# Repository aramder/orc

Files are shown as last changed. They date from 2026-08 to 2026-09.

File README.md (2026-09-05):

<div align="center">

<picture>
  <source media="(prefers-color-scheme: dark)" srcset="docs/media/banner-dark.svg">
  <source media="(prefers-color-scheme: light)" srcset="docs/media/banner-light.svg">
  ORC — Open Relay Controller
</picture>






**A replacement controller board for surplus Motorola PMUN1046A relay boxes — same relays and enclosure; open CAN control over plain terminal blocks instead of the proprietary wired link to the radio.**

Independent open-source project. Not affiliated with, endorsed by, or connected to Motorola Solutions, Inc. — see [TRADEMARKS.md](TRADEMARKS.md).

[**Project writeup and photos →**](https://aramd.net/PMUN1046A-Relay-Controller/)

**Safety:** this switches high-current DC in a vehicle. It is not safety qualified and must not be used for safety-critical functions. Read [DISCLAIMER.md](DISCLAIMER.md) before building anything.

</div>

---

## Why

The PMUN1046A **Universal Relay Controller (URC)** is a sealed 12 V automotive relay box — ten relay outputs at 15 A each, per-channel fusing, and a busbar power input rated for up to two cables at 60 A each (Motorola's install manual), in a trunnion-mounted weatherproof chassis. Power goes straight to the busbar through cable glands — no special harness needed on the input side. Surplus units are common and cheap. Everything about it is desirable *except* that it only takes commands from a Motorola APX radio over a proprietary GCAI/USB link.

ORC replaces the controller board outright and makes the box a general-purpose, openly-controlled ten-channel power distribution module. **ORC** stands for Open Relay Controller.

ORC does not implement, emulate, or interoperate with the GCAI link. The controller board is an independent design that replaces the donor unit's controller board entirely; control is plain CAN or USB.

<details>
<summary><b>About the donor unit</b> (PMUN1046A Universal Relay Controller)</summary>
<br>

Motorola's URC ships as part of the APX mobile radio ecosystem — a sealed relay box meant to switch scene lighting, sirens, and other accessory loads from the radio head. The relay board and chassis are generic 12 V automotive gear; only the controller board and its proprietary GCAI/USB command link to the radio are Motorola-specific. The relay board is entirely passive (relays, fuses, terminal blocks, busbar — no drivers or regulator of its own); a small internal harness carries switched 9 V coil drive between it and the controller board. Power input has no special harness at all — it lands straight on the busbar through the enclosure's cable glands. ORC keeps the relay board and chassis, and replaces the controller board and its proprietary radio link with plain CAN over terminal blocks — no proprietary connector anywhere in this design.

</details>

## What it is

<table>
<tr>
<td width="50%" valign="top">

**Inherited from the donor unit**
- Ten switched channels, 15 A each
- Per-channel fusing + busbar
- Board-to-board coil-drive harness (P/N `0975931M01`) — the internal cable between the relay board and the controller board, carrying switched 9 V coil drive; *not* a power-input harness
- Sealed, trunnion-mounted chassis

</td>
<td width="50%" valign="top">

**Rebuilt on the new controller board**
- ESP32-C3 controller (native USB for programming only; CAN-exclusive control, no wireless)
- 9 V relay coil supply
- Ten relay driver stages
- CAN terminal blocks (no proprietary connector)

</td>
</tr>
</table>

Category-wise this is a **PDM** (power distribution module) — the sPOD / Switch-Pros class of device — with an open CAN control interface instead of a proprietary wired link to the radio.

## The board

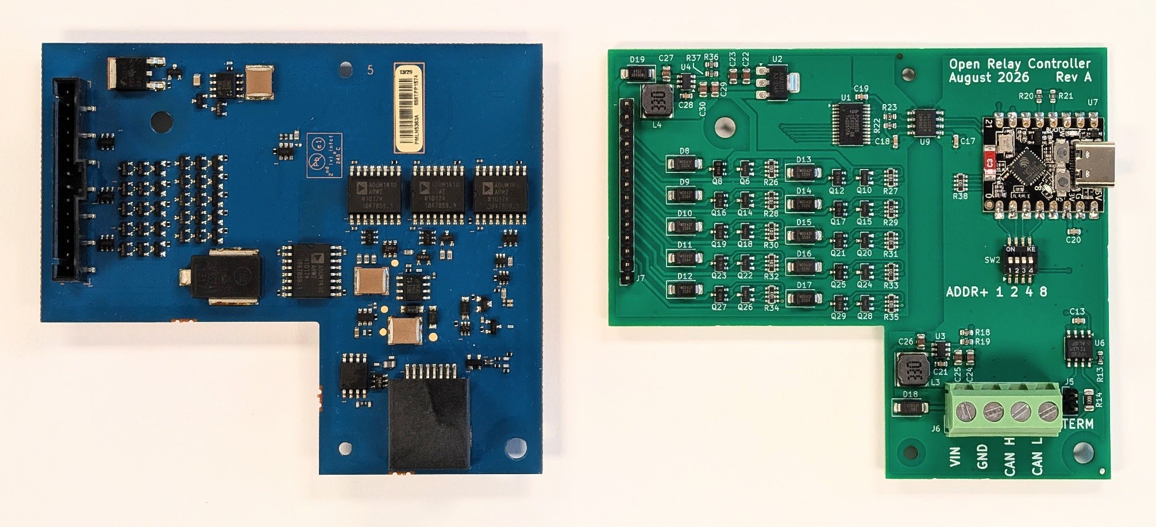
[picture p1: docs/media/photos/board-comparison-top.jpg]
ORC Rev A (green, right) next to the OEM PMUN1046A control PCB (blue, left), top-down


<em>ORC Rev A (green, right) and the OEM control PCB it replaces (blue, left).</em>

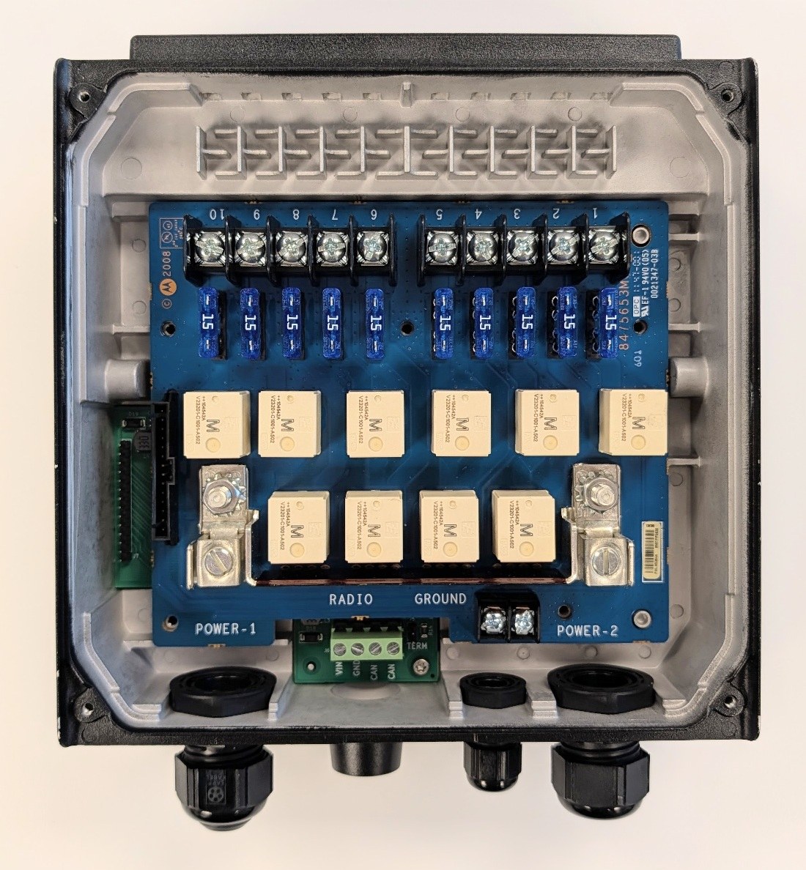
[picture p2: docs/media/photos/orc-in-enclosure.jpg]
ORC Rev A installed in the PMUN1046A enclosure alongside the OEM relay board


<em>ORC Rev A installed in the donor enclosure, alongside the OEM relay board that stays.</em>

**Full writeup, build story, and more photos:** [Open Relay Controller for the Motorola PMUN1046A](https://aramd.net/PMUN1046A-Relay-Controller/).

## Repo structure

One repo for design inputs, hardware, and firmware — no split-repo overhead for a project this size:

| Path | Contents | Status |
|---|---|---|
| `docs/` | Design inputs, specs, architecture decisions | Active |
| `hardware/` | KiCad project — schematic, PCB, BOM | Schematic captured, boards fabricated, populated, and bring-up verified on real hardware |
| `firmware/` | PlatformIO / Arduino firmware | `canopen_app` is real application firmware (CAN + USB relay control), verified on real hardware |
| `tools/` | Host-side CAN/USB bench test scripts | Used against real hardware |

## License

Different parts of the repo carry different licenses. Full texts are in [LICENSES/](LICENSES/); each directory also carries its own `LICENSE` file.

| Path | License |
|---|---|
| `hardware/` | [CERN-OHL-W-2.0](LICENSES/CERN-OHL-W-2.0.txt) |
| `firmware/`, `tools/` | [Apache-2.0](LICENSES/Apache-2.0.txt) |
| `docs/` | [CC-BY-4.0](LICENSES/CC-BY-4.0.txt) |

Hardware and software are licensed separately because they are separate works: under CERN-OHL's own definitions the ESP32-C3 is an Available Component, so a hardware license on the board does not reach the code running on it. See [NOTICE](NOTICE) for the summary and [TRADEMARKS.md](TRADEMARKS.md) for trademark and affiliation.

## Status

**Real-hardware bring-up complete.** Boards were sent to fab 2026-08-02, came back populated, and have been bench-tested since 2026-08-10: the PCA9555/I2C-isolator chain, the full 10-channel relay-driver mapping, and the CAN (RPDO1/TPDO1/TPDO2/Heartbeat) and USB control paths have all been exercised on real hardware. Five real firmware bugs were found and fixed along the way — BUG-001 through BUG-005, see [docs/features/LOG.md](docs/features/LOG.md) for the full history — the last of which (a liveness stall under an absent/unpowered PCA9555) was verified on real hardware 2026-09-04. One real mechanical fault (a harness connector shorting against the enclosure chassis) was also found and fixed on the bench — see [docs/circuit-draft.md](docs/circuit-draft.md) for the follow-up enclosure-clearance item.

No further active development is planned barring a new bug. A couple of feature requests (FR-003, FR-005) remain open in the backlog but aren't being actively pursued right now.

Working conventions for part selection, asset verification, and check gates: [docs/hardware-workflow.md](docs/hardware-workflow.md). Bench test tooling for talking to a real board over CAN/USB from a PC: [tools/](tools/).

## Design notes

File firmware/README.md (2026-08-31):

# ORC firmware

**Two kinds of content live here — don't conflate them.** The four `*_bringup`/`can_address_bringup` sketches exist to answer one narrow question — does the MCU pinout the hardware side has settled on actually work at the IO level? — before real application logic got written; see [`.claude/firmware-io-verification-prompt.md`](../.claude/firmware-io-verification-prompt.md) for that task. **`canopen_app` is different: it IS ORC's real application firmware** — actual relay control, driven from **either CAN or USB** against the same PCA9555 state, per [`docs/can-protocol-research.md`](../docs/can-protocol-research.md), [`docs/usb-bench-interface-spec.md`](../docs/usb-bench-interface-spec.md), and [`docs/features/FR-004.md`](../docs/features/FR-004.md). See its own section below.

**FR-004 (2026-08-10): USB control consolidated into `canopen_app`, the standalone `usb_bench` sketch retired.** Real bench testing the same day found `canopen_app`-only (CAN-only) and `usb_bench`-only (USB-only) too limiting for one board under active test with both interfaces in play — user's explicit ask: "I want to be able to drive from either CAN or USB interfaces." `usb_bench`'s protocol, findings, and fixes live on in `docs/features/FR-001.md` (marked superseded, not deleted) and in `canopen_app`'s own git history; there is no `[env:usb_bench]` anymore.

**Real ORC PCBs arrived and real-hardware testing started 2026-08-10.** Boards came back from fab, populated, and are being bench-tested for the first time. First real result, `i2c_scanner` on a powered, fully-wired ORC PCB: idle bus reads HIGH/HIGH (clean pull-ups, no strapping fault), CAN address bank correctly reads `0` with all four DIP switches open, and **the PCA9555 ACKs at 0x20** — the first-ever confirmation the ADuM1250 I2C isolator + PCA9555 chain works as designed on real fabricated hardware, not just static analysis. This also empirically confirms the GPIO2 boot-strap safety analysis (see "Configurable CAN node address, as-fabbed" below) for the DIP-switches-open position; the closed/HIGH position on GPIO2 hasn't been walked yet. SN65HVD230/real-CAN-bus testing hasn't happened yet as of this pass. **Still true for now**: don't read "runs on a generic ESP32-C3 dev kit" (below) as equivalent to "verified on the real ORC board" — but as of today, real-board testing is actively underway, replacing that caveat's earlier "no board in hand at all" state. Update this section as each sketch gets its first real-PCB run, don't leave it reading like nothing has changed once it has.

**History, for context**: the board was sent to fab 2026-08-02 and came back some time before this pass. All five firmware environments (`i2c_scanner`, `pca9555_bringup`, `uart_can_bringup`, `can_address_bringup`, `canopen_app`) build successfully against the `esp32-c3-devkitm-1` stand-in board. Two of them (`i2c_scanner`, `uart_can_bringup`) also ran live on a bare, generic ESP32-C3 dev kit before any ORC PCB existed — see "Real-hardware run, 2026-08-01" below for exactly what that did and didn't confirm (nothing PCA9555/SN65HVD230-related). `canopen_app` (as `usb_bench` too, before it was retired into `canopen_app` by FR-004) found and fixed a real bug (halting `setup()` before relay-agnostic functionality ACKed, taking bus-agnostic functionality down with it — BUG-001) on a bare devkit before any ORC PCB was available. **Firmware's pin assignment was corrected once, same day it was sent to fab** — see "CAN node address, as-fabbed" below; the schematic is the source of truth firmware must match, not the other way around.

## Board stand-in

`platformio.ini` targets PlatformIO's `esp32-c3-devkitm-1` board definition. This is a **stand-in**, not the final hardware — the actual target is a generic, widely-cloned "ESP32-C3 Super Mini"-class board (bare ESP32-C3FN4 die, 4MB flash, no PSRAM, USB-C, 2×7-pin THT headers) with no single confirmed SKU yet. `esp32-c3-devkitm-1` is electrically close enough (same chip class) to compile and flash against for IO-level bring-up; swap it for a real board definition once a specific listing is bought and its exact silkscreen/pin breakout is confirmed.

## Pin assignment under test

Per `hardware/mcu.kicad_sch` (U7, as-fabbed) and `docs/subcircuit-capture-guide.md`'s MCU section — full 13-GPIO "Super Mini" header pinout (GPIO0-10, GPIO20, GPIO21):

| Function | Pins |
|---|---|
| I2C (SDA/SCL) | GPIO8 / GPIO9 |
| UART (TX/RX, to SN65HVD230) | GPIO21 / GPIO20 |
| CAN node address (NODE_ID0-3) | GPIO0 / GPIO1 / GPIO2 / GPIO3 |
| Spare (unused) | GPIO4-7 (JTAG-default), GPIO10 |

## Configurable CAN node address, as-fabbed

4-bit node address (0-15), read directly by the ESP32-C3 — deliberately **not** through the PCA9555, since address-select logic belongs on the MCU's own non-isolated Domain A side, not across the ADuM1250 isolation barrier onto Domain B where the PCA9555 lives. Shared logic lives in `lib/orc_can_addr/` and is linked into every sketch below, each printing the current reading at startup.

**Wiring**: external 10kΩ pulldown to GND per bit, switch/jumper to 3V3 per bit — open=0 (LOW), closed=1 (HIGH). Plain `INPUT` mode in firmware (no internal pull requested); the external 10k dominates the ESP32-C3's own internal weak pull resistors (~45kΩ typ either direction per the datasheet) regardless of their state, so there's nothing to fight.

**Pins actually built: GPIO0, GPIO1, GPIO2, GPIO3 — corrected after the fact, not the original plan.** The initial pick (documented 2026-08-02, before the board went to fab) was GPIO0/1/3/10, specifically chosen to avoid GPIO2 since it's one of the ESP32-C3's three strapping pins. **That was never what got built.** The as-fabbed schematic (`hardware/mcu.kicad_sch`, U7) wires `NODE_ID0`..`NODE_ID3` to a contiguous `IO0`..`IO3` block — which includes GPIO2 and doesn't use GPIO10 at all. This firmware has been corrected to match the real board; the schematic is the source of truth here, not the firmware plan.

**GPIO2 strapping safety — re-verified with real rigor since it's now load-bearing on a board that's already at fab, not just a design preference to weigh.** The ESP32-C3's full strapping-pin set is exactly {GPIO2, GPIO8, GPIO9} (Espressif *ESP32-C3 Series Datasheet* v2.4, Table 3-1/3-2/3-3). Table 3-3 "Chip Boot Mode Control" has exactly two rows:

| Boot Mode | GPIO2 | GPIO8 | GPIO9 |
|---|---|---|---|
| SPI Boot (normal) | Any value | Any value | 1 |
| Joint Download Boot | 1 | 1 | 0 |

— with the table's own footnote stating plainly: *"GPIO2 actually does not determine SPI Boot and Joint Download Boot mode, but it is recommended to pull this pin up due to glitches."* This board's I2C pull-up (R21, `SCL_A`, 10kΩ — see `docs/subcircuit-capture-guide.md`'s I2C Isolator section) holds **GPIO9 = 1 at every reset**, which is the sole determinant of the SPI-Boot row. Both address-switch positions on GPIO2 (LOW via the external 10k pulldown when open, HIGH when closed) land in that same SPI-Boot row regardless — GPIO2's column is "Any value" whenever GPIO9=1, and GPIO9=1 is guaranteed here. No published ESP32-C3 errata mention GPIO2 (checked directly against Espressif's chip errata index, not assumed absent by analogy to GPIO8/9). **Verdict: safe as fabbed, no rework needed.** Espressif's own generic recommendation to add a pull-up on GPIO2 (to guard against glitches on a *floating* GPIO2 in designs where GPIO9 isn't independently pinned) doesn't apply here in the same way, since this design's own pull-down plus GPIO9's independent pull-up together determine the outcome regardless of GPIO2's transient state.

GPIO0/1/3 are also ADC1_CH0/CH1/CH3 — irrelevant here since they're used purely as digital inputs, not sampled by the ADC. GPIO10, spare in this design, was the original plan's bit3 pin but isn't actually wired to anything address-related on the real board.

## The GPIO9 strapping question — resolved

GPIO9 is the ESP32-C3's BOOT strapping pin (default weak pull-up = normal SPI-flash boot) and is also assigned as I2C SCL. **Datasheet analysis verdict: safe, no conflict.** Full reasoning and citations now live in `docs/subcircuit-capture-guide.md`'s MCU section; summary:

- The boot-strap read is a one-shot latch completing within a fixed **t_H ≥ 3 ms** window anchored to `CHIP_EN` release (Espressif *ESP32-C3 Series Datasheet* v2.4, §3, Table 3-2, Figure 3-1) — before firmware runs and before the IO MUX/GPIO Matrix has routed the I2C peripheral onto GPIO8/9 at all (same datasheet, §4.1.3.1; Table 2-1 shows GPIO9's at-reset/after-reset state as plain `IE, WPU`, not an I2C pin).
- An idle-high I2C bus **reinforces** GPIO9's documented default pulled-up strap value (Table 3-1: GPIO9 default = weak pull-up, bit=1=SPI boot); external pull-ups are the datasheet's own documented mechanism for setting strap state and are not flagged as a hazard when they match the default direction.
- The only way to disturb the strap read is to actively drive GPIO9 **low** during the ~3 ms window — ordinary I2C only pulls SCL low during active clock pulses initiated by firmware, which cannot run before the strap read has already completed and been latched.
- No published ESP32-C3 errata mentions GPIO8/GPIO9/strapping/I2C (checked against Espressif's official chip errata index).
- GPIO8 (SDA) is also a strapping pin (chip-boot-mode + UART-print-control), defaults to **floating** (not pulled), and is safe by the same timing argument. One real caveat carried into the docs: GPIO8's floating default means if some other I2C slave on the bus holds SDA low during its own power-on reset at the same instant as the ESP32-C3's `CHIP_EN` release, that could unintentionally affect the GPIO8 strap read (Table 3-3: only matters if GPIO9 also reads 0 at that instant) — a general I2C power-sequencing caution, not specific to this design, and not a reason to reassign pins.

No pin reassignment was made. If a strapping-pin-free I2C pair is ever wanted for unrelated reasons, GPIO4/5 or GPIO6/7 avoid the {GPIO2, GPIO8, GPIO9} strap set but carry JTAG (MTMS/MTDI/MTCK/MTDO) as their IO-MUX default association — a different caution category, and not verified against this design's specific "Super Mini" header breakout.

## SN65HVD230 UART baud rate

The SN65HVD230 CAN transceiver has **no UART framing requirement of its own** — it's a transparent ISO 11898-2 physical-layer line driver, not a UART part (TI *SN65HVD230/1/2* datasheet, SLOS346O, rev. April 2018: §7 Pin Functions, §10.1 Overview). Its datasheet gives a "designed for data rates up to 1 Mbps" target (Features, p.1) and hard propagation-delay/rise-time limits in high-speed mode (§8.7–8.9, tens-to-~135 ns depending on the parameter) — not a baud spec. `uart_can_bringup` picks 500 kbps as a conventional round number comfortably under that ceiling; it is a firmware-side choice, not a transceiver requirement. **Caveat**: those propagation-delay numbers assume RS (slope-control) tied to ground for high-speed mode — if ORC's board leaves RS in slope-control mode via a resistor instead, propagation delay balloons (up to ~1200 ns typ at 100 kΩ RS per the datasheet's switching-characteristics table) and would cap the practical rate well below 1 Mbps. Confirm ORC's actual RS pin configuration before assuming the 1 Mbps ceiling applies.

## Real-hardware run, 2026-08-01

A bare, generic ESP32-C3 dev kit (chip ID reported by `esptool`: **ESP32-C3 QFN32, silicon revision v0.4**, 4MB embedded flash, native USB-Serial/JTAG, MAC `3c:84:27:af:48:fc`) was connected to the machine this session ran on, with **nothing else wired to it** — no PCA9555, no SN65HVD230, no I2C pull-ups beyond whatever the bare board itself has. This is not ORC's board and does not exercise the PCA9555 or CAN-transceiver bring-up logic; it confirms the ESP32-C3 IO-level pieces (I2C peripheral init, UART peripheral init, USB console) actually run on real silicon of the correct chip family.

**Bug found and fixed by this test, not cosmetic**: the stock `esp32-c3-devkitm-1` board definition does not enable USB-CDC-on-boot, so Arduino's default `Serial` console silently bound to UART0 on **GPIO21(TX)/GPIO20(RX) — the exact pins this design assigns to the CAN-transceiver UART** — instead of the native USB-Serial/JTAG port. First flash produced zero console output for this reason. Fixed in `platformio.ini` with `-D ARDUINO_USB_MODE=1 -D ARDUINO_USB_CDC_ON_BOOT=1`, which routes `Serial` onto native USB and frees GPIO21/20 exclusively for the CAN UART (`Serial1`) as intended. Worth carrying into whatever final board definition replaces the `esp32-c3-devkitm-1` stand-in — the same collision would otherwise resurface silently on real ORC hardware.

- **`i2c_scanner`**: flashed and ran live. Correctly reported no ACKs on the bus (expected — nothing is wired to GPIO8/9 on this bare dev kit) and printed the idle-bus-level check without error. Confirms the I2C peripheral initializes and runs on real hardware; does not confirm anything about the PCA9555 (not attached).
- **`uart_can_bringup`**: flashed and ran live. Baseline (nothing jumpered) correctly showed "RX: nothing received" every cycle. With GPIO21 (TX) physically shorted to GPIO20 (RX) by a jumper wire, **loopback verified end-to-end**: every `ORC-BRINGUP-<counter>` pattern sent came back byte-for-byte (22 bytes including `\r\n`), one-to-one, no drops or corruption, at 500 kbps. Confirms UART1 on these exact pins transmits and receives correctly on real silicon; does not confirm anything about the SN65HVD230 or a real CAN bus (neither present).
- **`pca9555_bringup`**: not run this session — no PCA9555 is attached to this dev kit. By design it halts cleanly at the "PCA9555 did not ACK" check rather than doing anything unsafe without the part present; still only build-verified, not run.

## Real-hardware run, 2026-08-10 — first test against an actual ORC PCB

Real, populated, powered ORC PCBs are in hand as of this pass — the first real-hardware test against the design this whole directory has been targeting, not a bare devkit stand-in. First board wired up and tested via `i2c_scanner`, flashed to a bare ESP32-C3 module wired to the board (COM7, `esptool`-reported chip ID: ESP32-C3 QFN32 silicon revision v0.4, MAC `AC:27:6E:45:90:98` — a different unit than the 2026-08-01 run's `3c:84:27:af:48:fc`).

Live boot output:

```
=== ORC bring-up: I2C bus scanner ===
SDA=GPIO8  SCL=GPIO9  expected PCA9555 addr=0x20
CAN node address: 0 (bits 3210 = 0000, pins GPIO3/2/1/0)
Idle bus levels before Wire.begin(): SDA(GPIO8)=HIGH  SCL(GPIO9)=HIGH
Both lines read HIGH at idle -- normal.

Scanning I2C bus (addresses 0x03-0x77)...
  ACK at 0x20  <-- expected PCA9555 address
1 device(s) found.
```

**Confirms, for the first time on real fabricated hardware, not static analysis or a bare-devkit substitute**:
- **PCA9555 ACKs at 0x20.** The ADuM1250 I2C isolator + PCA9555 chain works as designed, crossing the Domain A/B isolation barrier for real.
- **GPIO2 boot-strap safety, empirically confirmed for the DIP-switches-open position**: bus idles HIGH/HIGH, board boots and runs normally with GPIO2 (a strapping pin) held at its address-bank LOW/open state. This is the predicted-safe outcome from the Table 3-3 datasheet analysis (see "Configurable CAN node address, as-fabbed" below), now observed on real silicon instead of just argued from the datasheet. **Not yet walked**: the CLOSED/HIGH position on GPIO2 specifically — the analysis says it lands in the same safe boot-mode row, but that position hasn't been physically tested yet.
- **CAN node address bank reads correctly**: `0` with all four DIP switches open, matching the external-pulldown design (open = LOW = 0).

**`pca9555_bringup` confirmed shortly after, same session**: flashed to the same board, ran its full 10-channel walking pattern, user cross-checked every channel with a DMM in continuity mode on the coil harness pins — all 10 correct, no swaps, no misses. First end-to-end confirmation of the routing-driven channel-mapping table (schematic → `orc_relay_map.h` → real silicon → real coil driver → real relay) on actual hardware, not just internal firmware/schematic consistency. Full writeup: `pca9555_bringup`'s own section below.

**Real hardware fault found and fixed, same session — mechanical, not electrical design.** A second board (or second connection session) showed relays only weakly actuating (faint click, not enough force to close contacts) and I2C throwing driver-level errors partway through the run. Chased through several hypotheses (PCA9555 brownout-reset from coil inrush, then a wedged I2C bus) before the user found the real cause by physical inspection: **the harness connector's unshrouded THT pins were shorting against the metal enclosure chassis.** One electrical fault, two symptoms — the short sagged shared supply rail(s) under coil-switching current, starving coil drive and glitching the PCA9555's own logic supply at the same time. Not a coil-supply sizing problem, not a firmware bug. Full writeup and the follow-up mechanical-clearance item: `docs/circuit-draft.md`'s "Harness connector — measured pinout" section. `pca9555_bringup`'s own periodic-PCA9555-reconfigure defensive hardening (added while chasing this) stayed in as cheap insurance; an I2C bus-recovery attempt added at the same time was tested live, found not to actually work on this Arduino-ESP32 core's I2C driver, and removed rather than left in as broken code claiming success — see the sketch's own comments for the full chase.

**FR-004, same session, later**: user asked for USB control to be built into `canopen_app` itself rather than living only in the separate `usb_bench` sketch, so relays could be driven from either interface against the same board. `usb_bench` retired; its protocol/fixes consolidated into `canopen_app` — see that section below and `docs/features/FR-004.md`. `canopen_app` (with USB now built in) then drove all 10 channels ON over USB directly on this real board: real coil current confirmed (0.47A at 12V input, matching the ~0.45A design target almost exactly), all 10 relays audibly/visibly actuated. One test-tooling false alarm along the way, not a firmware bug: a Python test script's `pyserial.Serial.close()` call toggled the native-USB-CDC auto-reset lines (the same RTS mechanism `esptool` uses for flashing) and rebooted the chip, which looked like "the relays turned off after ~1 second" but was actually a full reset wiping all state back to boot defaults — confirmed by re-running the same test with the port kept open for 15+ seconds: heartbeat counted up smoothly the whole time, zero reboots, all 10 channels held.

**`canopen_app` CAN side, tested and a real bug found and fixed, 2026-08-10.** Bench-tested end-to-end against real hardware (real ORC board, Jhoinrch RH-02 USB-CAN adapter, `tools/relay_toggle_test.py`'s 1-10 sweep + all-on): the RPDO1 command path worked correctly from the first run (relays physically confirmed clicking through in sequence), but TPDO1 confirmation was unreliable in a specific pattern — roughly every other TPDO1 missing, survivors reporting the previous step's mask. Root cause, found by reading the Arduino-ESP32 native-USB-CDC (`HWCDC`) driver source directly, not assumed: `handleRpdo1()` logs the incoming RPDO1 via `Serial.printf()` *before* `applyRelayCommand()` sends TPDO1, and a blocking native-USB write can stall up to ~2000ms (20 retries × 100ms default `tx_timeout_ms`) if the physical USB link is up but nothing drains the ring buffer — longer than the test's 2s confirm window, and nothing to do with CAN bus health (a bus-health theory was tested first and directly refuted: TEC held at 0 for 10+ seconds through a full sweep, termination confirmed correctly populated, symptom unchanged). Fix: `setup()` now calls `Serial.setTxTimeoutMs(20)`, bounding any blocking `Serial` write to ~200ms. Re-verified against the reflashed board: 12/12 sweep steps confirmed. Full investigation trail: `.claude/tpdo1-lag-investigation-prompt.md` (gitignored, local only).

`uart_can_bringup` itself has not been separately re-run against this same setup — `canopen_app` (the real application firmware) has now been validated on both CAN and USB against real hardware, `uart_can_bringup` (an earlier bring-up-only sketch) is superseded for that purpose.

## Sketches

Each sketch is its own PlatformIO environment (separate, individually-flashable — not one monolithic test). Build/flash one at a time:

```
pio run -e i2c_scanner -t upload -t monitor
pio run -e pca9555_bringup -t upload -t monitor
pio run -e uart_can_bringup -t upload -t monitor
pio run -e can_address_bringup -t upload -t monitor
pio run -e canopen_app -t upload -t monitor
```

(Run from this `firmware/` directory. `-t monitor` opens the serial console at 115200 baud after flashing; omit it to just build+flash.)

### `i2c_scanner` ([src/i2c_scanner/main.cpp](src/i2c_scanner/main.cpp))

Scans the I2C bus (addresses 0x03–0x77), reports any device that ACKs — specifically flags 0x20, the PCA9555's address (A0–A2 strapped low). Before starting the I2C peripheral, reads SDA/SCL as plain GPIO to report whether the bus idles HIGH (normal) or LOW (a real fault — stuck bus, missing pull-up, or a device holding the line; the classic symptom anyone chasing a strapping-conflict theory would look for, though per the analysis above it isn't expected to be one here).

### `pca9555_bringup` ([src/pca9555_bringup/main.cpp](src/pca9555_bringup/main.cpp))

Configures the PCA9555 as 10 outputs and walks a single HIGH bit across channels 1–10 in sequence, 500 ms per step, using the **real, schematic-confirmed channel-to-register mapping** in `lib/orc_relay_map/`. Intended for a scope probe or a per-channel LED jig to visually confirm addressing and pin mapping once hardware exists. **Corrected 2026-08-05**: an earlier version of this sketch assumed channels 1-8 were sequential on Port0 (whole byte) with channels 9-10 on Port1's low 2 bits — that assumption was wrong. `docs/subcircuit-capture-guide.md`'s "Channel mapping" table (read directly off `hardware/i2c_expander.kicad_sch`) shows the real mapping is routing-driven and non-sequential, spanning both ports (e.g. channel 1 = Port1 bit0, channel 2 = Port0 bit7, channel 10 = Port0 bit3). "Channel 3" in this sketch's output now means the schematic's actual channel 3.

**Real-hardware confirmed, 2026-08-10**: flashed to a real, powered ORC PCB and run through its full walking pattern. User followed along with a DMM in continuity mode on the coil harness pins and confirmed all 10 channels click in the correct physical position, matching the printed `Channel N HIGH` output exactly — no swaps, no misses. This is the strongest verification the channel-mapping table has had: schematic → `orc_relay_map.h` → real silicon → real coil driver stage → real relay, checked end to end. Full writeup: `docs/subcircuit-capture-guide.md`'s "Channel mapping" section.

### `uart_can_bringup` ([src/uart_can_bringup/main.cpp](src/uart_can_bringup/main.cpp))

Configures UART1 at 500 kbps on GPIO21(TX)/GPIO20(RX) — the pins wired to the SN65HVD230 — sends a counted test pattern (`ORC-BRINGUP-<counter>`) once per second, and reports whatever arrives on RX within a 500 ms window. Useful for a bench loopback test (jumper TX to RX, or through the transceiver with CAN_H/CAN_L looped/terminated) before a real bus exists, and for testing against a second node once one does. This is raw UART bytes through the transceiver, not CAN-protocol-framed traffic.

### `can_address_bringup` ([src/can_address_bringup/main.cpp](src/can_address_bringup/main.cpp))

Reads the 4-bit CAN-address bank (GPIO0/1/2/3, see "Configurable CAN node address, as-fabbed" above) and prints the resulting 0-15 value once per second, along with each individual bit. Intended for a bench check: walk all 16 switch combinations and confirm each one reads back correctly before trusting the scheme in the field. The other bring-up sketches also call the same `orcPrintCanAddress()` helper (from `lib/orc_can_addr/`) once at startup, so whichever one is running, the console banner always states which node address the board is currently set to — useful as soon as more than one ORC unit might be on a bench or bus at once.

## `canopen_app` — application firmware: relay control from CAN or USB

**This is real relay-control firmware, not a bring-up test.** Implements the full CAN protocol specified in `docs/can-protocol-research.md`: real CAN (TWAI, not the `uart_can_bringup` UART scheme), 125 kbit/s, node-ID-based addressing (reuses `lib/orc_can_addr` unchanged), and four messages — RPDO1 (relay command), TPDO1 (relay status), TPDO2 (bus health/uptime), Heartbeat — plus one minimal SDO object for TPDO2's configurable send interval. **FR-004 (2026-08-10) added a second, equally real control path**: the same plain-ASCII USB protocol `docs/usb-bench-interface-spec.md` defines, previously its own separate `usb_bench` sketch (now retired) — `PING`/`VERSION`/`SET`/`GET`/`STATUS` plus unsolicited `HB`/`STATE` lines, driving the *same* PCA9555 state as CAN does. Real ORC boards are in hand and under active bench test as of 2026-08-10 (see the top status note above) — this firmware found and fixed a real-hardware bug (BUG-001, same halt-on-missing-PCA9555 class `usb_bench`'s FR-001 also hit) on a bare devkit before an ORC PCB was available, and has since driven all 10 real relays over USB on the real board (0.47A real coil current, matching the ~0.45A design target).

```
pio run -e canopen_app -t upload -t monitor
```

**Transport**: ESP-IDF/Arduino-ESP32's native TWAI driver (`driver/twai.h`), `tx_io=GPIO21`, `rx_io=GPIO20` — the same physical pins `uart_can_bringup` uses, but a genuinely different on-chip peripheral (TWAI vs UART1), per `can-protocol-research.md`'s UART-vs-TWAI resolution: TWAI has no dedicated IO_MUX pin on the ESP32-C3, it's GPIO-Matrix-routable to any pin, so this is a firmware-only change with zero schematic impact. Given separate `ORC_TWAI_TX_PIN`/`ORC_TWAI_RX_PIN` build flags (same values as `ORC_UART_TX_PIN`/`RX_PIN`) rather than reusing the UART-named constants, since reusing them here would misleadingly suggest this sketch is still UART-based. **Bitrate: 125 kbit/s, locked** (`TWAI_TIMING_CONFIG_125KBITS()`) — per `can-protocol-research.md`'s "Bus bitrate" section; don't change this without updating that doc and coordinating with `rigos-core`'s FR-059, which is being built against this exact value from the host side.

**Node ID**: read via `lib/orc_can_addr` at startup, unchanged from the bring-up sketches. **If the address reads 0** (all 4 DIP-switch positions open — not a valid CANopen node ID, CiA 301 requires 1-127), CAN is disabled for that session (no heartbeat, TPDO1/TPDO2, RPDO1, or SDO) rather than silently joining the bus non-conformantly — **but the sketch keeps running and USB control still works normally**, per FR-004's proactive fix (see below): a missing node ID used to halt the *entire* sketch before this pass, which would have taken USB down with it too, defeating the whole point of having two independent interfaces.

**Messages implemented** (COB-ID = base + NodeID, see `can-protocol-research.md` for the full spec):

| Message | COB-ID | Direction | What it does |
|---|---|---|---|
| RPDO1 | `0x200+NodeID` | host → ORC | 2-byte relay command (byte0=channels 1-8, byte1 bits0-1=channels 9-10) — this is the **wire protocol's** channel numbering, translated to real PCA9555 register bits via `lib/orc_relay_map/`'s schematic-confirmed, routing-driven mapping (channels are NOT sequential Port0-then-Port1 bits — see `pca9555_bringup`'s section above for the same correction). `orc_canopen.h` only handles the 2-byte-payload ↔ 10-bit-channel-mask conversion; `orc_relay_map.h` handles channel-mask ↔ PCA9555-register-value, kept as two separate, composable translation steps. |
| TPDO1 | `0x180+NodeID` | ORC → host | 2-byte applied relay status, sent after **any** real applied-state change — not only ones RPDO1 itself caused (FR-004: a USB `SET` command now also triggers a TPDO1 broadcast, so a CAN listener's view of applied state stays truthful regardless of which interface changed it). Read back from the PCA9555's Input Port registers (which reflect actual driven pin level even for output-configured pins) rather than just echoing the command — real command-vs-applied confirmation, even without current sensing. |
| TPDO2 | `0x280+NodeID` | ORC → host, periodic (default 1000ms, SDO-configurable) | 8-byte bus health/uptime: byte0 CAN-controller-health enum, bytes1-2 TWAI TX/RX error counters, bytes3-6 uptime-seconds (`uint32` little-endian), **byte7 relay-hardware fault bitmask (FR-002, 2026-08-31 — bit0 = PCA9555 absent/unpowered, mirrors `g_pca9555Present`; was reserved/always-0 before this)**. Byte-0 enum and error-counter width were both flagged in `can-protocol-research.md` as unverified design sketches — **both confirmed this pass against ESP-IDF's actual `driver/twai.h`** (see that doc's TPDO2 section for the citation), implemented in `lib/orc_canopen/orc_canopen.h`. **Uptime bug found and fixed in 2026-08-05 review**: the field was originally computed from `millis()`, which wraps at ~49.7 days and would have silently reset the reported uptime on any continuously-powered unit — now uses `esp_timer_get_time()` (64-bit microseconds-since-boot), which doesn't have that problem. |
| Heartbeat | `0x700+NodeID` | ORC → host, periodic, fixed 1000ms | 1-byte NMT state. Sends Boot-up (0) once at the end of `setup()`, then Operational (5) on every subsequent periodic send — a fixed "Boot-up once, then always Operational" NMT posture, no Stopped/Pre-operational transitions implemented, stated explicitly rather than silently skipped. |
| SDO (minimal) | rx `0x600+NodeID`, tx `0x580+NodeID` | host ↔ ORC | Recognizes exactly one (index, sub-index) pair — `1801h`/`5`, TPDO2's event timer in milliseconds — and aborts (standard CiA 301 abort codes) anything else. Not a general SDO server, per the task's explicit scope. A successful write applies the new interval immediately and persists it to the ESP32-C3's NVS (`Preferences`, namespace `orc_cfg`, key `tpdo2_ms`) so it survives a power cycle; default 1000ms if nothing's been persisted yet. |

**Control-activity fail-safe, now unified across both interfaces (FR-004)**: if neither CAN (RPDO1) nor USB (any command) produces real activity within a threshold, all channels are de-energized rather than holding last state — per `can-protocol-research.md`'s explicit safety recommendation, now extended to cover USB too. **Two thresholds, not one, and picked by which interface was most recently active, not a single shared clock**: 5000ms after CAN activity (the original RPDO1-timeout value — not a cited spec value, picked as 5x the TPDO2/Heartbeat default period), 30000ms after USB activity (ported from `usb_bench`/FR-001's own reasoning — a human typing pauses far longer than a machine's command cadence). A naive single shared last-activity timestamp checked against both thresholds does NOT correctly implement "either interface's activity postpones both" — since 5000 < 30000, the shorter threshold always fires first on a shared clock, making the 30s USB grace period unreachable dead code. Tracking *which* interface supplied the most recent activity and selecting the threshold from that avoids this: a pure-CAN session keeps the strict 5s fail-safe, a pure-USB session gets the full 30s grace, and either interface's activity postpones the other's countdown. See `docs/features/FR-004.md` for the full reasoning.

**TWAI bus-off recovery**: added in the 2026-08-05 review pass — was missing entirely from the original implementation. ESP-IDF's TWAI driver does not recover from bus-off on its own: `twai_initiate_recovery()` must be called explicitly, and even after recovery completes the driver lands in `STOPPED`, not `RUNNING` — `twai_start()` must be called again to actually resume. Without this, a bus fault would be correctly *reported* via TPDO2's health byte (`BUS_OFF`/`RECOVERING`) but never actually recovered from, needing a physical power-cycle. `checkTwaiRecovery()` runs on a fixed 1-second cadence (independent of TPDO2's own SDO-configurable interval, deliberately) and handles both the `twai_initiate_recovery()` call and the follow-up `twai_start()`.

**Not implemented, by explicit scope choice, not oversight**: EMCY (`0x080+NodeID`) — flagged in the spec as a stretch goal, skipped this pass. Full `1010h`/`1011h` CANopen store/restore objects — the NVS auto-persist-on-write above satisfies "survives a power cycle" without them; a reasonable later addition if ORC ever needs to interoperate with a generic CANopen config tool expecting the standard mechanism specifically. No general-purpose CANopen stack or object dictionary — the message set is small and fully specified, hand-rolled directly on the TWAI driver per the task's explicit instruction not to pull in a library (e.g. CANopenNode) for this.

**Shared libraries**: `lib/orc_canopen/orc_canopen.h` — pure wire-protocol encode/decode helpers (COB-ID arithmetic, RPDO1/TPDO1 2-byte-payload ↔ 10-bit-channel-mask, TPDO2 payload packing, the one-object SDO wire format). `lib/orc_relay_map/orc_relay_map.h` — the real, schematic-confirmed channel-mask ↔ PCA9555-register-value mapping, shared with `pca9555_bringup` (see its section above). Splitting these two translation steps (protocol bytes ↔ channel mask, channel mask ↔ PCA9555 registers) into separate libs is deliberate — it's what let the routing-driven mapping bug get caught and fixed in one place without touching the wire-protocol format at all. Neither lib makes TWAI/I2C/NVS calls of its own; `canopen_app/main.cpp` owns the actual peripherals and runtime loop. Both header-only, no `.cpp` — everything's a small `inline` function.

### USB control (FR-004, formerly the standalone `usb_bench` sketch)

Same physical native USB-C port already wired for flashing, same plain-ASCII protocol `docs/usb-bench-interface-spec.md` defines — **now built into `canopen_app` directly**, driving the same PCA9555 state CAN does, not a separate binary. ORC's resolved control-path decision (`docs/design-inputs.md`) — CAN, exclusively, in the field — is unchanged; USB remains explicitly a bench/dev interface, just one that now lives in the real firmware instead of a throwaway sketch.

**Transport/framing**: native USB CDC-ACM (`Serial`), same `ARDUINO_USB_MODE`/`ARDUINO_USB_CDC_ON_BOOT` build flags every sketch here sets. Plain ASCII, one command/response per line, `\n`-terminated (`\r` tolerated/stripped), 128-byte max line length (`ERR LINE_TOO_LONG` past that), case-insensitive commands. Point-to-point by construction — no NodeID concept on the USB side, unlike CAN.

**Commands** (exactly per the spec):

| Command | Response | Notes |
|---|---|---|
| `PING` | `PONG <fw_version>` | Liveness + identify. Works even with CAN unjoined or no PCA9555 present. |
| `VERSION` | `VERSION <fw_version> <build_date>` | Fuller build info. |
| `SET <ch> ON\|OFF` | `OK SET <ch> ON\|OFF` or `ERR <code>` | `<ch>` is 1-10. Goes through the same `applyRelayCommand()` RPDO1 uses — a CAN listener sees a TPDO1 for this too. |
| `GET <ch>` | `STATE <ch> ON\|OFF` or `ERR <code>` | Applied state, PCA9555 Input Port read-back, not an echo of the last command. |
| `STATUS` | `STATUS <10-char 0/1 string>` | Channel 1 first, e.g. `STATUS 0010000000` = channel 3 on. |

**Unsolicited lines**: `HB <uptime_ms>` every 1000ms (always, regardless of whether CAN is joined); `STATE <ch> ON\|OFF` on every real applied-state change from *either* interface (CAN RPDO1, USB SET, or the fail-safe) — one shared read-back feeds both this and CAN's TPDO1 broadcast, so neither interface's view of reality can silently drift from the other's.

`SET`/`GET`/`STATUS` attempt a lazy on-demand PCA9555 re-probe if hardware wasn't previously known-present (ported from `usb_bench`/FR-001), returning `ERR NO_RELAY_HARDWARE` only if that also fails — same treatment `handleRpdo1()` now gets too, which it didn't have before this consolidation (BUG-001 only stopped it from halting the whole sketch, it never re-probed after boot).

**Known limitation, documented not silently accepted (FR-004)**: this file's Serial output was always a human debug log (RPDO1 dumps, TWAI errors, SDO writes, etc.), not the strictly line-clean protocol `usb_bench` alone was. That debug prose is now interleaved with the real protocol lines on the same port — a host-side parser MUST tolerate/ignore unrecognized lines, extending the spec's existing "check first token" robustness requirement to cover diagnostic prose too, not only other protocol lines.

**Real-hardware gotcha, not an ORC feature**: closing a serial connection (e.g. `pyserial`'s `Serial.close()`) can toggle the DTR/RTS lines the native-USB-CDC auto-reset mechanism watches — the same one `esptool` uses to flash without a physical BOOT button — and trigger a full chip reboot, wiping all state including energized relays. Confirmed live 2026-08-10: a test script's port-close looked exactly like "relays turned off after ~1 second," but a 15-second open-port re-test with the same commands showed zero reboots and all channels holding the whole time. Any host-side driver against this interface should keep the port open for its session, not open/close per command.

**Retired, not deleted**: the standalone `usb_bench` sketch/environment. Its full history — the FR-001 reopen, the PCA9555-gate bug, the fix, the real-hardware re-verification — lives in `docs/features/FR-001.md` (marked superseded) and this repo's git history, not silently erased.

## What this is not

- **The four bring-up sketches** (`i2c_scanner`, `pca9555_bringup`, `uart_can_bringup`, `can_address_bringup`) are not application firmware — no relay control logic, no real CAN message parsing/handling, no product behavior. `canopen_app` is different — see its section above — but that's not a claim of hardware verification (next point).
- **Updated 2026-08-10 — real ORC boards exist now, status per sketch**: `i2c_scanner` and `pca9555_bringup` have both run live on a real, powered, fully-wired ORC PCB. `i2c_scanner`: PCA9555 ACKed at 0x20, idle bus HIGH/HIGH, CAN address bank read correctly. `pca9555_bringup`: full 10-channel walking pattern run, user-verified with a DMM in continuity mode against the coil harness — all 10 channels correct, no swaps, no misses. `canopen_app` (USB side): drove all 10 real relays ON, 0.47A real coil current confirmed, matching the ~0.45A design target. `canopen_app` (CAN side) and `uart_can_bringup` have not yet been re-run against the real board/real SN65HVD230/a real CAN bus (a transceiver is being wired up as of this pass) — only the earlier bare-devkit/build-verified history below. Earlier history for context: `i2c_scanner` and `uart_can_bringup` first ran live on a generic ESP32-C3 dev kit before any ORC PCB existed (see "Real-hardware run, 2026-08-01" below) — that confirmed MCU-side IO logic on real silicon of the right chip family, nothing PCA9555/SN65HVD230-related.
- Not a final board declaration — `esp32-c3-devkitm-1` in `platformio.ini` is an explicit stand-in; see above.
- USB is still not the production control path — CAN stays the one real transport in the field, even now that USB control is built into `canopen_app` itself rather than a separate sketch. See `docs/usb-bench-interface-spec.md`'s Scope section for the full "why this doesn't contradict the CAN-exclusive decision" reasoning.

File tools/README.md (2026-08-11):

# ORC host-side CAN test tools

Bench test scripts for talking to a real ORC board (running `firmware/src/canopen_app`) over a real USB-CAN adapter, from a PC. These are **not** part of `rigos-core`'s eventual integration (see that sibling repo's FR-059) — they're small, dependency-light scripts anyone can run on a bench to sanity-check a board without standing up the full rigOS stack.

**Setup assumed**: an ESP32-C3 running `canopen_app`, connected to your PC over USB (for power + serial monitor), with its TWAI pins wired through the SN65HVD230 transceiver to CAN_H/CAN_L, which is in turn wired to a **separate USB-CAN adapter** also connected to your PC (e.g. the Jhoinrch RH-02 / CANable-clone noted in `rigos-core`'s FR-059). Two USB connections to the same PC, two different jobs — the ESP32's own USB is just power/serial, not the CAN link; the adapter is the actual CAN link these scripts use.

## Install

```
pip install -r requirements.txt
```

Just `python-can` — see [`requirements.txt`](requirements.txt).

## Which `--interface`/`--channel` to use

**This depends on which firmware your specific adapter shipped with — check before assuming.** CANable-clone boards (like the Jhoinrch RH-02) commonly ship with one of two firmwares, and `rigos-core`'s FR-059 flagged this as genuinely unconfirmed for that specific board:

- **candleLight (`gs_usb`)** — the adapter enumerates as a native USB-CAN device. On Windows this needs the `gs_usb`-compatible WinUSB driver bound via [Zadig](https://zadig.akeo.ie/) before python-can can see it (a one-time setup step, not something these scripts do for you). Once set up:
  ```
  python can_monitor.py --interface gs_usb --channel 0
  ```
  (`0` = first `gs_usb` device found; python-can enumerates by index.)

- **slcan** — the adapter enumerates as a plain serial port (a COM port on Windows, `/dev/ttyACM*` on Linux). No special driver needed beyond the OS's own USB-serial driver. Check Device Manager for the COM port number, then:
  ```
  python can_monitor.py --interface slcan --channel COM5
  ```

If you don't know which firmware your board has: try `slcan` first (needs a COM port to show up in Device Manager, easy to check, no driver install) and fall back to `gs_usb` if the port never enumerates as serial.

**Bitrate**: ORC's bus is locked at 125 kbit/s (`docs/can-protocol-research.md`). Both scripts default `--bitrate` to that — don't override it unless every node on your bench bus (including the adapter itself) is deliberately set to something else.

### `gs_usb` on Windows — two extra install steps beyond Zadig

Confirmed against a real Jhoinrch RH-02 (`canable gs_usb`, VID_1D50:PID_606F) on Windows, 2026-08. Binding the WinUSB driver via Zadig (as the section above describes) is necessary but **not sufficient** — `pyusb` (which `gs_usb` depends on) also needs the actual `libusb-1.0.dll` *runtime library*, which Windows doesn't ship and Zadig doesn't install:

```
pip install gs_usb libusb
```

`pip install libusb` bundles a working `libusb-1.0.dll`, but `pyusb`'s default search won't find it automatically — put its directory on `PATH` before running either script:

```
set PATH=%USERPROFILE%\AppData\Local\Programs\Python\Python313\Lib\site-packages\libusb\_platform\windows\x86_64;%PATH%
```

(Adjust the Python version/path to match your own install — find it with `python -c "import libusb, os; print(os.path.dirname(libusb.__file__))"` and append `\_platform\windows\x86_64`.) Symptom without this: `python -c "import usb.core; print(len(list(usb.core.find(find_all=True))))"` reports `0` devices even though Windows Device Manager shows the adapter present and its driver bound correctly.

## The two tests

### 1. `can_monitor.py` — passive listener, run this first

Listens for Heartbeat/TPDO1/TPDO2 traffic and decodes it, without sending anything. Auto-discovers node IDs from whatever it actually sees on the bus — you don't need to already know the board's DIP-switch setting to run this one. Good first check that the adapter is wired correctly and the board is alive and running `canopen_app` (as opposed to one of the IO-level bring-up sketches, which don't speak CANopen at all — see `firmware/README.md`).

```
python can_monitor.py --interface slcan --channel COM5
```

Ctrl+C to stop, or pass `--timeout <seconds>` to auto-stop after a quiet period.

### 2. `relay_toggle_test.py` — sweep + all-on demo/test

Runs a fixed sequence over CAN, confirming every step via TPDO1 readback: sweeps channels 1 through 10 one at a time (1s each, exclusive — only that channel is on at each step), pauses with everything off, turns all 10 channels on at once, pauses again, then cleans up (all off) on exit. This is the real end-to-end path (host → RPDO1 → ORC → PCA9555 → TPDO1 readback → host), and it exercises both a single-channel command and an all-channels-at-once command — a real distinction on this hardware, since RPDO1 always sends the whole 10-bit state, not a per-bit toggle.

Needs the board's **node ID** (read directly off its DIP switch, weight-labeled `1 2 4 8` — see `docs/circuit-draft.md`'s "Node-ID address input" section).

```
python relay_toggle_test.py --interface slcan --channel COM5 --node-id 1
```

Tune the timing with `--sweep-seconds` (default 1.0s per channel) and `--pause-seconds` (default 2.0s, used both for the all-off pause before the all-on step and as the all-on hold duration):

```
python relay_toggle_test.py --interface slcan --channel COM5 --node-id 1 --sweep-seconds 0.5 --pause-seconds 3
```

Exit code is 0 if every step's TPDO1 confirmation matched what was commanded, 1 otherwise — usable in a simple pass/fail bench check, not just interactively. Ctrl+C at any point still runs the all-off cleanup before exiting.

## `orc_canopen.py`

Shared wire-protocol constants/encode-decode helpers, imported by both scripts above — the Python-side counterpart to `firmware/lib/orc_canopen/orc_canopen.h`. **The two are hand-maintained in parallel, not generated from one source** — if ORC's protocol ever changes (a new message, a COB-ID change, a payload layout change), both need updating together, along with `docs/can-protocol-research.md` (the actual source of truth) and `rigos-core`'s `orc_can.py` (the sibling repo's own independent implementation of this same protocol).

Also holds `drain_stale_frames()` (the one function here that does touch a bus — see its own docstring) and the SDO read/response codec used for the startup status poll below.

## Startup status poll — why both scripts send one

Real-hardware finding, 2026-08: a board addressed at node ID 0 (all four DIP-switch positions open) was observed staying completely silent on the bus — no Heartbeat, nothing — until the *first* time something was actually sent to it. Both scripts now send one SDO read (of ORC's TPDO2 event-timer object, `1801h`/`5`) at startup specifically to provoke that first response, in addition to it being a genuine, harmless read (doesn't touch relay state). Not fatal if it times out — its job is putting a frame on the wire, not necessarily getting an answer. Skip it with `--no-poll` if you don't want it.

Related: both scripts also drain any stale buffered frames immediately after opening the bus (`drain_stale_frames()`) — real hardware showed that a fresh session opened against an adapter that had a prior session killed uncleanly (e.g. by a hard timeout instead of `bus.shutdown()`) can inherit a backlog that makes a 2-second wait loop take much longer than 2 seconds to actually reach its deadline, since it burns through old buffered frames first.

## Known open item: TPDO1 confirmation can lag or drop under real bus conditions

Real-hardware finding, 2026-08, **not yet root-caused**: a full 1-10 channel sweep against real hardware showed roughly every other TPDO1 missing entirely, and the ones that did arrive consistently reported the *previous* step's commanded mask (a one-cycle lag) — while the relays themselves were independently confirmed, by directly watching/listening to the board, to click through correctly and in real time. So the RPDO1 command path works; TPDO1's confirmation channel is what's unreliable, at least under the bus conditions observed.

**Ruled out**: a stale frame sitting in the host's own receive queue from the previous step. `relay_toggle_test.py` already drains immediately before every send (see `command_and_confirm()`), and it made no difference — same lag, same drop pattern.

**Update, code-review pass against `canopen_app` (post-FR-004), 2026-08-10 — not `canopen_app`'s fault, points at bus health.** Full writeup in `.claude/tpdo1-lag-investigation-prompt.md`'s "Findings" section (gitignored, local-only); summary: `handleRpdo1()` → `applyRelayCommand()` → `twaiSend()` is synchronous, straight-line code with nothing that could delay a send by anywhere near 1s — rules out a firmware-logic cause. But `twai_transmit()` returning `ESP_OK` only means *queued*, not *transmitted-and-ACKed*: the ESP-IDF TWAI controller retries an unACKed frame in hardware, invisibly, for as long as it takes, and `canopen_app`'s `twaiSend()` never retries a failed enqueue itself (`tx_queue_len = 5`, one attempt, log-and-drop on failure). On a bus with real ACK trouble, that alone reproduces both symptoms: a TPDO1 that's stuck retrying can physically leave the transceiver a cycle late (the "previous step's mask" pattern), and once the 5-deep queue backs up, a subsequent send is dropped outright (the "no TPDO1 at all" pattern). The session's own measured TX error counter (127, right at the error-passive boundary, recovering over ~10s) is independent evidence the bus *did* have real ACK problems at the time — consistent with, and sufficient to cause, this mechanism.

**Root-caused and fixed at 1s/2s cadence, 2026-08-10.** The bus-settling and termination theories were tested directly and both came back negative (TEC held at 0 for 10+ seconds through a full sweep, termination confirmed populated correctly both ends, and the sweep still went 0/12 with the identical lag/loss shape) — ruling out bus health entirely at this cadence. That reopened the investigation on the firmware side, which found the real cause: `handleRpdo1()` calls `Serial.printf()` to log the incoming RPDO1 *before* `applyRelayCommand()` sends TPDO1, and native USB-CDC (`HWCDC`) writes have a documented worst-case block of up to 2000ms (20 retries x 100ms default `tx_timeout_ms`) when the physical USB link is up but nothing is draining the ring buffer — comfortably longer than this script's 2s confirm window. Fix applied and flashed: `setup()` now calls `Serial.setTxTimeoutMs(20)`. Re-ran the identical sweep against the reflashed board: **12/12 steps confirmed** at the standard 1s/2s cadence.

**Sub-second cadence (BUG-003, same day, follow-up) — do not use below ~1s.** Randomized-mask stress testing at 0.5s/0.3s cadence found a second, distinct problem: TPDO1 lag/loss and total Heartbeat/TPDO2 silence, worse than the 1s-cadence symptom above. Chased two real contributing mechanisms: (1) a TWAI TX-queue backlog letting stale status frames block fresh ones (fixed, `twai_clear_transmit_queue()`); (2) the `setTxTimeoutMs(20)` fix above was itself under-specified — `HWCDC.cpp`'s retry *count* (20) is a hardcoded constant the timeout call doesn't adjust, so the real worst case is `20 x 20ms = 400ms` per blocking write, not "~200ms," and `canopen_app` issues several such calls per RPDO1 that compound. Fixed with `printBestEffort()` (skips a diagnostic print entirely rather than blocking if the console isn't being drained) — confirmed via a same-session A/B real-hardware test: identical firmware, identical 0.5s cadence, 1/15 confirmed with nothing reading the USB console vs. **15/15** with a reader attached. Real, substantial improvement (1/15 → 6/15 in the harder no-reader case) but **not a full fix**: watching the bus directly during a fresh run found real `CAN_ERR_CRTL` (RX+TX error-warning) CAN error frames recurring every ~2-2.4s, unaffected by the Serial fix, and Heartbeat/TPDO2 still fully silent over a full 20s run — evidence of a genuine bus/controller-level condition under fast bidirectional traffic, not further-fixable firmware logic. **Recommendation, and the actual resolution**: keep RPDO1 commanding at ~1s or slower — real hosts have no reason to approach sub-second relay-command cadence. Full investigation trail: `docs/features/BUG-003.md`.

See `.claude/tpdo1-lag-investigation-prompt.md` (gitignored, local) for the full blow-by-blow investigation trail if picking any of this up again.

## What these are not

- Not a replacement for `rigos-core`'s eventual `orc_can.py` integration (FR-059) — that's the production daemon-integrated backend; these are standalone bench scripts.
- **Hardware-verified as of 2026-08**: both scripts have been run against a real ORC board (Jhoinrch RH-02 adapter, real `canopen_app` firmware) — the startup poll, bus liveness, and the RPDO1 relay-command path (physically confirmed) all work. TPDO1 confirmation reliability is the one open item, documented above, not swept under the rug.

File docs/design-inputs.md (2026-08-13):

# ORC design inputs

What carries forward from the PMUN1046A teardown, what has to be built from scratch, and what still needs measuring before layout.

Source of truth for the teardown itself is a private working record, not published. Facts are cited back to it rather than duplicated here; where a figure is **unverified**, it says so.

## Provenance of the donor unit

The donor unit was purchased outright on the surplus market. No non-disclosure agreement, accessory-program enrollment, license agreement, or terms-of-service click-through was entered into to obtain or inspect it, and no lock, encryption, or authentication measure was defeated to examine it — the unit was opened with hand tools and characterized by measurement.

Everything recorded here is either a fact measured from that unit or a fact cited by section to Motorola's published service and installation documentation. No Motorola firmware, source code, drawing, photograph, or manual text is reproduced in this repository. ORC does not implement or interoperate with the donor unit's proprietary GCAI link; it replaces the controller board entirely. See [TRADEMARKS.md](../TRADEMARKS.md).

## Inherited from the donor unit

All of this is genuinely useful and is why the donor unit is worth building around.

| Item | Part | Notes |
|---|---|---|
| Relay board | PMLN5639_ | **Entirely passive.** Ten Tyco relays, ten 15 A fuses, terminal blocks, power lugs, busbar. No active parts, no drivers, no regulator. |
| Wire harness | 0975931M01 | Being reused as-is. Connects the controller board to the relay board — carries switched 9 V coil drive only, not power and not logic-level commands. Power input has its own separate path straight to the busbar via cable glands, no harness involved. |
| Chassis | — | Sealed, metal, trunnion-mounted. Cable glands with per-wire radial gaskets. |
| Channel rating | — | 15 A per output, matching the fuse and relay rating. |
| Input feed | — | Busbar, one or two cables, **60 A maximum per cable** — the capability of the busbar, lugs, and glands. |

### On the 60 A / 16 A / 15 A figures

These describe three different things and are often conflated. They are all correct:

| Figure | What it is |
|---|---|
| **60 A per cable, ×2** | Capability of the input path — busbar, lugs, glands |
| **16 A** | Motorola's *specified* installation breaker, part 40012006001 |
| **15 A per output** | Per-channel fuse on the relay board |

**The circuit breaker is external, vehicle-side hardware** — installed inline between the URC's power lug and the battery ("AUX" end to the URC, "BAT" end to the supply). There is no breaker inside the enclosure, and ORC does not need to provide one. Input protection remains an installation choice, sized to the actual load and cable, and is not an ORC board-level concern.

### ORC's board does not carry the high-current path

Worth stating plainly, because it substantially simplifies the design: the load current never touches the controller PCB. It runs **busbar → relay contact → fuse → output terminal**, entirely on the passive relay board.

ORC's board only needs a **low-current A+ tap** for the 9 V coil supply and its own logic. The current there is bounded by ten relay coils plus the ESP32 — not by the 60 A input capability or the 150 A theoretical contact total. The "automotive input transient protection" line below refers to that low-current control tap.

### Inherited per-channel capability, and what limits it

Bench inspection 2026-07-31. **Inspection findings and estimates, not instrumented measurements.**

| Element | Finding | Confidence |
|---|---|---|
| Tyco relays | **40 A rated parts** — far above the 15 A system rating | Observed (part rating) |
| A+ busbar | Good for roughly **150 A total in short bursts**, both cables fed | Estimate, not measured |
| PCB traces, fuse positions, terminal blocks | **The actual limiting factor**, not the contacts | Observed |
| Relays **9 and 10** | Only two channels with convenient room for heavier copper, by layout accident | Observed |

Uprating a channel is disproportionately expensive: IPC-2221's external relation (`I = 0.048 × ΔT^0.44 × A^0.725`) inverts to **area ∝ I^1.379**, so 15 A → 25 A needs **2.02×** the copper and 15 A → 40 A needs **3.87×**.

<!-- 3.87x corrected from 3.7x, 2026-08-06: (40/15)^(1/0.725) = 2.6667^1.37931 = 3.868. The 25 A figure (2.02x) was already correct. Ratio is independent of ΔT, so no assumption about temperature rise is involved. -->

In absolute terms, at ΔT = 20 °C rise (`A = (I / (0.048 × ΔT^0.44))^1.379`, A in mils²):

| Target | Required copper | Width at 2 oz (2.8 mil) | Deficit vs. the 15 A trace |
|---|---|---|---|
| 15 A (stock) | 449 mils² | ~160 mil (4.1 mm) | — |
| 25 A | 908 mils² | ~324 mil | 459 mils² ≈ 21 AWG |
| 40 A | 1,735 mils² | ~620 mil | 1,286 mils² ≈ **18 AWG** |

So the copper *deficit* for a full 15 A → 40 A uprate is only about **18 AWG** worth of bonded wire — 12 AWG (5,130 mils²) overshoots it ~4×. That is a smaller conductor than the "12 AWG is ~14× a trace" comparison below might suggest reaching for; the 14× figure describes how much a 12 AWG bond *adds*, not how much is *needed*. Note also that ΔT = 20 °C is an open-bench assumption and does not hold in this sealed enclosure — see the thermal-soak caveat below.

If a channel ever needs uprating, note that **solder lumping is weak and bonded wire is strong** — solder runs ~8× copper's resistivity (SAC305 ~13 µΩ·cm, Sn63Pb37 ~15, Cu 1.72), so a generous fillet buys only ~1.25× conductance, while 12 AWG (3.31 mm², ~5130 mils²) is ~14× a 2 oz/128 mil trace. Best is a conductor from busbar straight to the relay terminal, bypassing the trace.

Two caveats that make trace work pointless on its own:

- **The fuse clip and terminal block don't improve with copper.** The chain is busbar → trace → contact → trace → fuse clip → fuse → trace → terminal block → output. Verify those two are rated for the target before reinforcing anything upstream.
- **The enclosure is sealed**, so heat only leaves through the chassis. Validate any uprating with a **thermal soak, lid on** — not an open-bench measurement.

## Requirements this places on ORC

**Channel mapping must be configurable, not hardcoded.** The ten channels are *not* electrically identical — 9 and 10 have headroom the rest don't. Function-to-channel assignment therefore belongs in configuration, so a high-draw load can be placed on a capable channel without rewiring.

rigOS already has hooks for relay number assignment, so the platform side of this is solved; ORC's firmware needs to expose channel identity and accept the mapping rather than assuming a fixed layout.

Open, not yet a requirement: **per-channel current sensing.** If channels differ in capability, knowing actual draw would let firmware enforce limits rather than trusting configuration. Costs board area and BOM — worth deciding deliberately rather than defaulting either way.

## To be rebuilt

Everything below lived on Motorola's controller board and is lost when we replace it. This is a real power design, not a microcontroller swap.

- **9 V coil regulator**, sized for all ten coils energized simultaneously. Motorola ran coils at 9 V rather than 12 V specifically to cut coil heat dissipation (service manual 3.7.4) — worth preserving that choice.
- **Ten relay drivers**, plus flyback if the relay board does not already carry it.
- **Automotive input transient protection** on the 12 V feed. Load dump is not optional in a vehicle.
- **Isolation barrier, if retained** — see the open decision below.

## Open architecture decisions

### Isolation

Motorola isolated MCU logic from coil drive with ADuM1410 digital isolators. The reason is sound: coil-drive ground referenced the relay board and vehicle chassis, while MCU ground arrived from the radio over USB — two references that can differ meaningfully during high-current switching.

If ORC's controller and the relay board share a supply and a solid star ground, the case for isolation is weaker. This is a deliberate decision to make, **not one to skip by default**. Isolation also costs channel count, board area, and an isolated supply for the coil-side logic.

### Primary control path — resolved 2026-08-01

**CAN, exclusively. No wireless (WiFi/BLE) at all** — reversed from the original assumption that "WiFi is essentially free." Two things forced this, not one: a mechanical finding (only ~8.5mm clearance between two stacked PCBs, not enough room for both a USB-C connector and the required DC+CAN screw terminal) plus a scope decision (the board's actual job is CAN in, drive the I2C GPIO expander out — light duty, doesn't need a WiFi/BLE stack or the dual-core Xtensa S3 originally assumed). MCU is moving from a bare ESP32-S3-WROOM-1U to a pre-made **ESP32-C3** module (see subcircuit-capture-guide.md's MCU section for the specific board once sourcing lands) — single-core RISC-V, confirmed adequate for this workload.

### Antenna — moot, superseded by the above

The external-antenna requirement below is **obsolete**, kept for record only. With wireless descoped entirely, radio is never enabled in firmware, so a sealed metal enclosure blocking a PCB-trace antenna is no longer a real constraint — this also reopens cheap PCB-antenna-only modules that were previously disqualified.

~~The chassis is metal and sealed, so an on-module PCB antenna will not radiate out. Routine to solve: use an external-antenna module (**ESP32-S3-WROOM-1U** or equivalent, U.FL/IPEX) with a pigtail to an **O-ring-sealed bulkhead SMA** at one of the existing gland positions.~~

~~Pick the module variant and bulkhead part before layout — U.FL placement constrains the board outline.~~

## Outstanding measurements

Nothing below is assumed. These gate the schematic.

### Harness header — the critical interface

**Resolved: plain 0.1" (2.54mm) pitch, unshrouded, vertical male header** — not the shrouded 3.96/4.20/5.08mm part guessed from the initial by-eye inspection. The candidate-family table below is now superseded; kept for record.

Superseded candidate table (initial by-eye guess, before the actual 0.1" header was confirmed):

| Pitch | Family | Notes |
|---|---|---|
| 3.96 mm (0.156") | Molex KK 396 / 5273 | Common at automotive coil-level currents |
| 4.20 mm | Molex Mini-Fit Jr | Higher current capability |
| 5.08 mm (0.2") | Various | Less likely at this pin count |

- [x] **Pitch.** **0.1" (2.54mm), unshrouded, vertical, THT male header.** LCSC **C2977586** (ZHOURI 2.54-1×40, breakable strip, snap to 14 positions), Extended, 2.5A rated, -40 to +105°C — clears automotive temp range with margin. See circuit-draft.md BOM #7.
- [x] **Pin count and pinout mapping.** **14 positions, confirmed by count**, not the guessed 12–13:

  | Pin | Function |
  |---|---|
  | 1 | Coil common return ("coil −", shared across all 10 channels) |
  | 2 | A+ |
  | 3–12 | Coil 1+ … Coil 10+ (one per channel) |
  | 13, 14 | Chassis (relay-board side) |

- [x] **High-side vs low-side switching.** **Confirmed high-side** — individual "Coil N+" per channel with one shared common return, matching the positive-switched decision already locked in circuit-draft.md independently of this measurement.
- [ ] **Flyback diode presence on the relay board.** Still open — the pinout doesn't resolve this; still needs bench inspection or continuity/diode check across a coil's harness pins.
- [x] **Does the harness carry A+ up to the controller board, or is A+ tapped separately from the busbar?** **Confirmed: pin 2 is A+, carried by the harness.** ORC's board connector needs to carry the A+ feed directly — no separate lug/tap required.

### Ground topology — dismissed, not a concern

Pin 1 (coil common) and pins 13/14 (chassis) are three separate wires on the connector, not one labeled net. Flagged earlier as a possible star-grounding question given the isolation architecture — **user call: not important, tie them together as one common ground.** No special handling needed on Domain B's ground plane.

### Coil and thermal

- [x] **Coil current — measured: 45mA per coil at 9V, room temperature, reliable across all 10 channels** (user-measured). Implies coil resistance ≈ 200Ω (not independently verified via direct DMM reading, backed out from V/I). Total current with all ten energized: 0.45A at 9V (~4.05W) — sizes the 9V switcher, see circuit-draft.md. Coil resistance rises with temperature, so this room-temp figure is likely near the higher end of the real operating current range, not a worst-case-low estimate.
- [ ] **Total coil current checked against harness and ground-path ratings** — the 0.45A figure above is well within any plausible harness rating, but hasn't been explicitly cross-checked against the harness pin gauge/rating.
- [ ] **Tyco relay part number**, and whether all ten are identical single-pole parts.

### Mechanical

- [ ] **Board outline, mounting hole positions, Z-height clearance.** The stock controller board is retained by two T10 Torx screws; ORC has to match that footprint and clear the chassis and thermal pads.
- [ ] Gland positions and which one can host the antenna bulkhead.

## Consumables

Single-use parts — order spares per unit opened:

- **Light Bar Gasket** 3278310A01 (×2 per unit)
- **Thermal pad** 75012026001 (×2 per unit)

Reassembly torques and the full disassembly sequence are in the private teardown record. The main O-ring must not be pinched or the enclosure loses its seal.

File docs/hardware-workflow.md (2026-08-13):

# Hardware workflow — gates, not automation

Practical subset of [PCB-Agent-Teams](https://github.com/Zane456/PCB-Agent-Teams)'s discipline, adapted for this repo: manual KiCad on Windows, US sourcing, no Claude Code skills. The value there isn't the automation — it's the checkpoints that stop a board from shipping on an invented part number or an unverified footprint. Apply these by hand.

## Why not the framework itself

- **Windows has no `pcbnew` Python interpreter path.** `draw-pcb`'s scripted board generation has nothing to call here. `kicad-cli`'s `sch erc` / `pcb drc` subcommands are plain CLI, not scripted-`pcbnew`, and do work cross-platform — that part is worth keeping (see Gate 3).
- **Part-selection locales are Japan and China-mainland only.** No US variant. Digi-Key/Mouser US sourcing stays manual.
- Schematic/PCB capture itself stays in the KiCad GUI, not source-generated from Python.

## Gate 1 — part selection: nothing from memory

Every part number in [circuit-draft.md](circuit-draft.md)'s BOM table already gets this treatment; keep doing it:

- Pull from a live Digi-Key / Mouser / LCSC catalog page, not recollection. Cite the distributor part number (LCSC `C######`, Digi-Key/Mouser SKU).
- Record Basic/Extended (or equivalent turnkey-cost) status, and flag it **unconfirmed** if the live page wasn't actually checked this pass.
- Tag every line with a confidence level (High / Medium / Low, or "not yet verified on live catalog") — don't let a guess read the same as a checked fact.
- **Don't lock the BOM** while any line carries an open verification item. Keep those in the "Open items before schematic capture" checklist until closed.

## Gate 1 in practice — the sourcing-pass pattern

Worked out over the LM2596 passives / diode / PTC sourcing rounds in circuit-draft.md. Keep using this shape:

- **Dispatch one focused sourcing task per part or tightly-related group**, not one giant "find everything" pass — narrow asks come back with real LCSC C-numbers and live stock counts; broad ones come back vague. Ask explicitly for: part number, manufacturer/MPN, exact spec match, package, Basic/Extended tier, live stock count.
- **LCSC's search is JS-rendered and doesn't scrape reliably.** When a sourcing pass comes back "not found" for an obviously-common part (a standard E96 resistor, a common ceramic cap value), retry once with a different search term or a nearby standard value — that resolved real gaps twice this session (1.69kΩ/6.34kΩ → 1.2kΩ/2.0kΩ/7.5kΩ; 1500pF → 1000pF). If a second attempt still comes up empty, **stop and flag it for a direct manual LCSC.com check** rather than burning further automated passes against the same wall — three failed attempts at the exact same value is a tooling limit, not a part that doesn't exist.
- **If working inside Claude Code with the `kicad-mcp-pro` MCP server connected, try `lib_get_component_details(lcsc_code_or_mpn)` first, before any web fetch.** It hits jlcsearch's live API directly and returns a structured `Basic: yes/no, Preferred: yes/no` field — a real answer, not a scraped badge or a circumstantial inference. Confirmed working 2026-08-01 (resistor array C29718: "Basic: yes, Preferred: no", plus a live stock figure) after every page-scrape and CSV-based method that session had given inconsistent results. Only fall back to the methods below when this tool isn't available.
- **Basic/Extended tier badges specifically don't render to automated fetch, even when the rest of the page does.** Hit on 4 out of 4 parts in one sourcing round (2026-08-01: inductor, NPN transistor, both P-FETs, I2C expander) — stock count, spec, and part identity all came back clean, but the Basic/Extended badge itself was consistently missing from the fetched text on both LCSC's and JLCPCB's part-detail pages. Treat this as a standing tooling limit, not a one-off: **tier claims from an automated sourcing pass are circumstantial (inferred from price/stock patterns or third-party Basic-parts-list mirrors) until a human does one direct visual check on the actual page.** Don't let a circumstantial tier read as a confirmed one in the BOM.
- **A maintained JLCPCB Basic-parts CSV (e.g. `rljacobson/JLCPCBBasicLibrary` on GitHub) can give a real, non-circumstantial confirmation the page badge can't** — worked cleanly once (2026-08-01, a resistor array) with a direct "Very popular"/no-Extended-tag listing. **It is not a universal fix**: the same method on four different diode candidates that same day came back inconsistent, contradictory (a part assumed "obviously safe generic" was explicitly tagged Extended in one such list), or truncated mid-fetch before reaching the part in question. Treat a CSV hit as real evidence, a CSV miss as inconclusive (not proof of Extended), and don't expect this method to resolve every tier question just because it resolved one.
- **When a tier-unconfirmed swap is being weighed against an already-committed part, the reel-loading fee ($3/order, per distinct Extended part) is asymmetric, not a flat cost to compare part-for-part.** Reusing a part already in the BOM for another role carries *zero incremental* fee risk regardless of its own tier, since that decision is already made and paid for. Introducing *any* new, tier-unconfirmed part number carries a *fresh* risk. This decided two calls on 2026-08-01: rejected a pre-biased-transistor swap (would have added a new unconfirmed part to save resistor count) in favor of a Basic-confirmed resistor array, then reused an already-in-BOM diode (SS34/C8678) over three different tier-unconfirmed alternatives for the same reason — a smaller footprint or lower part count doesn't pay for itself if the honest cost is a real fee against an uncertain benefit.
- **"Not found" is a reportable outcome, not a failure to hide.** Every sourcing summary in this doc distinguishes confirmed-live parts from parts that are real (confirmed via manufacturer datasheet or third-party distributor) but not yet pinned to a live LCSC listing. Never let an unconfirmed C-number read the same as a checked one.
- **Re-verify against the primary datasheet directly when a figure is load-bearing**, not a mirror or an agent's paraphrase. The LM2596 inductor/cap selection guidance was first sourced from a third-party mirror with the right shape but unconfirmed figure numbers; downloading and reading TI's actual SNVS124G PDF directly caught the difference (adjustable-version nomograph is E·T-based, not raw-Vin-based) before it became a wrong component pick.
- **Don't copy a reference design's values past the range they were derived for.** TI's Figure 9-13 generic circuit is a legitimate starting point, but its 470µF input cap was sized for a 3A example load — copying it verbatim for a ~0.2–0.5A design would have forced an unsourceable 470µF/63V polymer part into existence. Re-deriving from TI's own sizing rule (RMS ripple current ≈ 50–75% of DC load) for the *actual* load gave a right-sized, easily-sourced value instead. When a generic circuit's component value was clearly picked for a specific operating point, check whether this design's operating point actually matches before reusing the value.
- **When a design decision earlier in the session leaves a BOM line stale, say so and fix it — don't leave it silently orphaned.** The load-dump TVS BOM line was written against a single-power-entry architecture; when the design later split into two separately-isolated power entries, nobody had gone back to re-specify which node the TVS protected. Caught it, flagged it explicitly as a gap (not just an omission), and it ended up removed by user decision rather than carried forward unresolved.

## Gate 1 — BOM line-count discipline

This project's scale (small-batch turnkey, not a cost-optimized high-volume design) makes fewer distinct part numbers worth real trade-offs elsewhere. Applied twice this session:

- **Consolidate when the reused part clears the new role's requirement with real margin to spare.** SS56 (60V/5A Schottky, already qualified as the buck catch diode) was reused for the coil flyback-diode role instead of sourcing a new part — a flyback diode across a 9V/45mA coil needs a fraction of SS56's rating, so reuse costs only some board area (SMA/DO-214AC is bigger than a minimal SOD-123 would need), not function.
- **Don't consolidate when the parts' selection criteria diverge enough to defeat the part's purpose.** Evaluated reusing one PTC resettable fuse across two DC input nodes with different steady-state currents (~0.2A and ~0.45A) — the lower-hold-current candidate (0.5A) was too tight against the higher-current node to avoid nuisance trips, so the shared part had to be picked to satisfy the *more demanding* requirement (0.75A hold), accepting looser fault-current precision on the lighter-loaded node as the explicit trade. Still one BOM line, but the choice of *which* part to standardize on was driven by the harder constraint, not convenience.
- When genuinely unsure which way a consolidation cuts, surface the trade-off (AskUserQuestion or a flagged note) rather than picking silently — the PTC case above was a real judgment call, not an obvious answer.

## Gate 1 — a rated spec at 25°C isn't the spec that matters in a sealed enclosure

This board lives in a sealed automotive enclosure (heat only leaves through the chassis, 65–85°C ambient expected — see design-inputs.md). Any component whose datasheet headline number is a 25°C (or 20°C) rating needs its actual temperature-derating curve checked before that number gets treated as real margin. This bit twice in one pass: the PTC resettable fuse initially selected (Littelfuse 2920L075/60MR, 0.75A hold at 20°C, 1.67× nominal margin over the 0.45A load) actually derates to **0.34A at 85°C — below the load it was supposed to protect**, per Littelfuse's own temperature-rerating table. The 25°C number alone would have shipped a part that nuisance-trips or fails to protect at the enclosure's actual worst-case operating temperature.

- **For any thermally-sensitive part** (PTCs, anything with a current or power rating that's fundamentally a self-heating limit — regulators, fuses, connectors with contact-resistance heating) **pull the manufacturer's actual temperature-derating table before treating a 25°C-rated margin as real.** Don't extrapolate a percentage — read the actual printed row for the actual part number; derating curves are not linear or consistent across a manufacturer's own family (confirmed directly this session: Littelfuse's 2920L075/60 and 2920L110/60 don't derate by the same fraction).
- **Voltage and current ratings trade off within a family, and relaxing one to fix the other is itself a decision to record, not a free upgrade.** Moving from a 60V-rated PTC to a 33V-rated sibling in the same series fixed the thermal-current margin (0.34A → 0.74A @85°C) but dropped the voltage margin over this design's 28.8V ceiling from 108% to ~15% — both numbers belong in the BOM note, not just the one that got fixed.
- This generalizes past PTCs: any time a spec-sheet number is a room-temperature figure and the part lives in this enclosure, ask "what does this number actually do at 85°C" before locking it.

## Gate 2 — nothing drawn until the asset is on disk

Before a part goes into schematic capture:

- Datasheet fetched and the number actually cited against it (not "seems about right").
- Footprint/symbol confirmed to exist and match the part's real package — THT vs. SMD, actual pin count vs. datasheet pinout, no generic-symbol-standing-in-for-a-real-part.
- Part number and package written into the BOM table before it's placed on the schematic, not entered from memory while drawing.

This is already how `design-inputs.md` §"Harness header" and `circuit-draft.md` §"MCU bring-up facts" operate — datasheet-cited, checkbox-gated. Extend that same treatment to every BOM line before schematic capture starts, not just the ones that already got scrutiny.

## Gate 2 — kicad-mcp-pro tooling notes (learned 2026-08-02, editing `.kicad_sch` directly)

Lessons from fixing L3/L4's buck-inductor value/footprint/LCSC/MPN — a plain property edit that hit three separate tooling gotchas in one pass. Keep these in mind whenever a schematic edit is happening through the MCP server rather than the KiCad GUI:

- **`kicad_set_project`'s `sch_file` argument silently mis-resolves a bare filename.** Passing `sch_file: "power_side_a.kicad_sch"` alongside `project_dir` resolved to `C:\...\orc\power_side_a.kicad_sch` (missing the `hardware\` folder), not the real path — and every subsequent read/write tool then failed with `NOT_FOUND` against a file that does exist, just not where the tool looked. Fix: always pass `sch_file` as a **full absolute path**, not a bare filename, even though `project_dir` is already set.
- **`sch_update_properties` / `sch_modify_property` have a write-guard that can false-positive on files with pre-existing collinear wire T-junctions.** Both tools refused *every* write to `power_side_a.kicad_sch` — including a no-op-adjacent Value-only change — with `"the schematic mutation dropped structure (wire 12->10)"`. Root cause, confirmed via `sch_get_wires`: the sheet had two places where three collinear wire segments meet at a T-junction (a through-wire plus a stub); the tool's own serializer merges each collinear pair on round-trip write, then its own safety check aborts on seeing that merge, mistaking it for accidental data loss. This is a property of the *file*, not the edit being attempted — reproduced by trying the smallest possible change. **Workaround: edit the `.kicad_sch` text directly with Read/Edit**, matching KiCad's native s-expression property-block format exactly (four fields per part typically: `Value`, `Footprint`, `LCSC`, `Manufacturer Part Number`), then confirm with `git diff` that only the intended lines changed and nothing wiring-related moved. If this recurs on another sheet, check `sch_get_wires` for collinear T-junctions before assuming the requested edit is the problem — it very likely isn't.
- **A file open in someone else's live KiCad GUI session can silently overwrite an edit you just made.** Mid-task, both `power_side_a.kicad_sch` and `power_side_b.kicad_sch` got externally re-saved (visible as `generator "eeschema"` with a bumped version, ref renumbering like `R24`→`R19`, and `#PWR0xx` shifts consistent with a GUI re-annotate) — and that resave silently reverted the just-applied L3/L4 fix back to the stale placeholder. This happened **twice** in the same session. **Never trust a successful Edit call alone on a file that might be open elsewhere — re-grep or re-read immediately after to confirm the change survived**, and expect to reapply if someone else's GUI session saves over it. Asking the user to close the file in KiCad before editing (or editing only when they've confirmed it's closed) is the real fix, not a tooling workaround.

## Gate 3 — checked twice, two different ways

Once `hardware/` exists and schematic/PCB capture starts:

**Schematic stage**
- ERC clean via `kicad-cli sch erc` (CLI-only, no `pcbnew` needed — works on Windows).
- SPICE sanity check via ngspice where a subcircuit's behavior matters (e.g. the buck regulator's feedback divider, the coil-drive gate stage) — not just connectivity.
- Manual datasheet pin-cross-check: every net that touches a part's pin gets checked against that part's actual pinout table, not assumed from the symbol.

**PCB stage**
- DRC clean via `kicad-cli pcb drc` (same CLI-only path, Windows-safe).
- Manual schematic↔PCB cross-check before release: walk the netlist and confirm nothing shorted or dropped in layout. `draw-pcb`'s automated version needs `pcbnew`; the manual version is slower but does the same job.
- Thermal/EMC stays a design-inputs-style written analysis (see design-inputs.md §"Inherited per-channel capability") rather than the framework's automated 44-rule pass — no tooling for that exists here yet.

**Any gate failure rolls back.** Don't route around a failed ERC/DRC run or an unverified part by shipping anyway — fix it or explicitly re-open the item in the checklist.

## BOM split (for later — release stage)

Keep procurement and production BOM as separate artifacts once `hardware/` work starts generating them:

- **Procurement BOM** — what you actually order, from the sourcing pass above.
- **Production BOM / CPL** — what goes to a fab/assembly house, generated from the final layout, not hand-copied from the procurement list.

Not relevant yet at the pre-schematic stage this repo is in, but worth keeping separate from day one rather than untangling later.

## Doc structure already in use here

This repo already runs something close to PCB-Agent-Teams' three-layer split, just without the name:

| This repo | Framework equivalent | Role |
|---|---|---|
| [design-inputs.md](design-inputs.md) | `Projects/<name>/CLAUDE.md` | Static compass — what's inherited, what's measured, what's still open |
| [circuit-draft.md](circuit-draft.md) | working schematic-stage notes | Live decisions log + BOM, updated per session |
| README.md status line | `STATUS.md` | One-line current phase |

No new file needed for this — keep using design-inputs.md for settled facts and circuit-draft.md for in-progress decisions, the way both already do.

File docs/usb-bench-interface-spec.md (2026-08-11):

# USB bench/debug interface — spec for firmware implementation

Status: **implemented, real-hardware confirmed, and consolidated into
`canopen_app`** (2026-08-10, FR-004 — see
[`docs/features/FR-004.md`](features/FR-004.md)). This protocol originally
shipped as its own standalone `usb_bench` sketch/environment
([`docs/features/FR-001.md`](features/FR-001.md), now superseded); it now
lives in [`firmware/src/canopen_app/main.cpp`](../firmware/src/canopen_app/main.cpp)
alongside the CAN protocol, driving the same PCA9555 state, per the user's
explicit ask to be able to drive relays from either CAN or USB. This
document remains the wire-protocol/rationale source of truth — the
implementation tracks it, doesn't fork it. Real-hardware confirmed
2026-08-10: all 10 relays driven ON over this protocol on a real, powered
ORC PCB, 0.47A real coil current observed (matches the ~0.45A design
target).

## Scope — read this before anything else

**This is a bench/development interface, not a production control path.**
`docs/design-inputs.md`'s "Primary control path" section resolved
2026-08-01: *"CAN, exclusively. No wireless (WiFi/BLE) at all."* That
resolution is about the ESP32-C3 module's **radio** losing to CAN for
application control — it says nothing about the module's native USB-C,
which survives on the board regardless, wired only for
programming/flashing. This spec proposes using that same, already-present
USB-C port for a serial *bench* interface — no new connector, no BOM
change, no board respin, and no contradiction of the resolved CAN-exclusive
decision. In the field, on a vehicle, ORC is still commanded over CAN only.
This interface exists for firmware bring-up and bench diagnostics before
CAN hardware is soldered/wired, and as an optional bench tool afterward.

**Do not treat this as a reason to relax the CAN-exclusive decision.** If
that ever needs revisiting, it's its own decision with its own tradeoffs
(mechanical clearance, connector count) — this document takes it as given.

## Why rigOS wants this

rigOS's `io_relay` daemon (in the sibling `rigos-core` repo, FR-059) already
treats the relay bus as a pluggable transport — I2C expanders and, as of
FR-059, ORC over CAN (`services/io_relay/orc_can.py`). That CAN backend is
validated end-to-end against real electrical hardware (two USB-CAN
adapters, real bus, 0 errors), but bringing up ORC's *own* firmware still
needs CAN transceiver hardware wired correctly before anything on the ORC
side can be exercised at all. A USB-serial bench interface lets rigOS (or
a human at a terminal) drive and observe ORC's relay-channel logic directly
over the same cable used to flash it — no transceiver, no second CAN
adapter, no bus wiring — while that firmware is still being written and
debugged. It's the direct firmware-side analog of what
`tests/test_orc_can_bench_hardware.py` already proved works on the
rigos-core side once real CAN hardware exists.

It is *not* meant to become a second thing rigOS has to support in
production — CAN stays the one real transport there. A future rigos-core
bus backend for this (e.g. `orc_usb.py`, `transport: usb`) would be
explicitly scoped as **bench-only**, mirroring how `orc_can.py` is already
the real thing. That rigos-core-side backend is not part of this spec and
is not needed for this spec to be useful on its own (a human can talk to
this protocol directly with a serial terminal).

## Transport

ESP32-C3 native USB, CDC-ACM class (`TinyUSB`/Arduino-ESP32's built-in USB
CDC, or ESP-IDF's `tinyusb_cdcacm` component — implementation's choice).
Appears as `/dev/ttyACM0`-class device host-side; no baud rate actually
applies (USB CDC ignores it, but most serial libraries — including
`pyserial` — still require a value be passed; document that in the
firmware's own README so nobody chases a phantom baud-rate mismatch).

Point-to-point by construction (one USB cable = one ORC unit) — unlike the
CAN protocol, this interface has **no NodeID concept**. Channel numbering
(1-10) is identical to the CAN protocol's for consistency, but there's
nothing analogous to CAN's multi-unit fleet addressing to design here.

## Framing

Plain ASCII, one command or response per line, `\n`-terminated (`\r\n` from
a host should be tolerated — strip trailing `\r`). Deliberately not binary:
this needs to be usable by typing into a plain serial terminal
(`screen`/`minicom`/PlatformIO's own `-t monitor`, already used at
115200 baud per `firmware/README.md` for the UART bring-up sketches) during
firmware bring-up, not just by a script.

- Max line length: 128 bytes. Anything longer: respond `ERR LINE_TOO_LONG`
  and discard until the next `\n`.
- Case-insensitive commands recommended (easier to type by hand); firmware
  implementer's call.
- Every command produces exactly one response line (never zero, never
  multi-line) — keeps host-side parsing trivial, one `readline()` per
  request.

## Commands (host -> ORC)

| Command | Response | Notes |
|---|---|---|
| `PING` | `PONG <fw_version>` | Liveness + identify. `<fw_version>` is a short build identifier (git short-SHA or a firmware-defined version string), not a fixed format this spec dictates. |
| `VERSION` | `VERSION <fw_version> <build_date>` | Fuller build info than `PING`'s inline version, for diagnosing which build is flashed. |
| `SET <ch> <ON\|OFF>` | `OK SET <ch> <ON\|OFF>` or `ERR <code>` | `<ch>` is 1-10. Applies the channel state — same "energize/de-energize" semantics as CAN's RPDO1, just one channel per command instead of a bitmask (USB has no framing pressure forcing a coalesced format the way a single CAN frame's 8-byte payload does). |
| `GET <ch>` | `STATE <ch> <ON\|OFF>` or `ERR <code>` | Single-channel read of *applied* state (not requested-but-not-yet-applied — mirrors CAN's TPDO1 being the real read-back, not an optimistic echo). |
| `STATUS` | `STATUS <10-char 0/1 string>` | All 10 channels at once, channel 1 first, e.g. `STATUS 0010000000` means channel 3 on, everything else off. Fixed-width and trivially parseable. |

## Unsolicited lines (ORC -> host, no command needed)

This is the one place this spec deliberately does **more** than the CAN
protocol, based on a real gap FR-059 found and documented on the
rigos-core side: CAN's TPDO1 is event-driven only (sent once, on RPDO1
receipt), never periodic — so a host process that starts *after* the last
change has no way to learn current state short of re-commanding it. CAN
has real reasons to stay minimal (bus bandwidth, arbitration cost of
frequent frames); USB over a dedicated point-to-point link doesn't share
those constraints, so there's no reason to repeat that gap here:

- **`HB <uptime_ms>`** — sent every 1000 ms (tunable), unconditionally,
  whether or not anything changed. Lets a listener confirm liveness without
  polling, same role as CAN's heartbeat.
- **`STATE <ch> <ON\|OFF>`** — sent once, immediately, whenever a channel's
  *applied* state actually changes, regardless of whether the change came
  from a `SET` command or (if the firmware ever drives a channel from
  local logic, e.g. a fault condition) some other cause. This is the line
  that closes the "fresh listener can't learn current state" gap: a host
  that opens the port and waits briefly will see either a `STATE` line
  (something changed recently) or can just send `STATUS` itself for an
  immediate full snapshot — either path works, unlike CAN's.

Because unsolicited lines can interleave with command responses, host-side
parsers must treat every line independently (check its first token) rather
than assuming "the next line is always my command's response."

## Errors

`ERR <code>` on any malformed/out-of-range/failed command. Suggested codes
(firmware implementer may extend, but keep the shape `ERR <UPPER_SNAKE>`,
no spaces in the code itself, so it stays one grep-able token):

- `ERR BAD_CHANNEL` — channel outside 1-10.
- `ERR BAD_ARGS` — wrong number of arguments / unparseable state token.
- `ERR UNKNOWN_CMD` — unrecognized command word.
- `ERR LINE_TOO_LONG` — see Framing.

## Fail-safe behavior — decided during implementation, 2026-08-05

`can-protocol-research.md`'s own heartbeat section recommends CAN command
loss (RPDO1 timeout) de-energize all channels rather than hold last state.
Whether the *same* watchdog should apply to this USB interface was left
open here on purpose. **Decided in `docs/features/FR-001.md`**: yes, for
philosophical consistency with the CAN path — a bench tool that behaves
differently from the real control path on "commander went away" was judged
the wrong default. Implemented as a 30000ms idle-activity timeout (any
received line, valid or malformed, resets it) — 6x longer than CAN's
5000ms RPDO1 timeout, since this is an interactive human-typed interface
where a person pausing to read output shouldn't trip the same threshold a
genuinely vanished CAN host should. Full rationale and the code:
`firmware/src/usb_bench/main.cpp` and `firmware/README.md`'s `usb_bench`
section.

## Explicitly out of scope for this spec

- A rigos-core-side bus backend (`orc_usb.py`) consuming this protocol —
  natural follow-up once this firmware exists, not needed for this spec to
  be useful (a human with a serial terminal is a complete consumer on its
  own).
- Multi-unit addressing — point-to-point only, see Transport.
- Binary/compact framing — deliberately ASCII, see Framing's rationale.
- Any change to the CAN protocol or the resolved CAN-exclusive production
  control path.

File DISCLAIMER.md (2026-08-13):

# Safety and liability disclaimer

Read this before building or installing anything in this repository.

This project publishes design information only. It is an unfinished, unvalidated engineering project shared for reference and education. Nothing here is a product, and nothing here is offered for sale.

**No warranty.** These design files, firmware, tools, and documents are provided "AS IS", without warranty of any kind, express or implied, including but not limited to warranties of merchantability, fitness for a particular purpose, non-infringement, and satisfactory quality. The entire risk as to the quality, performance, and safety of anything you build from this repository is yours.

**Not safety qualified.** This design has not been evaluated, tested, or certified by any safety, automotive, EMC, or regulatory body. It is not qualified to ISO 26262, SAE, FMVSS, UL, or any other standard. It has not been tested for electromagnetic compatibility or for automotive environmental, vibration, or thermal requirements.

**Do not use for safety-critical functions.** Do not use this design to control braking, steering, airbags, fuel systems, emergency warning equipment, medical equipment, or any other function where failure could cause injury, death, or property damage.

**High current and fire risk.** This design switches high-current DC loads from a vehicle battery. Incorrect wiring, undersized conductors, missing or wrong overcurrent protection, or a firmware fault can cause fire, burns, battery damage, vehicle damage, or injury. Overcurrent protection is an installation responsibility and is not provided by this board.

**Your responsibility.** Anyone who builds, modifies, installs, or operates hardware based on this repository is solely responsible for verifying its suitability, for all applicable safety and regulatory compliance, for correct installation, and for all consequences of its use. Modifying a vehicle's electrical system may void warranties, may violate vehicle regulations in your jurisdiction, and may affect insurance coverage.

**No liability.** To the maximum extent permitted by applicable law, the authors and contributors shall not be liable for any direct, indirect, special, incidental, consequential, exemplary, or punitive damages of any kind, however caused and on any theory of liability, whether in contract, warranty, tort (including negligence), product liability, or otherwise, arising in any way from this repository or from anything made or done using it.

If you are not competent to evaluate automotive DC power distribution and its failure modes yourself, do not build this.

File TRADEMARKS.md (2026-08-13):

# Trademarks and affiliation

ORC is an independent open-source project. It is not affiliated with, endorsed by, sponsored by, approved by, or connected to Motorola Solutions, Inc. or any of its subsidiaries or affiliates.

MOTOROLA, MOTOROLA SOLUTIONS, APX, and the Stylized M logo are trademarks or registered trademarks of Motorola Trademark Holdings, LLC or Motorola Solutions, Inc. All other trademarks are the property of their respective owners.

References in this repository to "Motorola", "PMUN1046A", or "APX" are nominative references, used solely to identify the donor hardware this project is built around and to describe compatibility accurately. No claim of ownership in those marks is made, and no sponsorship or endorsement is implied.

The name "ORC" stands for Open Relay Controller.

## Scope of the design

ORC does not implement, emulate, document, or interoperate with any Motorola proprietary protocol or interface, including the GCAI link used by the donor unit. The ORC controller board is an independent design that replaces the donor unit's controller board entirely. Control is plain CAN over standard terminal blocks.

No Motorola firmware, source code, schematic, drawing, photograph, or manual text is reproduced or redistributed in this repository. Where a fact about the donor unit is drawn from Motorola's published service or installation documentation, it is cited by section rather than reproduced.

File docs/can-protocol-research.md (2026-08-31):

# CAN protocol research — transport architecture and application-layer format

Research pass, 2026-08-01. Answers two questions gating ORC's CAN work: (1) is the
current GPIO21/GPIO20 UART-through-SN65HVD230 bring-up path actually capable of
real CAN, and (2) what should ride on top of it once it is. **No firmware or
schematic changes were made by this pass** — see `firmware/README.md` and
`docs/subcircuit-capture-guide.md`'s Communications/MCU sections for the current
state this builds on, and `docs/design-inputs.md`'s "Primary control path" entry
(resolved 2026-08-01: CAN, exclusively) for why this matters at all.

## 1. UART-vs-TWAI: the transport question, resolved

### Can the ESP32-C3's native TWAI controller reach GPIO21/GPIO20?

**Yes, and it isn't even a routing compromise — it's the more natural fit.** The
ESP32-C3's TWAI (Espressif's name for their CAN 2.0B-compatible protocol
controller) has **no dedicated IO_MUX pin at all**. Per the *ESP32-C3 Series
Datasheet* (v2.4) Table 3-2 and the *ESP32-C3 Technical Reference Manual*'s "IO MUX
and GPIO Matrix" chapter (Peripheral Signal List), TWAI TX/RX are GPIO-Matrix-only
signals — every GPIO-capable pin is an equally valid TWAI pin, selected purely in
firmware (`twai_general_config_t.tx_io` / `.rx_io` in ESP-IDF, or the Arduino-ESP32
`TWAIBus`/`twai.h` wrapper). GPIO21/GPIO20 are ordinary GPIOs with no competing
IO_MUX peripheral assignment that would block this. **This is a firmware
peripheral-configuration change, not a hardware redesign.** The SN65HVD230's
TXD/RXD pins are electrically identical 3.3 V logic inputs/outputs regardless of
which on-chip peripheral drives them — UART1 or TWAI — so no schematic or pinout
change follows from this finding. Confidence: high, primary source (Espressif
datasheet + TRM, both cited above).
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

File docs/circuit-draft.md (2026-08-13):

# ORC circuit draft — parts and topology

Working document for parts selection and topology, ahead of schematic capture in `hardware/`. Carries forward from [design-inputs.md](design-inputs.md); does not repeat facts already established there.

**Status: draft, not locked.** Several items below are flagged *unresolved* — do not order parts against those without a follow-up pass.

**For manual schematic capture, parts, and LCSC numbers**, see [subcircuit-capture-guide.md](subcircuit-capture-guide.md) — the decisions below organized by KiCad sheet with real net-level wiring, pulled from the live schematic's connectivity graph rather than this document's chronological decision log. (`hardware/BOM.md` was retired 2026-08-01 — redundant with that doc once it existed.)
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

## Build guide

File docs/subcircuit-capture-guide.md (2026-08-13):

# ORC subcircuit capture guide

Single source of truth for parts, LCSC numbers, and wiring — organized by the **actual KiCad sheet hierarchy** in `hardware/*.kicad_sch`. `hardware/BOM.md` was retired 2026-08-01 (redundant, drifted out of sync with the new sheets' ref numbering) — everything from it that was still current lives here now.

Five sheets exist today: Power Side A, Power Side B, MCU, Communications, I2C Isolator. Same one-sheet-per-function pattern continues for whatever gets captured next. **Root `orc.kicad_sch` is legacy** — its content is being superseded sheet-by-sheet, not maintained in parallel. Where a sheet below is missing parts a legacy-root block already had, that's flagged explicitly as **not yet migrated**, not a design change, unless stated otherwise.

**Ref designators were reassigned during the hierarchical split** — don't cross-reference old block-numbered refs (U1–U8, Q1–Q5, R1–R18 from the pre-split BOM) against these; use the ref shown in each sheet's table, which matches what's actually in the file today.

**Status legend** (carried from the old BOM.md): ✅ LCSC confirmed live · ⚠️ real part/value decided, tier or wiring detail still open · ❌ real unresolved gap · 🔧 KiCad-side symbol/footprint work needed, not a sourcing gap.

## OPEN ARCHITECTURE DECISION — MCU module, exact board TBD, don't source against U7/J4/U5/R11/R12 yet

**Mechanical finding, 2026-08-01**: only ~8.5mm clearance between the two stacked PCBs in the enclosure — not enough room for both a USB-C connector and the required DC+CAN screw terminal on a single-sided board.

**Resolved 2026-08-01 — chip family and wireless, both decided**: rather than solve the connector-placement problem, replace the bare ESP32-S3-WROOM-1U + custom USB-C/ESD/CC-pulldown circuit (U7, J4, U5, R11, R12 below) with a **complete pre-made ESP32-C3 module** ("ESP32-C3 Super Mini" class, USB-C already built in, ~$2-3/ea in bulk). Two decisions landed together:
- **Wireless (WiFi/BLE) dropped entirely** — CAN is now the sole control path, no config/monitoring path over WiFi. This retires design-inputs.md's external-antenna requirement outright: radio is never enabled in firmware, so a sealed metal enclosure blocking a PCB-trace antenna is no longer a real constraint. The plain (non-"Plus") C3 Super Mini's PCB-only antenna is fine now.
- **Chip family: ESP32-C3, not S3** — single-core RISC-V confirmed adequate. This board's whole job is CAN in (via the already-sourced SN65HVD230 transceiver, UART-framed) and driving the PCA9555 I2C GPIO expander out (through the ADuM1250 isolator) — light duty, doesn't need dual-core Xtensa or PSRAM.

**Board specifics, 2026-08-01** — sourcing pass complete, not yet applied to the schematic:

- **Chip**: bare **ESP32-C3FN4** die (RISC-V, 160MHz, 4MB flash, 400KB SRAM), not Espressif's official castellated ESP32-C3-MINI-1 module — a generic/widely-cloned board from many uncredited sellers, no single manufacturer. **QC flag**: some clone batches reportedly carry chips marked only "ESP32-C3" with no flash-size suffix that don't match the board's layout — worth a visual chip-marking check on receipt.
- **Pricing**: single-unit ~$3.68–3.82 (AliExpress), eBay 3-pack ~$2.33/unit. The "$2-3/ea bulk" figure is plausible and directionally consistent but **not confirmed at a specific quantity** — AliExpress blocks automated price-tier scraping (same JS-rendering limit as LCSC). Needs a manual browser check before locking into a BOM quantity/price.
- **Not on LCSC/JLCPCB** — confirmed this stays a separate hand-assembly sourcing line, not foldable into the main PCBA order. (LCSC does carry Espressif's *official* bare ESP32-C3-MINI-1-N4 module, C2838502, ~$2.12-2.47 — but that's a different part: no USB, no regulator, no buttons, meant for SMT reflow into a custom design, not a substitute for the dev-board module here.)
- **Form factor**: 22.5×18mm, 2×7-pin 0.1"/2.54mm through-hole headers (16 pins, 13 usable GPIO) — not castellated, needs pin headers/sockets or hand soldering, not reflow.
- **Buttons**: RST and BOOT both confirmed present onboard. **SW1/SW2 are now redundant** — don't build them into the schematic; just make sure the module's mounted so both buttons stay physically reachable.
- **Pinout**: I2C on GPIO8(SDA)/GPIO9(SCL), UART on GPIO21(TX)/GPIO20(RX), all broken to headers and otherwise unused. **GPIO9-as-BOOT-strap question — resolved 2026-08-01, safe, datasheet-cited, static analysis only (no hardware to confirm on yet)**: an idle-high I2C bus on GPIO9 does not conflict with the ROM boot-mode strap read. Per Espressif's *ESP32-C3 Series Datasheet* v2.4 §3 (Table 3-1/3-2/3-3, Figure 3-1), the strap read is a one-shot latch completing within a fixed **t_H ≥ 3 ms** window anchored to `CHIP_EN` release — before firmware runs and before the IO MUX/GPIO Matrix has routed the I2C peripheral onto GPIO8/9 at all (Table 2-1: GPIO9's at-reset/after-reset state is plain `IE, WPU`, not an I2C pin, until application code configures it, §4.1.3.1). GPIO9's documented default is a weak pull-up (bit=1=SPI boot, Table 3-1); an external I2C pull-up reinforces that same direction rather than fighting it — the only way to disturb the strap is to actively drive GPIO9 **low** during the ~3 ms window, which ordinary I2C (SCL pulled low only during firmware-initiated clock pulses, well after the strap read completes) cannot do. No published ESP32-C3 errata mention GPIO8/GPIO9/strapping/I2C. GPIO8 (SDA) is also a strapping pin (chip-boot-mode + UART-print-control) and is safe by the same timing argument, but defaults to **floating**, not pulled — the one real caveat carried forward: if some other I2C slave on this bus holds SDA low during its own power-on reset at the same instant as the ESP32-C3's `CHIP_EN` release, that could affect the GPIO8 strap read (only matters if GPIO9 also reads 0 at that instant, Table 3-3) — a general I2C power-sequencing hygiene point, not a reason to reassign pins. Full analysis and citations: `firmware/README.md`. Empirical confirmation on real hardware (via `firmware/src/i2c_scanner`) is still the right final check once a board exists — this closes the "needs confirming" static-analysis gap, not the "needs confirming on real hardware" one.
- GPIO8 driving the onboard LED on some clones (noted below) is a separate, cosmetic concern (an LED toggling as a side effect of I2C traffic) — not a strapping conflict, and doesn't block using GPIO8 as SDA.
- **USB**: USB-C confirmed. Native USB-Serial-JTAG (no CH340/manual BOOT-sequence needed) is likely but **one source claimed CH340** instead — varies by seller/revision, treat as unconfirmed until a specific listing's schematic is checked.

**Still open before this is schematic-ready**: pick and buy a specific listing (confirming real bulk pricing and the flash-marking QC risk directly), empirically confirm GPIO8/9 I2C-vs-strapping behavior on real hardware once it arrives (static/datasheet analysis is now done and says safe — see above; this remaining item is the bench-verification step, not an open question about the design), confirm native-USB vs. CH340 for that specific listing. **Don't source or lock U7/J4/U5/R11/R12 further, and don't remove SW1/SW2 from the schematic, until a specific listing is actually bought and confirmed** — this research covers the "Super Mini" class generically, not one verified purchasable SKU.

**GPIO reservation for node-ID DIP switch — superseded, see the "CAN node address" entry further down this section** (corrected 2026-08-04, to as-fabbed pins GPIO0–3, not the GPIO0/1/3/10 originally planned when this note was first written 2026-08-02, before the board was sent to fab). Kept here only as a pointer so this paragraph doesn't contradict the later, accurate one.

<details><summary>Superseded S3-module candidate research (2026-08-01, before the wireless/chip-family decision) — kept for record, not actionable</summary>

| Candidate | Antenna | USB | Flash/PSRAM | Size/mount | Buttons | Confidence |
|---|---|---|---|---|---|---|
| Unexpected Maker TinyS3 | ✅ Confirmed — u.FL on product page | USB-C, native | 8MB / 8MB PSRAM | 35×17.8mm, 4.3mm max thickness, pin-header pads | RESET + BOOT confirmed | High — cleared every requirement under the old (S3, external-antenna) constraints |
| Olimex ESP32-S3-DevKit-Lipo-EA | ✅ Confirmed on manufacturer page | USB-C ×2 | 8MB / 8MB | 27.94×55.88mm | RESET + BOOT/USER | Medium-High |
| Adafruit ESP32-S3 Feather 8MB w/ w.FL Antenna | ⚠️ w.FL/MHF3, not u.FL — pigtail mismatch | USB-C, native | 8MB / no PSRAM | Feather ~51×23mm | RESET + BOOT | Out of stock at Adafruit |
| Espressif ESP32-S3-DevKitC-1U-N8R8 | ✅ Best-documented | ❌ Micro-USB, disqualifying | 8MB / 8MB | 70×28mm THT header | RESET + BOOT | Disqualified on USB connector |

Superseded because the S3-and-external-antenna requirements that drove this table no longer apply.
</details>

**Side effect, unchanged from before**: dropping the custom USB-C ingress removes the VBUS-vs-DC-terminal source-select stage (Q1/Q3/Q4/Q5, still legacy-root-only) entirely — including Q4/Q5's gate-drive chain, which has been an unresolved electrical gap since early in the project. Domain A power ingress simplifies to just the DC terminal path, same shape as Domain B. SW1/SW2 (EN/BOOT buttons) likely become redundant too — C3 Super Mini boards typically have their own onboard RST/BOOT buttons, pending confirmation from the in-progress sourcing pass.

## Housekeeping — found in the 2026-08-01 documentation audit, not yet resolved

- **Catch diode value — resolved 2026-08-01: SS34 (C8678) is correct.** Root schematic's D2/D3 still show "SS56" (stale, predates the correction) — harmless since root is legacy and not sourced from, but don't let it confuse a future read of root.
- **D1 (SMBJ26CA, load-dump TVS) is still placed in root** even though the design decision to drop it was made and documented — the symbol was never deleted. Low priority since root is legacy, but noted so it isn't mistaken for a live requirement if root gets referenced.
- **Root's `J2` symbol carries "(C2827883)" embedded in its description field.** As of the latest Gate 1 pass this number is confirmed correct: DORABO DB128L-5.08-4P-GN-S, 5.08mm 4-pos screw terminal, C2827883 (Extended, 16A/300V, 28.9k stock). It's now carried in J6's LCSC column in Block 4.
- **Root has a stray `R4 22kΩ`** with no documented function anywhere in current or historical BOM content. Possibly a leftover from the dropped TVS/load-dump analysis network. Needs a function check before it's either sourced or written off as dead.
- **PCB is significantly out of sync with the current schematic** (checked 2026-08-01): the entire Power Side B subcircuit (U10/R26/L4/R27/D6) is placed in the schematic but absent from the PCB; U7 (ESP32) and U9 (ADuM1250) are also missing from the PCB despite their support passives being placed. What *is* on the PCB uses stale ref numbers from before the last schematic re-annotation (`U3`→`U8`, `R18`/`R19`→`R24`/`R25` are the same physical parts). Needs a `pcb_sync_from_schematic` pass once the schematic itself is further along — resyncing now would just need to happen again.
- **Still unresolved from the prior pass**: J5 (Communications, 2-pin header — unclear role), R13 (Communications, 10kΩ 0.1% — unclear role), and a bare `GND` power symbol on the MCU sheet where everywhere else uses `GND_A` specifically. (SW1's function is resolved — see MCU sheet — and it's the same part as the still-to-be-placed SW2/BOOT button.)
- **kicad-mcp-pro `sch_update_properties`/`sch_modify_property` write-guard false positive, found 2026-08-02**: on `power_side_a.kicad_sch`, both tools refused *every* write attempt (even a plain Value-only change) with "the schematic mutation dropped structure (wire 12→10)". Root cause: the sheet has two places where three collinear wire segments meet at a T-junction (a pass-through point plus a stub) — the tool's own serializer merges each collinear pair into one wire on round-trip (12→10, exactly two merges), then its own safety check flags that merge as data loss and aborts the write. Not caused by the edit being attempted; happens on any write to this specific file via these two tools. Worked around by editing the `.kicad_sch` text directly (Read/Edit) instead of the MCP property tools — confirmed safe via `git diff` (only the intended property lines changed) and `sch_get_symbols` (values read back correctly). If this recurs on another sheet, check `sch_get_wires` for collinear T-junctions before assuming the requested edit is the problem.

---

## Power Side A — `power_side_a.kicad_sch`

**Purpose**: Domain A buck regulator, VIN → 3V3_A.

**IC: LMR50410XDBVR, SOT-23-6, LCSC C2841056** — confirmed live via `lib_get_component_details`: Extended tier, 4,643 in stock, $0.43/unit. Synchronous (integrated low-side FET, no external catch diode), fixed 700kHz switching, PFM light-load mode. Picked over the FPWM variant (LMR50410XFDBVR, C5219371) — its stock was checked and found too low for this build. Full sourcing history and the board-space rationale for moving off the original LM2596S-ADJ/TO-263 design: circuit-draft.md, "Buck IC switched to LMR50410."

**KiCad sheet not yet redrawn against this decision** — U8/L3/D5/R24/R25 as currently placed are the retired LM2596S-ADJ design and need replacing with the parts below.

**Parts to place**:

| Ref | Value / part | Function | LCSC | Status |
|---|---|---|---|---|
| U8 | LMR50410XDBVR | Buck regulator | C2841056 | ✅ SOT-23-6, 4–36V, 1A, synchronous, confirmed live (Extended, 4,643 stock, $0.43) |
| L3 | **33µH, Chilisin LVS606045-330M-N** | Buck inductor | C285825 | ✅ confirmed live: SMD 6×6mm, 1.4A rated / 2.3A saturation, 165mΩ DCR, Extended, 1,052 stock, $0.069. **Same part reused for L4** (Power Side B) — user's explicit call for BOM line count. Sized against the coil rail's revised 0.7A max expected load (see L4's note); comfortably oversized for this 3.3V rail's own ~0.2-0.5A load. Stepped up from an earlier 4×4mm/840mA-rated pick (SNR4030-330MT, C5127398) once the coil-rail load estimate was revised — that part's margin got too thin at the new number, see L4's note and circuit-draft.md. |
| D5 | — | Catch diode | — | **Removed** — LMR50410 is fully synchronous, no external catch diode needed |
| R24 | 2.7kΩ ±1% 0603, UNI-ROYAL 0603WAF2701T5E | FB divider, bottom (RFBB) | C13167 | ✅ confirmed live: **Basic tier**, 1,404,867 stock, $0.0010. Re-sourced 2026-08-02 (was 43.2kΩ/C23053, Extended) to close every FB resistor at Basic tier — different RFBT/RFBB pair than the original computation, same ~3.3V target. |
| R25 | 6.2kΩ ±1% 0603, UNI-ROYAL 0603WAF6201T5E | FB divider, top (RFBT) | C4260 | ✅ confirmed live: **Basic tier**, 352,385 stock, $0.0010. Re-sourced 2026-08-02 (was 100kΩ/C22936) — no longer shared with R26, each instance now has its own RFBT/RFBB pair chosen from the Basic-tier value set. Vout = 1.00×(1+6.2k/2.7k) = **3.30V** (−0.11%). |
| — | 2.2µF X7R ceramic, ≥50V | CIN bulk | *not yet sourced* | ⚠️ open — value/type from LMR50410 datasheet (§9.2, direct PDF read) |
| — | 0.1µF X7R ceramic | CIN high-freq bypass | *not yet sourced* | ⚠️ open |
| — | Small tantalum or polymer, value TBD | CIN damping cap | *not yet sourced* | ⚠️ open — datasheet flags a long-input-lead resonance risk; this board's automotive harness feed is exactly that case, so a small damping cap stays even though CIN is otherwise all-ceramic. Sized for damping, not bulk storage — far smaller than the electrolytic can this design used to carry. |
| — | 22µF X7R ceramic | COUT | *not yet sourced* | ⚠️ open — single cap per datasheet Table 9-1, no bulk cap needed |
| — | 0.1µF X7R ceramic, ≥16V | CBOOT | *not yet sourced* | ⚠️ open |

**Wiring**: `VIN_BUCK_A` → U8 Vin; CIN (2.2µF + 0.1µF ceramic + damping cap) across Vin↔GND_A at the IC pins; switch node `SW_A` → L3 → `3V3_A` output; COUT (22µF ceramic) across `3V3_A`↔GND_A; CBOOT between U8's BOOT pin and `SW_A`; FB divider `3V3_A` → R25 (6.2kΩ) → `FB_A` → U8 FB, R24 (2.7kΩ) → `GND_A`. Vout = 1.00×(1+6.2k/2.7k) = **3.30V**.

---

## Power Side B — `power_side_b.kicad_sch`

**Purpose**: Domain B (coil-drive) buck regulator, V_COIL_IN → COIL_9V.

**Same IC as Power Side A**: LMR50410XDBVR, C2841056. Same sourcing/rationale — see Power Side A above and circuit-draft.md's "Buck IC switched to LMR50410."

**KiCad sheet not yet redrawn against this decision** — U10/L4/D6/R26/R27 as currently placed are the retired LM2596S-ADJ design and need replacing with the parts below.

**Parts to place**:

| Ref | Value / part | Function | LCSC | Status |
|---|---|---|---|---|
| U10 | LMR50410XDBVR | Buck regulator | C2841056 | ✅ same part as U8 |
| L4 | **33µH, Chilisin LVS606045-330M-N** | Buck inductor | C285825 | ✅ same part as L3 — consolidated 2026-08-02 for BOM line count, **re-sourced same day after the coil-rail max expected load was revised from 0.45A to 0.7A**. At 28.8V/9V/700kHz, 33µH gives ripple current ΔIL≈268mA (unchanged by the load revision — ΔIL depends on Vin/Vout/fsw/L, not Iout), KIND≈0.383 at the new 0.7A load (was 0.595 at 0.45A — actually more comfortable now, well inside the 0.2-0.6 range). The load revision instead changed the *current-rating* margin: the original 4×4mm pick (SNR4030-330MT, 840mA rated/1.1A sat, C5127398) only cleared 0.7A by ~1.2× rated/~1.3× saturation — too thin for a sealed 65-85°C enclosure per this project's own PTC-derating lesson. New part clears with real margin: 1.4A rated / 0.7A = **2.0× rated-current margin**; 2.3A saturation / 0.834A peak (0.7A + ΔIL/2) = **~2.76× saturation margin**. See circuit-draft.md for the full math. |
| D6 | — | Catch diode | — | **Removed** — same reasoning as D5. Note: D6 was also the flyback-diode candidate for the relay board itself — that's a separate, still-open question (bench inspection needed), unaffected by this IC's own catch-diode removal |
| R26 | 24kΩ ±1% 0603, UNI-ROYAL 0603WAF2402T5E | FB divider, top (RFBT) | C23352 | ✅ confirmed live: **Basic tier**, 450,302 stock, $0.00099. Re-sourced 2026-08-02 (was 100kΩ/C22936, shared with R25) — LMR50410's recommended RFBT range is 10-100kΩ, 24kΩ is inside it. |
| R27 | 3kΩ ±1% 0603, UNI-ROYAL 0603WAF3001T5E | FB divider, bottom (RFBB) | C4211 | ✅ confirmed live: **Basic tier**, 3,745,756 stock, $0.00099. Re-sourced 2026-08-02 (was 12.4kΩ/C22865, Extended). Vout = 1.00×(1+24k/3k) = **9.00V exact**. |
| — | 2.2µF X7R ceramic, ≥50V | CIN bulk | *not yet sourced* | ⚠️ open, same as Power Side A |
| — | 0.1µF X7R ceramic | CIN high-freq bypass | *not yet sourced* | ⚠️ open |
| — | Small tantalum or polymer, value TBD | CIN damping cap | *not yet sourced* | ⚠️ open, same long-input-lead reasoning as Power Side A |
| — | 22µF X7R ceramic | COUT | *not yet sourced* | ⚠️ open |
| — | 0.1µF X7R ceramic, ≥16V | CBOOT | *not yet sourced* | ⚠️ open |

**No feedforward cap** — unlike the old LM2596 design (which needed one on this 9V rail per TI's Table 9-6), LMR50410's datasheet doesn't mention Cff anywhere; internal compensation handles it unconditionally regardless of RFBT or Vout.

**Wiring**: `V_COIL_IN` → U10 Vin; CIN network as above; switch node `SW_B` → L4 → `COIL_9V`; COUT (22µF ceramic) across `COIL_9V`↔GND_B; CBOOT between U10's BOOT pin and `SW_B`; FB divider `COIL_9V` → R26 (24kΩ) → `FB_B` → U10 FB, R27 (3kΩ) → `GND_B`. Vout = 1.00×(1+24k/3k) = **9.00V**.

**Wiring (stale — LM2596-era)**: `V_COIL_IN` → U10 Vin, switch node `SW_B` → L4 → `COIL_9V`; D6 on `SW_B`↔`GND_B`; FB divider `COIL_9V` → R26 → `FB_B` → U10 FB, R27 → `GND_B`. Vout = 1.23×(1+7500/1200) = **8.92V** (LM2596-era math).

---

## MCU — `mcu.kicad_sch`

**Purpose**: ESP32-C3 "Super Mini" class module, plus its entrance decoupling. **Fully rebuilt 2026-08-02** to implement the 2026-08-01 architecture pivot (see OPEN ARCHITECTURE DECISION above) — the bare ESP32-S3-WROOM-1 + custom USB-C/ESD/CC-pulldown circuit (old U7, R15–R17, SW1/SW2, C15) is gone from this sheet entirely, replaced by a single pre-made module symbol. **Symbol widened and pin table corrected again later the same day** once real reference data arrived — see the two dated passes below.

**⚠️ Everything on this sheet is a placeholder pending a bought listing.** No specific "ESP32-C3 Super Mini" SKU has been purchased yet (see OPEN ARCHITECTURE DECISION's "Still open" line). The symbol and footprint are now built from real reference data (a pinout guide + a dimensioned product photo, both user-supplied), which is considerably better than yesterday's from-doc-prose reconstruction, but neither is tied to one specific bought listing — treat every number here as "real but generic," not "confirmed for this exact SKU," until one is bought and checked.

**Parts placed today**:

| Ref | Value / part | Function | LCSC | Status |
|---|---|---|---|---|
| U7 | **ESP32-C3-SuperMini** (custom symbol/footprint, `AramLib:ESP32-C3-SuperMini`) | MCU module | — (not on LCSC, see OPEN ARCHITECTURE DECISION — AliExpress/eBay hand-assembly line) | 🔧 placeholder part — see caveats below |
| C14 | 10µF/25V, Samsung | 3V3_A bulk decoupling, module entrance | C96446 | ✅ same part reused from the old S3 circuit — repurposed, not resourced |
| C16 | 0.1µF/50V, Samsung | 3V3_A local bypass, module entrance | C14663 | ✅ same part reused from the old S3 circuit — repurposed, not resourced |

**Removed from this sheet** (all obsolete under the new architecture, per OPEN ARCHITECTURE DECISION's explicit call): C15 (was an EN-RC cap / entrance-dup, ambiguous even before the pivot — dropped, not carried forward), R15/R16/R17 (bare-chip strap/EN pull-ups — the module handles its own strapping internally), SW1/SW2 (EN/BOOT buttons — module has onboard RST/BOOT buttons per the sourcing pass), and the bare ESP32-S3-WROOM-1 symbol/footprint/USB-C-adjacent nets. The USB_N/USB_P global labels are also gone — the module's USB-C connects to its own onboard chip's native USB internally, never reaching this board's headers. **No separate EN pin is exposed either** (see below) — the RST button ties EN to GND onboard, so a header-level EN connection was never actually needed.

**Symbol/footprint — built from scratch, no stock KiCad asset exists for this class of board.** Checked `RF_Module:ESP32-C3-DevKitM-1`, `RF_Module:ESP32-C3-WROOM-02(U)`, and `RF_Module:WEMOS_C3_mini` — the last is the closest real candidate but is a **different, larger, differently-labeled board** (official Wemos/LOLIN product, ~34×25mm, 2×8 pins with Arduino-style `D0`–`D10` aliases) — using it would have silently drawn the wrong physical footprint, defeating the whole point of this pivot (the 8.5mm clearance finding). Built a custom part instead, in two passes:

**Pass 1 (morning, 2026-08-02)** — from-doc-prose reconstruction: 16 pins, 4 left (5V/3V3/GND/EN) + 12 right (IO0–7 + 4 named), lopsided and cramped. Footprint used estimated 22.5×18mm body / 20.32mm row pitch (both guesses, and width/height were effectively transposed).

**Pass 2 (afternoon, 2026-08-02)** — corrected against real references the user supplied:
- [lastminuteengineers.com's ESP32-C3 Super Mini pinout reference](https://lastminuteengineers.com/esp32-c3-super-mini-pinout-reference/) confirmed: 2 rows of 8 pins (16 total) at 2.54mm pitch; the real GPIO set is **GPIO0–10 + GPIO20 + GPIO21 = 13 GPIO** (not the 12 Pass 1 had — Pass 1 dropped GPIO10 to force-fit a 3V3 pin into budget); **3V3 is genuinely bidirectional** ("if you have a highly stable 3.3V external battery or power supply, you can use the 3V3 pin as an input") — directly validates this sheet's `+3V3_A`-backfeeds-the-module wiring, upgrading it from an assumption to a documented board feature; and a **third strapping pin, GPIO2**, not previously analyzed (`firmware/README.md` only covered GPIO8/9) — GPIO2 is currently unused/spare in this design, flag for later if it's ever pressed into service.
- A real **dimensioned product photo** (18.00mm wide × 22.52mm tall, 15.24mm header row pitch) corrected the footprint's actual geometry — Pass 1's estimate had width/height essentially swapped and the pitch wrong by ~5mm. This was the single highest-priority number to get right, since the whole pivot exists because of an 8.5mm clearance problem.
- **Reconciled the pin budget cleanly this time, no invented tradeoffs**: 13 GPIO + 5V + 3V3 + GND = 16 exactly, **with no separate EN pin** — the module's onboard RST button already ties EN to GND, so EN doesn't need its own header connection at all. (Pass 1 had invented dropping a GPIO to make room for both 3V3 *and* EN; dropping the unnecessary EN pin instead means all 13 real GPIO fit with zero compromises.)
- **Symbol widened and rebalanced** per explicit request: body half-width doubled (5.08mm→10.16mm), pin length doubled (2.54mm→5.08mm), and the lopsided 4-left/12-right split rebalanced to a clean 8-left/8-right (matching the real board's own 2×8 physical count, though — important — **this schematic-diagram left/right split is a readability choice only and does not claim to reproduce the real board's physical silkscreen layout**; only the footprint's pad *positions* carry physical-accuracy weight, and that's a separate, still-open item below).
- **Footprint pad numbering reworked to match the symbol 1:1** (pad N = symbol pin N = the same net, guaranteed by construction) — pads 1–8 left column top-to-bottom, 9–16 right column top-to-bottom, at the confirmed real 18.00×22.52mm body / 15.24mm row pitch / 2.54mm pin pitch.
- **Still explicitly open**: the footprint's pad *arrangement* (which physical corner has which real pin) is not confirmed against the actual board. The photo shows `5V`/`G`/`3.3` at the top of the board's **right** column with `GPIO21`/`GPIO0` at the bottom-left/bottom-right corners — this footprint's pad 1 (`5V`) currently sits on the **left**, a real unresolved mismatch. Several pins (especially the left column's upper half) aren't legible in the one photo available. **Deliberately not guessed at further** — user has taken the mechanical/physical side of this work; what's fixed today is internal consistency and real dimensions, not real-silkscreen fidelity.
- **New library infrastructure** (unchanged from Pass 1, still in place): `hardware/fp-lib-table` (→ `hardware/AramLib.pretty/`) and `hardware/sym-lib-table` (→ `hardware/AramLib.kicad_sym`) — both resolvable, `lib_search_symbols`/`lib_search_footprints` find `AramLib:ESP32-C3-SuperMini` correctly. Pre-existing `AramLib:SS14`/`AramLib:TS-1187A-B-A-B` footprints still not backfilled into these tables — out of scope, infrastructure exists for later if wanted.

**Wiring**: `+3V3_A` → module 3V3 pin (bypasses the module's own onboard 5V→3.3V regulator entirely — **module 5V pin left unconnected**, since Power Side A's buck (U8) already regulates 3V3_A independently; **now a documented board feature per the pinout reference, not just an assumption**). `GND_A` → module GND pin. Both power taps and the C14/C16 decoupling pair each get their **own separate power-symbol instances** directly at their own pins (not chained through a shared rail) — avoids a wire-merge/junction pitfall hit twice already today (see logbook). `SDA_A`/`SCL_A`/`UART_RX_A`/`UART_TX_A` global labels → module `IO8_SDA`/`IO9_SCL`/`IO20_RX`/`IO21_TX` pins respectively (same net names as before, so I2C Isolator and Communications sheets need no changes). Module `IO0`–`IO7` and `IO10` (9 spare GPIO) left unconnected with explicit no-connect flags — genuinely spare, no function assigned yet.

**Nets present**: `+3V3_A`, `GND_A`, `SCL_A`, `SDA_A`, `UART_RX_A`, `UART_TX_A`.

**ERC status, 2026-08-02 (Pass 2)**: clean except for the same expected single-sheet-isolation artifacts as Pass 1 (`GND_A`/`IO20_RX` "not driven," 4 global labels "connected to only one pin," 2 cosmetic `AramLib`-library warnings from `kicad-cli` not yet picking up the lib tables). No real connectivity errors this pass — Pass 1 briefly hit a "pin not connected" false-negative from two collinear wires merging around a mid-path power symbol (fixed then with an explicit junction); Pass 2 avoided the whole class of bug by giving every power tap its own dedicated symbol instance instead of chaining wires.

**Open items**:
- Pick and buy a specific "ESP32-C3 Super Mini" listing, then reconcile the footprint's pad *arrangement* (not its dimensions, already real) against the real silkscreen — this is now the single biggest remaining gap on this sheet.
- Confirm native-USB vs. CH340 for whatever specific listing gets bought.
- `firmware/`'s pin assignment (GPIO8/9 I2C, GPIO20/21 UART) is unaffected by any of today's sheet rebuilds — those GPIO numbers are unchanged, just now expressed through the new module symbol's pins. GPIO2's newly-flagged strapping caution should get the same class of check GPIO8/9 already got, whenever GPIO2 is first used for something.
- **CAN node address — assigned 2026-08-02 (board sent to fab that day), corrected 2026-08-04 to match what was actually built.** A 4-bit configurable CAN node address (0-15) is wired directly to the MCU's own Domain A GPIOs rather than through the PCA9555 (which lives on the galvanically-isolated Domain B side — address-select logic belongs with the MCU that actually forms CAN arbitration IDs, not across the isolation barrier). **As-fabbed pins: `NODE_ID0`-`NODE_ID3` → `IO0`-`IO3`** (a contiguous block — confirmed against `hardware/mcu.kicad_sch`'s U7 pins 9-12), each with an external 10kΩ pulldown to `GND_A` and a switch/jumper to `+3V3_A` (open=0, closed=1), read as plain digital inputs by firmware. **This is not the pin set originally planned on 2026-08-02** (GPIO0/1/3/10, chosen specifically to avoid GPIO2 as a strapping pin) — the board went to fab with `IO0`-`IO3` instead, which includes GPIO2. `firmware/lib/orc_can_addr/orc_can_addr.h` and `firmware/README.md` have both been corrected to match the real board. **GPIO2 strapping safety re-verified given it's now load-bearing on a fabbed board, not a design choice**: Espressif's *ESP32-C3 Series Datasheet* v2.4 Table 3-3 ("Chip Boot Mode Control") shows GPIO2 = "Any value" (don't-care) whenever GPIO9 = 1, and this board's own I2C pull-up (R21, `SCL_A`) holds GPIO9 = 1 at every reset — so neither address-switch position on GPIO2 can affect boot mode. Table 3-3's own footnote states directly: "GPIO2 actually does not determine SPI Boot and Joint Download Boot mode." No published ESP32-C3 errata mention GPIO2. **Verdict: safe as fabbed, no rework needed.** `IO4`-`IO7` and `IO10` remain genuinely spare (5 GPIO left after this assignment) — `IO10` in particular was the original plan's bit3 pin but isn't wired to anything address-related on the real board.

---

## Communications — `communications.kicad_sch`

**Purpose**: USB-C connector, CAN transceiver, CAN termination, and USB ESD protection — combines the old ingress and CAN/ESD blocks into one sheet.

**Parts placed today**:

| Ref | Value / part | Function | LCSC | Status |
|---|---|---|---|---|
| J4 | USB-C receptacle, Hroparts TYPE-C-31-M-12 | USB-C VBUS/data ingress | C165948 | ⚠️ Basic/Extended tier not confirmed live |
| R11 | 5.1kΩ ±0.1%, 0402, YAGEO RT0402BRD075K1L | **USB-C CC1 Rd pull-down — closes a previously-flagged open item** (USB-C spec requires this for the port to be recognized by a host at all) | C852856 | ✅ Extended, ±25ppm/℃ thin film, 72k stock |
| R12 | 5.1kΩ ±0.1%, 0402, YAGEO RT0402BRD075K1L | USB-C CC2 Rd pull-down (pair with R11) | C852856 | ✅ same part as R11 |
| J5 | 01x02 header | Unclear function — doesn't match any legacy-root part at this position | — | ❌ needs a label/purpose check before sourcing |
| J6 | 5.08mm screw terminal, 4-pos, DORABO DB128L-5.08-4P-GN-S | DC + CAN field terminal | C2827883 | ✅ Extended, 16A/300V, 12-22 AWG, 28.9k stock. The root's "C2827883" number is confirmed correct after a Gate 1 pass |
| U6 | SN65HVD230 | CAN transceiver, 3.3V native | C12084 | ⚠️ Basic/Extended tier not independently confirmed live. ±16kV HBM ESD on bus pins built in — no external CAN ESD part needed |
| U5 | USBLC6-2SC6 | USB D+/D- ESD array | C2827654 | ⚠️ SOT-23-6, Extended tier verified live. Check series-vs-parallel insertion (legacy root wired it as a parallel stub, not true series — worth doing properly on this fresh capture) |
| C13 | 100nF | U6 VCC bypass, at the pin | — | ⚠️ generic |
| R13 | 10kΩ ±0.1% | Unclear function — doesn't match any known legacy-block role; nothing else on this design uses 0.1% except R11/R12 (which are 5.1k, not 10k) | — | ❌ flag for a wiring check, don't assume it's a stray |
| R14 | 120Ω ±1% 1206, UNI-ROYAL | CAN bus termination | C17909 | ✅ Basic |

**Nets present**: `CAN_H`, `CAN_L`, `UART_RX_A`, `UART_TX_A`, `USB_N`, `USB_P`.

**Not yet migrated from legacy root**: the reverse-polarity/source-select stage (Domain A power ingress — reverse-polarity FET, USB-presence-detect gate drive, PTC fuse) doesn't appear on Communications, Power Side A, or any other new sheet yet — still only in root. Given J4 already lives here, this stage likely belongs on Communications too, but that's an open placement call. **This stage is also known-electrically-incomplete even in legacy root** — a single NPN pulling toward GND can't turn a high-side P-FET off; the gate-drive chain (root's Q4/Q5-equivalent) likely needs a second stage properly derived before it's worth recapturing as-is.

Also not yet migrated: the CAN termination jumper (2.54mm header+shunt, C36717/C5305, field-removable) — confirm whether R14's termination is now hardwired or the jumper just isn't placed yet.

---

## I2C Isolator — `i2c_isolator.kicad_sch`

**Purpose**: the entire Domain A↔B galvanic isolation barrier.

**Parts placed today**:

| Ref | Value / part | Function | LCSC | Status |
|---|---|---|---|---|
| U9 | ADuM1250ARZ-RL7 | 2-channel isolated I2C buffer — the entire A↔B barrier | C13839 | ✅ part confirmed; isolation-voltage/data-rate figures not re-verified against ADI's Rev. L table |
| C17 | 100nF | Primary-side decoupling | — | ⚠️ generic 0603 |
| C18 | 100nF | Secondary-side decoupling | — | ⚠️ generic 0603 |
| R20 | 10kΩ ±1% 0603, UNI-ROYAL | SDA_A pull-up | C25804 | ✅ |
| R21 | 10kΩ ±1% 0603, UNI-ROYAL | SCL_A pull-up | C25804 | ✅ |
| R22 | 10kΩ ±1% 0603, UNI-ROYAL | SDA_B pull-up | C25804 | ✅ |
| R23 | 10kΩ ±1% 0603, UNI-ROYAL | SCL_B pull-up | C25804 | ✅ |

**Nets present**: `SCL_A`, `SCL_B`, `SDA_A`, `SDA_B`, plus power symbols `+3V3_A`/`GND_A` (primary side) and `+3V3_B`/`GND_B` (secondary side).

**Not yet migrated**: nothing obvious — this reads as a complete, self-contained migration of the old barrier block. Worth a `run_erc` pass specifically on this sheet to confirm.

**Nothing else crosses the barrier, deliberately** — if there's ever a temptation to add a second isolated signal (e.g. a fault/interrupt line), that's a topology decision to flag, not just wire. The design polls status over the existing I2C link instead.

---

## Not yet captured into any sheet — still legacy-root-only

Whoever captures these next should give them their own sheet(s), following the same one-function-per-sheet pattern above. No names are reserved — that's an open call for whoever does the capture.

### Domain B power ingress

| Ref (legacy) | Value / part | Function | LCSC | Status |
|---|---|---|---|---|
| F2 | 0.75A PTC, Littelfuse-class | Domain B input resettable fuse | C207083 | ⚠️ **check 85°C-derated hold current against the actual load before trusting this as protection** — a prior PTC selection pass on this exact project already caught one part (2920L075/60) that derates to 0.34A at 85°C, below its intended load. Confirm this part's derating table directly. |
| F1 | 0.75A PTC, Littelfuse-class | Domain A input resettable fuse | C207083 | ⚠️ same part/caveat as F2 |
| Q2 | **DMP4015SK3Q-13** (Diodes Inc.) | Domain B reverse-polarity FET — replaces an undersized SOT-23 AO3401A placeholder | C461089 | ⚠️ sourced live 2026-08-01: TO-252 (DPAK), P-ch, Vds -40V (25% margin over 32V worst-case input), Id -35A (50× the ~0.7A load), Rds(on) 7mΩ@10V/9mΩ@4.5V, **AEC-Q101 qualified**, 1,544 in stock. Clears every requirement with large margin — spec confidence High. **Tier not confirmed**: stock depth/price suggest Extended, not independently confirmed. **This is a package change from the placeholder (TO-252 vs SOT-23), not just a value swap — needs a new footprint, not a property edit.** |

### Domain B logic supply

**Resolved 2026-08-02, user confirmed — was flagged as a contradiction earlier the same day.** This table's `COIL_9V → 3.3V` wiring is correct: U6 powers the PCA9555 I2C GPIO expander and the ADuM1250 isolator's Domain-B-side. circuit-draft.md's topology diagram previously said this rail sourced from harness A+ directly — that diagram caption was the stale one and has been corrected to match this table. Not blocking regardless (the coil-supply-gating feature that would have made the earlier ambiguity dangerous was proposed and reverted the same day, so nothing currently depends on `COIL_9V` surviving an outage). **U6 now sourced too** (C6186, confirmed Basic tier — see table below) — this section is fully closed.

| Ref (legacy) | Value / part | Function | LCSC | Status |
|---|---|---|---|---|
| U6 | AMS1117-3.3 | Domain B logic LDO, COIL_9V → 3.3V | C6186 | ✅ confirmed live via `lib_get_component_details` (jlcsearch), 2026-08-02: SOT-223, **Basic tier**, 1,490,681 in stock, ~$0.151/unit |
| C14/C15 (legacy refs) | 10µF ×2 | LDO in/out | — | ⚠️ generic |

### PCA9555 I2C GPIO expander

| Ref (legacy) | Value / part | Function | LCSC | Status |
|---|---|---|---|---|
| U5 (legacy ref) | PCA9555PW,118 (NXP) | I2C GPIO expander, addr 0x20, 10-of-16 I/O used, 6 spare | C128392 | ⚠️ re-pulled live 2026-08-01, 8,773 in stock, TSSOP-24. Basic/Extended tier not confirmed (badge didn't render to automated fetch). **Temp margin thin**: datasheet rated −40 to +85°C against this enclosure's 65–85°C ambient — near-zero headroom for self-heating above bulk ambient, same class of concern as the PTC 85°C-derating finding. Address 0x20 is set by A0–A2 board strapping, not part-number-specific. |
| C16 (legacy ref) | 0.1µF | Decoupling | — | ⚠️ generic |

**Channel mapping — read directly off `hardware/i2c_expander.kicad_sch` (U1), 2026-08-04.** This is the canonical source for firmware channel numbering; do not re-derive it from `firmware/src/pca9555_bringup/main.cpp`'s current assumption (channels 1-8 sequential on Port 0, 9-10 on Port 1 low bits) — that assumption predates this schematic check and is wrong on both port-bit alignment and channel order.

| Pin # | Signal | Register bit | Net | Coil channel |
|---|---|---|---|---|
| 4 | IO0_0 | P0.0 | — | unused (spare) |
| 5 | IO0_1 | P0.1 | — | unused (spare) |
| 6 | IO0_2 | P0.2 | — | unused (spare) |
| 7 | IO0_3 | P0.3 | COIL10_EN | Channel 10 |
| 8 | IO0_4 | P0.4 | COIL8_EN | Channel 8 |
| 9 | IO0_5 | P0.5 | COIL6_EN | Channel 6 |
| 10 | IO0_6 | P0.6 | COIL4_EN | Channel 4 |
| 11 | IO0_7 | P0.7 | COIL2_EN | Channel 2 |
| 13 | IO1_0 | P1.0 | COIL1_EN | Channel 1 |
| 14 | IO1_1 | P1.1 | COIL3_EN | Channel 3 |
| 15 | IO1_2 | P1.2 | COIL5_EN | Channel 5 |
| 16 | IO1_3 | P1.3 | COIL7_EN | Channel 7 |
| 17 | IO1_4 | P1.4 | COIL9_EN | Channel 9 |
| 18 | IO1_5 | P1.5 | — | unused (spare) |
| 19 | IO1_6 | P1.6 | — | unused (spare) |
| 20 | IO1_7 | P1.7 | — | unused (spare) |

Spares are the low 3 bits of Port 0 and the high 3 bits of Port 1 — not a contiguous block, and channel order (10,8,6,4,2 then 1,3,5,7,9) is not sequential either; routing-driven, not a numbering scheme. Implied register values:

| Register | Value | Reasoning |
|---|---|---|
| Config P0 (cmd 0x06) | `0x07` | bits 0-2 input (unused), bits 3-7 output |
| Config P1 (cmd 0x07) | `0xE0` | bits 0-4 output, bits 5-7 input (unused) |
| Output P0 bit for coil N (N even, 2-10) | bit `(10-N)` | e.g. coil 10 → P0.3, coil 2 → P0.7 |
| Output P1 bit for coil N (N odd, 1-9) | bit `(N-1)/2` | e.g. coil 1 → P1.0, coil 9 → P1.4 |

**Resolved 2026-08-05**: the real mapping above is now implemented in `firmware/lib/orc_relay_map/orc_relay_map.h` (a new shared lib, single source of truth for this table in firmware) — `pca9555_bringup`'s `setChannel()` corrected to use it, and the new `canopen_app` application firmware (RPDO1/TPDO1 handling) uses it too, catching what would otherwise have been a real bug in ORC's first application firmware before it ever ran. `kConfigPort0Outputs`/`kConfigPort1Mask` replaced by `kOrcPca9555ConfigPort0`/`kOrcPca9555ConfigPort1` (`0x07`/`0xE0`, matching this table exactly) in the same lib. All affected firmware environments rebuilt and re-verified.

**Real-hardware confirmed, 2026-08-10** — first end-to-end verification of this table against the actual fabricated board, not just internal firmware/schematic consistency: `pca9555_bringup` flashed to a real, powered ORC PCB and run through its full walking-single-HIGH pattern (channels 1-10 in sequence). User followed along with a DMM in continuity mode on the coil harness pins and confirmed each printed `Channel N HIGH` corresponds to the correct physical channel N — all 10, no swaps, no misses. This is the strongest confirmation this table has had: schematic → `orc_relay_map.h` → real silicon → real coil driver stage → real harness pin, checked at every hop.

### Per-channel coil driver ×10 (channels 1–10)

Identical stage repeated for each relay channel: `RBn` (PCA9555 output → NPN base) → `QNn` (level-shift NPN) → `RPn` (gate pull-up) → `QPn` (high-side coil switch) → harness pin `n+2`.

**Digital-transistor (pre-biased NPN) option evaluated and rejected, 2026-08-01**: considered replacing QNn+RBn with a single "digital transistor" (built-in base + base-emitter bias resistors, e.g. onsemi MMUN2211LT3G, C150229, R1=13kΩ, 13,980 in stock) to eliminate RB1-10 entirely. **Rejected on economics**: MMUN2211LT3G's Basic/Extended tier never confirmed after checking directly (same recurring JLCPCB-badge issue), and if it's Extended that's a flat $3/order reel-loading fee to displace parts (MMBT3904 + discrete resistors) that are already Basic and already loaded. Not worth the risk for an unconfirmed area saving. Went with resistor arrays instead (below) — same area-saving goal, zero tier risk.

| Ref | Value / part | Function | LCSC | Status |
|---|---|---|---|---|
| RB1–RB10, RP1–RP10 | **UNI-ROYAL 4D03WGJ0103T5E**, isolated 4×10kΩ array, 0603x4 (8-pin, 4 independent 2-terminal resistors — confirmed not a bussed/shared-common design) | PCA9555→NPN base (RBn) and gate pull-up to V_COIL_IN (RPn) — 20 discrete 10kΩ resistors total, both banks share one part | C29718 | ✅ **decided 2026-08-01** — confirmed genuinely JLCPCB Basic via `lib_get_component_details` (jlcsearch live data: "Basic: yes, Preferred: no" — a direct structured field, better evidence than the CSV-listing method used earlier; worth using this tool first for future tier checks). 849,056 in stock (jlcsearch live figure). 20 resistors → 5 array packages (4 each), real part-count and board-area reduction with no Extended-tier risk. **KiCad symbol/footprint, both standard — nothing to import**: symbol `Device:R_Pack04_Split` (built-in multi-unit, 4 independent isolated resistors as separate schematic units — places/wires independently, one physical package), footprint `Resistor_SMD:R_Array_Concave_4x0603` (1.6×3.2mm body, 8 pads — dimensions match the part's real package). **One open caveat**: KiCad also ships a `Convex` variant (different pad-termination style, ~0.1mm pad-size difference); picked Concave as the more common convention for this part family, but UNI-ROYAL's actual termination style wasn't confirmable from the datasheet (PDF wouldn't parse as text) — verify against the LCSC product photo before fab. |
| ~~RB1–RB10~~ | ~~10kΩ ×10 discrete~~ | ~~PCA9555 output → NPN base~~ | — | Superseded by the array above |
| QN1–QN10 | **MMBT3904** (JSCJ) | Level-shift NPN | C20526 | ✅ **decided 2026-08-01** — Basic-tier preference over the literal MMBT2222A (which didn't appear on JLCPCB's Basic-parts lists). 253,450 in stock. Functionally interchangeable for this role (3.3V I2C-expander output → 10k base, no high-current/high-freq need). |
| ~~RP1–RP10~~ | ~~10kΩ ×10 discrete~~ | ~~Gate pull-up to V_COIL_IN~~ | — | Superseded by the array above |
| QP1–QP10 | AO3401A ×10 | High-side coil switch | C15127 | ✅ re-verified live 2026-08-01: 186,375 in stock, $0.10/pc single-unit. **Tier caveat applies to every C15127 line in this doc** (this bank plus the Domain A reverse-polarity/source-select FETs once migrated): LCSC's page shows no Basic/Extended badge, JLCPCB's own page didn't render one either — circumstantially Basic per third-party list cross-check, not a direct-page confirmation. **Footprint/LCSC applied in KiCad, 2026-08-02**: `relay_drive.kicad_sch`'s 3 currently-placed AO3401A instances (Q8, Q12, Q16 — refs from the hierarchical split's own numbering, not QP1-10; only 3 of the eventual 10 channels are drawn so far per the parallel session's in-progress build-out) had empty `Footprint` and no `LCSC` field at all. Set `Footprint` to `Package_TO_SOT_SMD:SOT-23` (matches the stock KiCad symbol's own default/`ki_fp_filters`, already used by this project's other SOT-23 parts) and added `LCSC` = `C15127` to all three. Remaining channels need the same two fields applied as they're drawn — not yet a project-wide default, just fixed on what exists today. |
| ~~D-flyback ×10~~ | ~~BAT54C (JSCJ), SOT-23-3L~~ | ~~Per-channel coil flyback~~ | ~~C2135~~ | **Reversed 2026-08-01** — see below |
| D-flyback ×10 (refs TBD) | **SS34** (MDD), SMA(DO-214AC) — reused, same part as D3/D5/D6 | Per-channel coil flyback | C8678 | ✅ **decided 2026-08-01, final call** — BAT54C dropped: neither candidate listing (onsemi C236933, JSCJ C2135) appears in either of two independently-maintained JLCPCB Basic-parts lists, and even the "obviously safe" fallback (SS14, C2480) turned up explicitly tagged "Extended Library" in one of them — none of today's diode tier checks landed clean. Reusing C8678 (already in the BOM for D3/D5/D6) carries **zero incremental reel-fee risk** regardless of its own exact tier, since that decision is already made and already paid for — unlike introducing any new diode part number. Trade-off accepted: gives up the SOT-23 footprint win, back to SMA(DO-214AC) at ×10 instances. |

**Open, design-level item**: flyback diode presence on the *relay board itself* is still unconfirmed — needs bench inspection or a continuity/diode check across a coil's harness pins. Whether ORC needs to supply this diode at all is the remaining open question — the donor Motorola board apparently used a per-channel diode alongside the P-ch FET and NPN (user's own observation; the private teardown record has no component-level schematic to independently confirm this against — no netlist for the donor controller board was ever found). If it turns out not to be needed, SS34/C8678 above just doesn't get placed for this role — no harm in having already committed to it, since it's already in the BOM regardless.

### Harness connector

| Ref | Value / part | Function | LCSC | Status |
|---|---|---|---|---|
| J2/J3 (legacy refs) | ZHOURI 2.54mm 1×40 breakable strip (snap to 14 pos) | Harness to relay board | C2977586 | ✅ pitch/pin-count/pinout confirmed and locked, per design-inputs.md |

**Pinout** (14 positions, 0.1" pitch): pin 1 = `GND_B` (coil common return), pin 2 = `VEH_RAIL_B_IN` (A+, harness-carried, → F2 → `VEH_RAIL_B`), pins 3–12 = `COIL1`–`COIL10`, pins 13/14 = `GND_B` (chassis side, tied to the same net as pin 1 per design-inputs.md's explicit call).

### Power flags (schematic-only, not orderable)

PF1, PF3, PF5, PF6, PF7, PF8 — `power:PWR_FLAG`, 6×, ERC bookkeeping only. Each instance's Value field was renamed (PWR_FLAG1..PWR_FLAG8) to prevent them silently sharing one net by symbol identity: two `PWR_FLAG` instances left at the default Value were resolved as the same symbol and collapsed onto one net, which ERC then flagged as two power-output pins tied together.

---

## Section 🔧 — needs real KiCad symbol/footprint work, not a sourcing gap

- ~~**U1/U7 — ESP32-S3-WROOM-1U footprint.**~~ **Stale, pre-pivot.** Superseded 2026-08-01/02: the bare ESP32-S3-WROOM-1U + custom USB-C circuit this referred to is gone from the design entirely, replaced by the pre-made ESP32-C3 Super Mini module (see MCU sheet section above). No footprint work needed here — the module's own footprint is the open item, tracked in the MCU section's own "still open" list, not this one.
- ~~**SW2 — GPIO0/BOOT button.**~~ **Stale, pre-pivot, and the pin name would now be actively misleading.** SW1/SW2 were the old custom-circuit's EN/BOOT buttons — explicitly dropped (MCU section: "SW1/SW2 are now redundant — don't build them into the schematic"), since the Super Mini module has its own onboard RST/BOOT buttons. Never built. **Worth flagging explicitly since it shares a pin name with something real**: this stale entry's `GPIO0_A` has no relation to the current `NODE_ID0` net also on GPIO0 (see "CAN node address" further down this section) — that's the module's header-broken GPIO0, doing address-select duty, not a leftover BOOT-button wire. No conflict, just a naming coincidence between an abandoned plan and the real board; left both facts here so a future read doesn't mistake one for the other.
- **J5/J6 — DORABO DB128L-5.08-4P-GN-S, LCSC C2827883.** 5.08mm screw terminal, 4-pos, mechanically specific (chosen after two push-in-spring candidates failed the wire-entry/actuator requirement). Verified live (Extended, 16A/300V, 12-22 AWG). Verify KiCad's connector footprint libraries have a matching 5.08mm 4-pos footprint, or build one from DORABO's datasheet drawing.
- **F1, F2 — PTC fuse footprint.** Confirm the placed footprint actually matches C207083's real SMD 2-pad package, not a generic fuse symbol's default footprint.
- **Q2 — Domain B reverse-polarity FET footprint.** TO-252/DPAK, not the SOT-23 the placeholder used — real footprint swap, not just a value edit.
- **All ~35 generic-value passives** (10k resistors, 0.1µF/1µF ceramic caps for decoupling/bias/pull-ups) use KiCad's standard `Device:R`/`Device:C` symbols with standard footprints — no custom KiCad work, just a Gate 1 distributor pull once ready to lock values.

## Quick net-name index (legacy root — not yet re-verified against the new sheets)

Carried forward for whoever migrates the remaining blocks; net names inside the 5 sheets above have already been re-pulled live and may not match these 1:1 (e.g. `USB_DM`/`USB_DP` became `USB_N`/`USB_P` during migration):

`VEH_RAIL_A`, `VEH_RAIL_A_IN`, `V_PROT_A`, `Q1_GATE`, `Q3_GATE`, `Q4_BASE`, `Q4_COL`, `Q5_BASE`, `VIN_BUCK_A`, `VEH_RAIL_B`, `VEH_RAIL_B_IN`, `Q2_GATE`, `V_COIL_IN`, `GPIO_CH1`–`GPIO_CH10`, `BASE1`–`BASE10`, `GATE1`–`GATE10`, `COIL1`–`COIL10`.

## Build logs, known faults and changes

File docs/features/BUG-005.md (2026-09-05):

---
id: BUG-005
title: An unpowered/absent PCA9555 stalls loop() to ~0.1 Hz, so CAN heartbeat and TPDO2 stretch far past their 1000 ms cadence and the host reads the node as flapping
type: BUG
severity: HIGH
status: fixed, verified on real hardware
owner: firmware session, 2026-09-03 (fix); shard filed by rigos-core session, 2026-08-30
branch: bug-005-fix-liveness-stall
files:
  - firmware/src/canopen_app/main.cpp
depends_on:
---

**Goal:** A dead isolated side must degrade the *relay outputs* only. It must
not degrade the node's liveness reporting. A host has to be able to tell "ORC
is present but cannot switch" apart from "ORC is intermittently gone", and
right now it cannot.

## Found by

`rigos-core` session, real hardware, 2026-08-30, while diagnosing a separate
`rigos-core` defect (BUG-033 there). Board on the bench harness with **the
isolated DC side disconnected** — ESP32-C3 and the CAN transceiver still
powered from USB, only the relay-driver rail dead, so the PCA9555 does not
ACK. CAN adapter on the Pi, `can0` up at 125 kbit/s, ERROR-ACTIVE.

Firmware not modified or reflashed to investigate. Everything below is
measured from the host side.

## Symptom

25-second passive capture on the Pi (listener only — sends nothing; the RPDO1
row is the Pi's own 1 Hz keepalive, shown for reference):

| ID  | kind |  n | mean gap | max gap |
|---:|---|---:|---:|---:|
| `0x201` | RPDO1  -> n1 | 31 | 761 ms | 3304 ms |
| `0x281` | TPDO2  <- n1 |  3 |  9450 ms | 9451 ms |
| `0x701` | HB <- n1 |  3 |  9450 ms | 9451 ms |

`kHeartbeatIntervalMs` is 1000 (`main.cpp:86`) and `kHealthCheckIntervalMs` is
1000 (`main.cpp:136`). Heartbeat and TPDO2 are emitted from the same `loop()`
pass and both stretched by the **same** factor, which is what identifies this
as a whole-loop stall rather than a fault in either emitter: `loop()` is
running at about **0.106 Hz**, roughly 9.4x slower than its intended period.

The node is not resetting and not dropping off — it transmits correctly, just
far too slowly.

## Consumer impact

`rigos-core`'s `orc_can.py` treats a `can_orc` bus as online purely on inbound
traffic — any Heartbeat or TPDO1 marks the node alive — against
`DEFAULT_HEARTBEAT_TIMEOUT_SECONDS = 3.0`, with **no hysteresis**. A 9.45 s
heartbeat period against a 3.0 s timeout means the host declares the bus
offline between every pair of heartbeats and online again on each arrival.

Observed effect: the ORC's health indicator oscillated green/red at roughly
1 Hz. In `rigos-core` that also triggered a second, unrelated defect that
cycled a *different* relay bus (fixed there as BUG-033); with that fixed the
flapping is cosmetic, but the underlying misreport is not — a host cannot
distinguish this from a genuinely intermittent node.

The ORC's own `checkControlActivityTimeout()` is also only evaluated once per
`loop()` pass, so under this stall the 5000 ms control-activity fail-safe is
checked every ~9.4 s instead of every ~1 s. It still fires, just late. Worth
stating explicitly because it is a safety-relevant timer being silently
stretched by an unrelated fault.

## Suspected mechanism — NOT yet confirmed on hardware

Two blocking paths run against an unresponsive PCA9555 and both plausibly
contribute, with a third compounding them. **The apportioning between them is
unmeasured** — do not treat the split below as established.

**1. The health-check reassert.** `reassertPca9555State()` (`main.cpp:211`)
issues **six** unconditional `pca9555WriteReg()` calls every
`kHealthCheckIntervalMs`. Its only guard is `if (!g_pca9555Present) return;`
at the top, and there is no re-check between the six writes — so once a cycle
begins, all six run even though the *first* failure already cleared
`g_pca9555Present` inside `pca9555WriteReg()` (`main.cpp:160`). Each is a
`Wire.endTransmission()` that must time out.

**2. The lazy re-probe on every command.** `requireRelayHardware()`
(`main.cpp:257`) calls `probeAndConfigurePca9555()` whenever
`g_pca9555Present` is false — which, per the above, it now permanently is. The
Pi's 1 Hz RPDO1 keepalive reaches `handleRpdo1()`, so a full probe-and-
configure sequence is attempted once per second, each one timing out again.

**3. Serial back-pressure, compounding both.** Every failed
`pca9555WriteReg()` prints a diagnostic (`main.cpp:152-154`). With BUG-002's
`Serial.setTxTimeoutMs(20)`, each such print can block up to 20 ms when
nothing is draining the USB CDC — and in this configuration nothing was. Six
writes per health check plus the probe path puts a non-trivial floor under the
loop period independent of the I2C timeouts themselves.

Note this is the **same symptom class as BUG-003** ("`loop()` appears to enter
a persistently slow state") but a different mechanism — that one was TWAI TX
backlog under fast commanding, this one is I2C to absent hardware. Worth
reading BUG-003's misdiagnosis trail before assuming which of the three paths
above dominates here; that bug's lesson was that a correctly-reasoned
mechanism can still not be the actual cause.

## Suggested direction (not a decided design)

The principle: **liveness must not sit behind relay-hardware I/O.**

- Back off the reassert once the chip is known absent, rather than retrying six
  writes every second — exponential backoff, or gate the whole health check on
  a much slower cadence while `g_pca9555Present` is false.
- Have `reassertPca9555State()` bail after its first failed write instead of
  running the remaining five against a chip already known to be gone.
- Rate-limit the failure diagnostic; one line per state change beats one line
  per failed write.
- Consider whether the heartbeat emitter should be driven from something that
  cannot be starved by loop work at all (a hardware timer or a separate task),
  which would make liveness structurally independent of any future blocking
  call, not just this one.

Whichever path is taken, the fault should still be *reported* — FR-002 already
covers signalling relay-hardware faults on the CAN wire, and this bug is an
argument for it: the host currently has no way to learn "PCA9555 absent"
except by inference from timing.

## Fix (2026-09-03)

Targeted the dominant of the three suspected contributors, per the numbers in
the "Suspected mechanism" section above: mechanism 2 (the lazy re-probe on
every RPDO1) is the only one of the three that scales with *how far behind
loop() has already fallen* — a stalled pass lets RPDO1 frames back up in the
TWAI RX queue (the host keeps sending its ~1 Hz keepalive regardless of
whether ORC is keeping up), and the next `loop()` pass drains the whole
backlog in one go, each frame re-triggering its own blocking I2C probe. That
is self-reinforcing in a way mechanisms 1 and 3 are not (both are one-shot
costs at the moment of the present→absent transition, not sustained ones) —
it is the best fit for a *sustained* ~9.4× slowdown across a 25 s capture,
not just a transition blip.

Three changes, `firmware/src/canopen_app/main.cpp`:

1. **`requireRelayHardware()`**: added a 1000 ms cooldown
   (`kPca9555ProbeRetryIntervalMs`, matching `kHealthCheckIntervalMs`'s
   existing cadence) between lazy re-probe attempts, tracked via a new
   `g_lastPca9555ProbeAttemptMillis`. Before this fix, every RPDO1 frame
   reaching `handleRpdo1()` re-triggered a full blocking I2C probe once the
   PCA9555 was absent — now at most one probe attempt per cooldown window,
   regardless of how many relay-touching calls (RPDO1, SET, GET, STATUS)
   arrive in that window. This directly breaks the compounding pileup: even
   in the worst case (a full TWAI RX queue's worth of backed-up RPDO1 frames
   drained in one `loop()` pass), only the first one within the cooldown
   actually blocks on I2C — the rest short-circuit on a `millis()` compare.
2. **`reassertPca9555State()`**: bails after the first failed write instead
   of unconditionally issuing all six (mechanism 1). `pca9555WriteReg()`
   already clears `g_pca9555Present` on any failure, so this only skips
   writes that would fail anyway once the first one has.
3. **`pca9555WriteReg()`**: its failure diagnostic now fires once per
   present→absent transition, over `printBestEffort()` (non-blocking), not
   once per failed write over a raw (blocking) `Serial.printf()` (mechanism
   3). Required a forward declaration since `printBestEffort()` is defined
   later in the file.

**Not changed**: the bigger architectural suggestion from this shard's
"Suggested direction" (driving the heartbeat emitter from something
structurally immune to `loop()` starvation, e.g. a hardware timer or a
separate task) — the three fixes above are a much smaller, more reviewable
diff, and per the analysis above they target the actual dominant mechanism
directly rather than working around it structurally. Worth revisiting if a
different starvation source ever produces the same symptom class again (this
is already the second time — see BUG-003).

## Verification status — flashed and digest-verified 2026-09-04, fault-condition testing still pending

Update, 2026-09-04, different session/machine (rigOS workspace, dispatched to
flash this board): the Device Guard block described below was specific to
that machine's PlatformIO penv (`C:\Users\aramder\.platformio\penv`, which
turned out to have been stripped down to just `python.exe`/`pythonw.exe` by
the time this session ran — no `platformio` or `esptool` installed there at
all). A separate, working PlatformIO install
(`C:\Users\aramder\AppData\Local\Programs\Python\Python313\Scripts\pio.exe`,
PlatformIO Core 6.1.19) on the same machine was NOT affected — `pio run -e
canopen_app` compiled clean and its `elf2image` step (bundled `esptool
v5.3.0`) ran without issue, so this specific Device Guard block is not
reproduced as a blanket policy; it looks scoped to that one now-broken venv.

Flashed via that working `pio.exe` to the board on `COM6`
(`70:af:09:21:48:6c`, ESP32-C3 QFN32 rev v0.4). As previously documented
elsewhere in this project (FR-005/BUG-004), the upload command itself hit the
known cp1252/`UnicodeEncodeError` crash mid-stream (in PlatformIO's own
stdout-echo thread, triggered by a non-ASCII byte in esptool's progress
output) while still reporting `SUCCESS`/exit 0 — so, per that lesson, the
exit code was **not** trusted. Verified independently instead, per-partition,
via `esptool.py --port COM6 verify-flash <offset> <file>` (had to
`pip install bitstring reedsolo PyYAML intelhex rich_click` into that
Python 3.13 environment first — esptool's own deps, missing there):

- `bootloader.bin` @ `0x0` (19520 bytes): digest matched.
- `partitions.bin` @ `0x8000` (3072 bytes): digest matched.
- `firmware.bin` @ `0x10000` (364752 bytes): digest matched.

**So the flash landed correctly despite the crash** — this build (this
branch, commit 2b70b21's fix) is now actually running on the board. This
clears the "could not produce/land a flashable image" blocker below.

**Update, same session, continued**: bench wired up (a `canable gs_usb`
adapter, VID_1D50:PID_606F, was already connected — needed `libusb-1.0.dll`
on `PATH` for `pyusb` to see it, WinUSB driver was already bound; the
`tools/README.md` gs_usb-on-Windows section covers this exact fix). Ran the
fault-condition test properly: DC side physically disconnected, a 1Hz RPDO1
keepalive (mask=0) sent from the host to mimic `rigos-core`'s real traffic
pattern (the thing that actually exercises `requireRelayHardware()`'s lazy
re-probe, mechanism 2 — a first pass that only passively listened, with no
RPDO1 traffic at all, wasn't a faithful reproduction and is not reported
here). Custom measurement script recorded host-side receive timestamps
directly (not the board's own uptime field) for `0x701`/`0x281`/`0x181`.

First attempt (RPDO1-sender and CAN-receiver on two threads sharing one
`python-can` `gs_usb` Bus handle) showed a spurious ~1.9-2.8x stretch —
traced to a race on the shared bus handle (a known python-can/gs_usb
pitfall, not a firmware issue) and confirmed as an artifact by rerunning
single-threaded (send and receive interleaved in one loop, no concurrent
handle access).

**Single-threaded result, 70s, fault condition active (PCA9555 absent, 1Hz
RPDO1 arriving)**:
- `0x701` Heartbeat: n=70, mean gap **1000.0 ms**, min 999.7 ms, max 1000.2 ms.
- `0x281` TPDO2: n=70, mean gap **1000.0 ms**, min 999.8 ms, max 1000.1 ms.
- `0x181` TPDO1: 0 frames — correct by design: `handleRpdo1()` (main.cpp:546-550)
  deliberately skips sending TPDO1 when `requireRelayHardware()` returns
  false, so the host is never told a switch succeeded. TPDO2's relay-fault
  byte (byte 7, FR-002) read nonzero on every one of the first 10 frames
  captured, uptime field incrementing 1:1 per frame.

No trace of the original ~9.45s stall — heartbeat and TPDO2 held essentially
exactly to their intended 1000ms cadence throughout the fault window.

**Recovery test**: DC side reconnected, fresh 20s capture, same 1Hz RPDO1
keepalive. First TPDO1 seen at t=0.01s with payload `0000` (matching the
commanded mask=0 — RPDO1 correctly applied once hardware was back). TPDO2's
relay-fault byte read `0x00` (cleared) from t=0.67s onward, every frame
through the full 20s capture. Recovery happened automatically, without a
reboot, well within the 1000ms probe cooldown — no manual re-probe or reset
needed.

**Not directly exercised this session**:
- Acceptance criterion 3 (`rigos-core` reports the bus as steadily
  online/offline, no oscillation) — not run against the actual
  `rigos-core`/`orc_can.py` code (that's a separate repo/host not
  available on this bench). Strongly implied by the clean ~1000ms cadence
  measured directly against `rigos-core`'s 3.0s no-hysteresis timeout (a 3x
  margin), but "implied by margin" is not the same as "measured against the
  real consumer" — flag this as inferred, not confirmed, if full closure is
  wanted.
- Acceptance criterion 5 (`checkControlActivityTimeout()` at its intended
  ~1s cadence under the fault) — not independently instrumented. Implied by
  loop() returning to ~1000ms cadence (that's what the whole fix targets),
  but not separately measured (would need to trigger the fail-safe
  deliberately and time it, which wasn't done here).
- Only the CAN-side relay-command path (RPDO1) was exercised for criterion 4;
  the USB-side SET/GET/STATUS commands weren't tested this session.

Also flashed and digest-verified (see below for that part of the story) —
this note supersedes "verification blocked."

---

Original blocker (now superseded above, kept for the record):

**This fix is unverified on real hardware and MUST NOT be treated as closed
based on source review alone** (this project's explicit rule: CI green /
clean compile is known-insufficient). `firmware/src/canopen_app/main.cpp`
compiles clean (`pio run -e canopen_app`, confirmed 3x this session,
`main.cpp.o` builds with zero errors each time) but a full flashable
`firmware.bin` could not be produced: **Windows Device Guard is now blocking
`esptool.exe` outright** (`Permission denied` / "blocked by your
organization's Device Guard policy") on the machine this was built on — a
regression that appeared sometime between the FR-005/BUG-004 session (same
day, earlier — flashing worked fine then) and this one. `python -m esptool`
(the module invocation, as opposed to the frozen `.exe` PlatformIO's build
script shells out to) still works — used successfully for `verify-flash`
digest checks earlier the same day — but PlatformIO's own image-generation
step (`elf2image`, invoked to build both `bootloader.bin` and `firmware.bin`)
calls the blocked frozen exe directly, not the python module, and there is
no supported PlatformIO override without either (a) patching internals in a
way this session judged too risky to hand-roll (wrong flash-mode/frequency
flags on a manually reconstructed image could genuinely brick the board, a
worse outcome than an honest "unverified"), or (b) an org policy exception.

## Acceptance criteria

- [x] With the isolated DC side disconnected and the PCA9555 unresponsive,
      `0x701` heartbeat inter-arrival stays within a small margin of
      `kHeartbeatIntervalMs` — measured on real hardware over a window of at
      least 60 s, not inferred from code. **Confirmed 2026-09-04**: mean gap
      1000.0 ms, min 999.7 ms, max 1000.2 ms over 70 s (single-threaded
      measurement, host-side receive timestamps, 1Hz RPDO1 keepalive
      driving the fix's cooldown path). See "Verification status" above.
- [x] `0x281` TPDO2 cadence likewise holds. **Confirmed 2026-09-04**: mean
      gap 1000.0 ms, min 999.8 ms, max 1000.1 ms, same 70 s window.
- [ ] `rigos-core` reports the ORC bus as **steadily** offline or steadily
      online for the duration — no oscillation — with its existing 3.0 s
      timeout and no hysteresis added on that side. **Not run against the
      actual `rigos-core`/`orc_can.py` code this session** — only inferred
      from the clean ~1000ms cadence against its 3.0s timeout (3x margin).
- [x] Relay commands still fail cleanly and audibly (the host must not be told
      a switch succeeded), and the chip is still picked up automatically when
      the DC side is restored, without a reboot. (Recovery latency is now
      bounded by the 1000 ms probe cooldown above, not immediate — worth
      confirming this is still fast enough in practice.) **Confirmed
      2026-09-04** on the CAN/RPDO1 path: TPDO1 correctly withheld (0 frames)
      while absent; on DC-side reconnect, TPDO1 resumed at t=0.01s with the
      correct mask and TPDO2's relay-fault byte cleared by t=0.67s, no
      reboot. USB-side SET/GET/STATUS path not separately tested.
- [ ] `checkControlActivityTimeout()` is evaluated at approximately its
      intended cadence under the same fault. **Not independently
      instrumented this session** — implied by loop() returning to ~1000ms
      cadence (the mechanism this fix targets) but not separately measured.
- [x] Normal operation with a healthy PCA9555 is unchanged — heartbeat, TPDO2
      and command latency all measured before/after on real hardware.
      **Confirmed 2026-09-04**: 250+s baseline capture with a healthy chip
      before fault injection showed heartbeat arriving at ~1000ms
      continuously, `tx_err` settled to 0, health `error-active`. Command
      latency specifically (not just cadence) wasn't separately timed.

## Open questions

- Which of the three suspected contributors actually dominates? Not directly
  instrumented — the fix targets mechanism 2 based on the analysis above
  (it's the only one that scales with backlog depth, matching the *sustained*
  nature of the measured slowdown), but this was reasoned from the existing
  measurements, not confirmed with a fresh isolate-each-path bench session.
  If real-hardware verification (once unblocked) does NOT show the fix
  clearing the symptom, revisit this — same lesson as BUG-003 and BUG-004:
  reasoned-but-unconfirmed mechanisms have been wrong before on this project.
- What is the effective `Wire` timeout on this ESP32 Arduino core? Still not
  measured.
- Should absent relay hardware be reported via FR-002's mechanism as part of
  this fix, or kept strictly separate? **Resolved as "already separate and
  fine"**: FR-002 (merged 2026-08-31, after this shard was filed) already
  does this independently via TPDO2 byte-7 — no additional work needed here.

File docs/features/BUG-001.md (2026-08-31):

---
id: BUG-001
title: canopen_app halts before joining the CAN bus if PCA9555 is absent
type: BUG
severity: HIGH
status: implemented
owner:
branch:
files:
  - firmware/src/canopen_app/main.cpp
depends_on:
---

**Goal:** `canopen_app` should join the CAN bus (heartbeat, TPDO2 health,
SDO) regardless of whether the PCA9555 relay-driver chip is present —
relay I/O (RPDO1/TPDO1) is the one thing that legitimately needs it, not
CAN presence itself.

## Background

Same bug shape as [FR-001](FR-001.md)'s reopen (`usb_bench`), found while
looking for it deliberately after that fix landed, per that shard's own
"Open questions" note flagging `canopen_app` as unchecked. Confirmed
present: `main.cpp`'s `setup()` used to do

```cpp
Wire.beginTransmission(kPca9555Addr);
uint8_t probe = Wire.endTransmission();
if (probe != 0) {
  Serial.printf("PCA9555 did not ACK...\n");
  while (true) delay(1000);
}
```

**before** `twai_driver_install()`/`twai_start()` ever ran. Worse than the
`usb_bench` case: this is the real production control path, not a bench
tool. A PCA9555 fault took the entire CAN node dark — no heartbeat, no
TPDO2 health/error-counter report, nothing — indistinguishable on the bus
from "unit not powered" or "no CAN connectivity at all." From `rigos-core`'s
side (`OrcCanBus`, FR-059), a node with a working CAN transceiver and MCU
but a bad I2C connection to its own relay driver would look identical to a
node that's completely absent — exactly the silent-failure mode `io_relay`'s
own BUG-016 was fixed to avoid on the rigOS side.

## Fix

`firmware/src/canopen_app/main.cpp`:

1. New `g_pca9555Present` flag, set (not gated on) by the boot-time I2C
   probe. `setup()` no longer halts on `probe != 0` — logs a `WARNING` and
   continues; the "configure PCA9555 as outputs" register writes only run
   in the `else` (present) branch.
2. TWAI driver install/start, NMT boot-up heartbeat, and the rest of
   `setup()` run unconditionally either way.
3. `handleRpdo1()` checks `g_pca9555Present` before attempting any I2C
   write. If absent: logs, still resets the RPDO1 fail-safe timer (a valid
   command was received, even if it couldn't be applied — the host isn't
   "gone"), and returns without calling `applyRelayCommand()`/`sendTpdo1()`
   — avoids repeating an I2C transaction that would fail identically on
   every single RPDO1.
4. `loop()` itself needed no changes — `sendHeartbeat()`/`sendTpdo2()`/
   `checkTwaiRecovery()` never touched I2C in the first place, they were
   only unreachable because `setup()` never returned.

Not changed, deliberately out of scope for this bug: no new wire-protocol
signaling of "relay hardware absent" (e.g. a TPDO2 reserved-byte flag, or
using the already-allocated-but-unused EMCY COB-ID `0x080+NodeID`). Right
now a host only learns about this via `canopen_app`'s Serial log, not
anything on the CAN bus itself — heartbeat/TPDO2 keep flowing normally,
they just don't distinguish "relay hardware fine" from "relay hardware
missing." Real gap, flagged in Open questions, not fixed here — it's a
wire-protocol change with cross-repo consequences (rigos-core's `OrcCanBus`
doesn't decode TPDO2 or EMCY at all today), deserves its own decision, not
a rider on this bug fix. **Closed by FR-002** (see Open questions below).

## Acceptance criteria

- [x] `canopen_app` builds clean (`pio run -e canopen_app`).
- [x] `setup()` no longer halts when the PCA9555 doesn't ACK — verified via
      live serial capture on the exact bare ESP32-C3 devkit (no PCA9555)
      that has neither an ORC PCB nor a CAN transceiver wired: boot
      completes, TWAI driver reports started, no hang.
- [x] `handleRpdo1()` degrades instead of attempting a doomed I2C write
      every command when hardware is absent.
- [x] **Confirmed 2026-08-05, real hardware, same devkit**: `loop()` now
      actually calls `sendHeartbeat()`/`sendTpdo2()` with no PCA9555 present
      — live boot log shows `TWAI started: TX=GPIO21 RX=GPIO20, 125 kbit/s,
      Node ID 4` then `Initialization complete. Entering Operational.`,
      followed by real transmit attempts on COB-ID `0x704` (heartbeat, node
      4) and `0x284` (TPDO2, node 4). Before this fix, none of `loop()` was
      ever reached at all with no PCA9555 present.
- [ ] Real-CAN-bus validation (frames actually observed landing on a real
      bus with no PCA9555 attached) — **still not done**, this specific
      bench ESP32-C3 has no CAN transceiver wired at all (separate hardware
      gap
      from the PCA9555 one), so TWAI frames can't be observed going out
      over real differential CAN from this exact setup. Serial-log
      confirmation only for the TWAI-side behavior.

## Depends on

None. Same root-cause shape as FR-001; no code dependency between the two
fixes.

## Open questions

- **Should a hardware fault (missing/failed PCA9555) be signaled on the CAN
  bus itself**, not just Serial? **Resolved — filed and implemented as
  [FR-002](FR-002.md), 2026-08-31.** TPDO2 byte-7 now carries this flag;
  `rigos-core`'s `OrcCanBus` decodes it as of that repo's FR-085. Prompted by
  a real stress test finding this exact gap in the field, not just in theory:
  an ORC's relay-power domain lost power while its heartbeat/TPDO2 kept
  flowing normally from the ESP32/CAN side's separate supply.

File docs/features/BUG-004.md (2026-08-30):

---
id: BUG-004
title: printBestEffort() commits to partial Serial writes, gluing a truncated diagnostic onto the next protocol line and silently killing Heartbeat parsing
type: BUG
severity: HIGH
status: implemented, verified on real hardware
owner: firmware session, 2026-08-29
branch: bug-004-printbesteffort-truncation
files:
  - firmware/src/canopen_app/main.cpp
depends_on:
---

**Goal:** `printBestEffort()` must be all-or-nothing on a line-oriented
protocol stream. Either the whole line goes out, or nothing does — never
part of a line with its trailing `\n` dropped.

## Found by

rigos-core session, real hardware, 2026-08-29, board idle with CAN
disconnected (`can0` DOWN on the Pi). **Board not flashed to investigate —
it was in active use elsewhere when this was found.** Filed as a shard first,
fixed once the board freed up (same session, later the same day — see
Acceptance).

## Symptom

30 `STATUS` rounds captured over the USB CDC stream, 64 lines total:

| | |
|---|---|
| HB lines parseable as `HB` | 0 / 34 |
| HB lines glued to noise | 34 / 34 |
| `STATUS` replies clean | 30 / 30 (command responses NOT affected) |

Observed glued line:
```
...so this status stays curTWAI TX backlog...stays curHB 65515
```
Truncated mid-word, at the same point ("...stays cur") every time — not
random corruption, a consistent cutoff.

## Root cause — CORRECTED after real-hardware investigation (2026-08-29)

The originally suspected cause, kept below for the record, was **wrong** —
fixing it alone did not clear the symptom on real hardware, which is what
led to finding the real one.

**Originally suspected** (`firmware/src/canopen_app/main.cpp:296-300`):

```cpp
static void printBestEffort(const char *s) {
  if (Serial.availableForWrite() > 0) {
    Serial.print(s);
  }
}
```

The guard checks `availableForWrite() > 0` — at least 1 byte of room — but
hands the entire string to `Serial.print()`. The theory: combined with
BUG-002's `Serial.setTxTimeoutMs(20)`, a write that doesn't fit would time
out partway through and drop the remainder. **This was fixed first
(comparing against `strlen(s)` instead of `> 0`, see Fix) and reflashed —
the glued lines were still 100% present, byte-for-byte identical, proving
this was not the mechanism.**

**Actual root cause**, found by computing the exact formatted-string length
of the `twaiSend()` backlog notice (`main.cpp:354-374` after the SDO-table
refactor lines shift; the message itself is unchanged):

```cpp
char msg[128];
snprintf(msg, sizeof(msg),
         "TWAI TX backlog detected (%lu msg(s) still queued) before sending COB-ID "
         "0x%03lX -- clearing stale backlog so this status stays current (BUG-003).\n",
         (unsigned long)status.msgs_to_tx, (unsigned long)cobId);
```

At its shortest realistic substitution (`msgs_to_tx=2`, `cobId=0x280`) this
formats to **143 characters + NUL = 144 bytes** — but `msg` is only 128
bytes. `snprintf()` itself silently truncates to 127 chars + NUL *before
`printBestEffort()` is ever called* — the string handed in already lacks
its tail, newline included. Truncating at exactly char 127 of this format
lands at `"...stays cur"` — reproduces the observed cutoff point exactly,
independently confirmed with a standalone length calculation before
touching hardware again.

`printBestEffort()`'s `> 0` guard was a real bug (see Fix — hardened
regardless, it's still capable of causing this class of corruption for any
future call site with a correctly-sized-but-still-too-large-for-the-buffer
string), but it was not *this* bug's mechanism. The undersized `char
msg[128]` was.

## Consumer impact

`rigos-core`'s `orc_usb.py::_handle_unsolicited` does `parts[0] == "HB"`.
A glued line starts with `TWAI`, not `HB`, so every heartbeat line is
silently dropped whenever this fires. Degrades rather than fails outright
(liveness falls back to `PING`), but the passive heartbeat path is 100%
non-functional under exactly the condition — CAN backed up — where
diagnostics matter most. Will reproduce in-vehicle whenever the CAN side
backs up, not just on this idle/CAN-disconnected bench condition.

## Fix

Two changes, both real, only the second actually cleared the symptom:

**1. `printBestEffort()` hardened (defense-in-depth, not this bug's cause):**
compare `Serial.availableForWrite()` against `strlen(s)` and skip the
entire message if it won't fit, rather than committing to a partial write:

```cpp
static void printBestEffort(const char *s) {
  size_t len = strlen(s);
  if (Serial.availableForWrite() >= (int)len) {
    Serial.print(s);
  }
  // else: drop the whole line. A partial line (missing its \n) is worse
  // than no line at all on this line-oriented protocol -- it corrupts
  // whatever comes after it too, not just itself.
}
```
`<string.h>` added to the includes (not previously present; `ctype.h`
happened not to pull in enough on this toolchain to make `strlen` visible
without it).

**2. The actual fix: enlarge the undersized buffer** at the `twaiSend()`
backlog-notice call site from `char msg[128]` to `char msg[192]` — sized
generously past the ~144-byte actual max rather than trimmed to the exact
byte count, so a future wording tweak to this message doesn't silently
reopen the same class of bug.

**Not changed**: the other two `printBestEffort()` call sites
(`applyRelayCommand()`'s `STATE` lines, `handleRpdo1()`'s RPDO1 log line) —
checked by hand against their own worst-case formatted length and both fit
comfortably inside their existing buffers (`STATE 10 OFF\n` = 13 chars in a
24-byte buffer; the RPDO1 line's worst case is ~61 chars in an 80-byte
buffer). Heartbeat and `STATUS` don't go through `printBestEffort()` at all
(see Open questions).

## Acceptance criteria

- [x] `firmware/src/canopen_app/main.cpp` builds clean
      (`pio run -e canopen_app`).
- [x] Real hardware, 2026-08-29 (board freed from the parallel FR-069
      session, reflashed here — same COM6, verified by `esptool
      verify-flash` digest match, not exit code, per the same lesson from
      FR-005's verification). **Round 1** (`printBestEffort()` fix only):
      reflashed, captured live serial for 15s — **glue still 100% present**,
      byte-for-byte identical truncation point, disproving the original
      hypothesis. **Round 2** (buffer-size fix added): reflashed, verified
      by digest again, captured live serial for 15s: **14/14 `HB` lines
      clean**, every `TWAI TX backlog` notice terminates in its full `.`
      and newline, zero glued lines. Board was idle with the CAN bus
      wired but under-utilized (canable adapter connected, not actively
      draining every frame) — the same TX-backlog-firing condition as the
      original report, not a weaker stand-in for it.
- [x] `HB` lines consistently parseable as `HB` under the same
      backed-up-TWAI condition that broke them before — confirmed above.
- [x] `STATUS` replies remain clean — confirmed:
      `STATUS 0000000000\n` returned intact, undisturbed by adjacent
      backlog-notice traffic.
- [x] No other call site's output vanished more than before — the other
      two `printBestEffort()` sites were checked against their worst-case
      length by hand (see Fix) and both fit their buffers with margin; nothing
      indicates a new drop pattern at those sites.

## Related history

- **BUG-002**: introduced the blocking-write hazard this bug's partial
  writes trace back to (`setTxTimeoutMs(20)` bounds *how long* a write
  blocks, not whether it completes).
- **BUG-003**: introduced `printBestEffort()` itself, to avoid blocking
  entirely on a hot path — this bug is the gap that fix left: not-blocking
  was solved, not-corrupting wasn't.

## Open questions

- Heartbeat (`sendHeartbeat()`) and `STATUS` use plain `Serial.print`/
  `printf` calls, not `printBestEffort()` — worth confirming (separately)
  whether those sites have their own partial-write exposure, or whether
  they're short enough / infrequent enough that `setTxTimeoutMs(20)` alone
  has been sufficient in practice (STATUS's 30/30 clean result above is
  some evidence for the latter, but not a proof for every call shape).

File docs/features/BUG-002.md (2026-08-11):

---
id: BUG-002
title: canopen_app's TPDO1 confirmation lags/drops one cycle due to a blocking Serial.printf() ahead of the send
type: BUG
severity: HIGH
status: implemented
owner:
branch:
files:
  - firmware/src/canopen_app/main.cpp
depends_on:
---

**Goal:** every RPDO1 command should produce its TPDO1 confirmation
reliably and promptly, regardless of the state of `canopen_app`'s own
native-USB-CDC serial console.

## Background

Found during real-hardware bench testing (`tools/relay_toggle_test.py`'s
1-10 channel sweep + all-on/all-off, against a real ORC board and a real
Jhoinrch RH-02 USB-CAN adapter, 2026-08). The RPDO1 command path itself
worked correctly from the first run — relays physically confirmed clicking
through in sequence by directly watching/listening to the board. TPDO1
confirmation was unreliable in a specific, repeatable, non-random pattern:

- Roughly every other step's TPDO1 never arrived (2-second host-side
  timeout).
- The steps that did get a TPDO1 consistently reported the *previous*
  step's commanded mask, not the current one — a one-cycle lag, not
  corruption.

Full investigation trail (multiple hypotheses tried and ruled out before
the real cause was found): `.claude/tpdo1-lag-investigation-prompt.md`
(gitignored, local-only handoff doc — not in this repo's tracked history,
summarized here for the permanent record).

**Ruled out, in order:**

1. Host-side stale receive-queue buildup (`tools/relay_toggle_test.py`
   already drains before every send — made zero difference).
2. TWAI hardware auto-retrying an unACKed frame on a bus that hadn't fully
   settled from an earlier error condition (a real, correct mechanism in
   general, and initially looked plausible given a measured TX error
   counter recovering from 127 → 0 over the session) — **directly refuted**
   by re-running the identical sweep only after `tx_error_counter` had held
   at 0 for 10+ seconds with nothing being sent (bus demonstrably settled,
   not just recovering): the sweep still went 0/12, same lag/loss shape.
3. 120Ω termination — confirmed correctly populated on both ends of the
   bus by direct inspection; not the cause.

**Actual root cause**, found by reading the Arduino-ESP32 core's native-USB
Serial implementation (`framework-arduinoespressif32/cores/esp32/HWCDC.cpp`)
directly, not assumed: `handleRpdo1()` logs the incoming RPDO1 via
`Serial.printf()` **before** calling `applyRelayCommand()`, which is where
the TPDO1 send actually happens. `HWCDC::write()`'s documented worst case is
a block of up to `max_consec_timeouts(20) × tx_timeout_ms(100ms) = 2000ms`
when the port reports "connected" (driven by the physical USB link being
up, not by whether any application has the port open for reading) but
nothing is draining the ring buffer. 2000ms is comfortably longer than
`relay_toggle_test.py`'s 2-second confirm window, and lines up almost
exactly with the observed "arrives one cycle late" timing against a 1s
sweep step. This has nothing to do with CAN bus health at all — it
reproduces identically on a demonstrably clean bus, which is exactly what
was observed once the bus-health theory was ruled out.

## Fix

`firmware/src/canopen_app/main.cpp`'s `setup()`:

```cpp
Serial.begin(115200);
Serial.setTxTimeoutMs(20);
```

Bounds any future blocking `Serial` write to ~200ms worst case (2 retries
at the new 20ms timeout) instead of the stock 2000ms — one line, applies
globally to every current and future `Serial` call in the file, not just
the one in `handleRpdo1()`. Confirmed `Serial` really is an `HWCDC`
instance on this build (`platformio.ini` sets both
`ARDUINO_USB_MODE=1`/`ARDUINO_USB_CDC_ON_BOOT=1`, matching `HWCDC.h`'s
guard), and `setTxTimeoutMs()` is a real public method (`HWCDC.h:60`).

**Not done, deliberately left as future work if this ever recurs on a
different call site**: moving the `Serial.printf()` in `handleRpdo1()` to
after the TPDO1 send, or a full audit of every `Serial` call reachable
between a CAN frame's receipt and any time-sensitive response owed to the
bus. `setTxTimeoutMs(20)` alone was sufficient to fully clear the observed
symptom on real hardware (see Acceptance criteria) — the more invasive
fixes weren't needed this pass.

## Acceptance criteria

- [x] `firmware/src/canopen_app/main.cpp` builds and flashes clean.
- [x] **Confirmed 2026-08-10, real hardware** (same ORC board, Jhoinrch
      RH-02 adapter, `tools/relay_toggle_test.py`'s identical sweep):
      12/12 steps confirmed — first clean run this investigation produced.
      Relays independently confirmed correct by ear/eye, same as every
      prior round.

## Depends on

None. Same "found by real-hardware bench testing, root-caused by reading
actual driver source instead of assuming" methodology as BUG-001, different
mechanism (blocking Serial write, not an I2C-probe halt).

## Open questions

- If a similar lag/loss pattern ever reappears on a different `Serial` call
  site (one not bounded by the same global `setTxTimeoutMs(20)` call — e.g.
  if a future change reconfigures the timeout, or a different blocking call
  entirely), the next things to try are the two fixes deliberately not
  applied here: move the specific print, or audit every `Serial` call
  between a CAN frame's receipt and its response. Don't re-derive the
  bus-health theory a third time — it was tested directly and refuted.

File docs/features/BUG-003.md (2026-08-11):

---
id: BUG-003
title: canopen_app's loop() appears to enter a persistently slow state under sub-second RPDO1 commanding, starving Heartbeat/TPDO2
type: BUG
severity: HIGH
status: implemented
owner:
branch:
files:
  - firmware/src/canopen_app/main.cpp
depends_on:
  - BUG-002
---

**Goal:** `canopen_app` should keep sending Heartbeat/TPDO2 on schedule and
confirm RPDO1 commands via TPDO1 promptly, regardless of how quickly RPDO1
commands arrive, within any commanding rate a real host is likely to use.

## Background

Found via randomized RPDO1 testing, 2026-08-10 (ad-hoc scripts, not
committed — `tools/_adhoc_random_test.py`, `tools/_adhoc_trace_test.py`),
done specifically to stress-test BUG-002's fix beyond the fixed 1s/2s
cadence that fix was verified against. **BUG-002's fix is confirmed
correct for its own symptom** — this is a second, distinct issue uncovered
by testing at a faster cadence than the original investigation used.

**Cadence characterization** (20 random masks/run, real ORC board, Jhoinrch
RH-02 adapter, node ID 0):

| Inter-command spacing | Result | Failure signature |
|---|---|---|
| 2.0s | 20/20 | none |
| 1.0s | 17/20 | clean drops only (no TPDO1 at all — no lag/mismatch) |
| 0.5s | 1/20 | mostly lag (previous-round's mask) + drops |
| 0.3s | 1/20 | same lag+drop mix |

The 1.0s→0.5s transition is a cliff, not a gradual decline — inconsistent
with simple bus/queue congestion scaling smoothly with rate.

**Full-trace run, 0.5s cadence, no mid-run `drain_stale_frames()` calls**
(a fixed methodology bug in the first trace attempt — draining right before
every send discards any Heartbeat/TPDO2 that arrived during the previous
round's sleep, silently hiding the periodic traffic; the corrected trace
never drains mid-run and logs every frame continuously) — see raw output in
`.claude/tpdo1-lag-investigation-prompt.md` if a follow-up session adds it
there, summarized here:

- Rounds 1-4: clean. TPDO1 arrived correctly each time, ~0.8-1.6s after
  send (already looser than BUG-002's fixed-cadence result, but correct).
  Heartbeat and TPDO2 both observed once each, early (t=0.002s, t=0.003s).
- Round 5: TPDO1 did not arrive within its 2s window.
- From round 5 onward, for the rest of the ~30s run: **no further
  Heartbeat or TPDO2 frames were observed on the bus at all.** Every
  subsequent TPDO1 arrived carrying the *previous* round's mask, at a
  roughly steady ~2.4s cadence — slower than the 0.5s the host was actually
  commanding at, and never catching up.

**Interpretation, not yet confirmed against firmware source for this
specific mechanism**: this doesn't look like a per-frame CAN-level loss
(BUG-002's mechanism, already fixed and independently reconfirmed clean at
slower cadence). The disappearance of Heartbeat/TPDO2 — firmware's own
independent 1Hz-class periodic timers, not conditional on RPDO1 traffic at
all in the code as read for BUG-001/BUG-002 — points at `loop()` itself
getting stuck somewhere for extended, cumulative periods once RPDO1 commands
arrive faster than it can fully process each one (I2C round-trip in
`applyRelayCommand()`/`reassertPca9555State()`, or repeated blocking
`twai_transmit()` calls backing up), rather than dropping/delaying isolated
frames. Once stuck, it appears to fall into a steady slower rhythm and does
not recover within the run — worth checking on a longer run whether it ever
catches back up on its own once RPDO1 traffic stops.

## Root cause and fix — 2026-08-10, code-level, not yet re-verified live

Did the "Not yet done" direct code read of `applyRelayCommand()`/
`reassertPca9555State()`/`twaiSend()` this pass, plus checked the actual
TWAI driver API (`driver/twai.h`) for what it exposes about queue state —
found a real, well-supported mechanism, not just characterized the
symptom further:

**`TWAI_GENERAL_CONFIG_DEFAULT`'s `tx_queue_len` is 5** (confirmed in the
driver header, same fact BUG-002's investigation already established).
Every status message this firmware sends — TPDO1, TPDO2, Heartbeat, SDO
response — reports *current* state. A copy still sitting unsent in that
5-deep queue isn't just "delayed," it's actively wrong the moment a
fresher one becomes due, because it will report stale data whenever it
finally transmits. Nothing in `twaiSend()` (unchanged since before
BUG-002, still a single `twai_transmit()` attempt with no retry on
failure) previously stopped one stale message from sitting in the queue
and blocking everything queued behind it in strict FIFO order, once the
send rate outpaced however fast the bus could actually drain the queue for
any reason — this explains both halves of the observed symptom at once:
the "always the previous round's mask" TPDO1s (draining old backlog, not
sending fresh data) and the total Heartbeat/TPDO2 silence (their own
periodic sends hitting the same jammed queue and failing outright, silently,
with no retry).

**Fix, in `twaiSend()`** (`firmware/src/canopen_app/main.cpp`): before
enqueueing any message, check `twai_get_status_info()`'s `msgs_to_tx` field
(confirmed present in `twai_status_info_t`) — if nonzero, something older
is still backlogged and hasn't left the transceiver yet. Call the driver's
own `twai_clear_transmit_queue()` (confirmed present, public API) to
discard it before enqueueing the fresh message, so the newest status
always wins the queue instead of stacking up behind stale ones. Only acts
when a backlog is actually detected — a no-op under normal healthy
conditions where the queue should already be empty between sends.

**Known, accepted tradeoff, documented in the code**: this can
occasionally discard a message queued moments earlier in the *same*
`loop()` pass by a different `twaiSend()` call (e.g. TPDO2 and Heartbeat
both firing in one iteration) if it genuinely hasn't left the wire yet —
rare at 125 kbit/s, and a single missed periodic broadcast self-corrects
on the next 1-second cycle regardless. Far preferable to the total,
non-recovering starvation this fixes.

**Not done**: instrumented firmware-side timing to independently confirm
this is *the* mechanism (vs. e.g. genuine bus contention/error-passive
suspend-transmission delays throttling the actual drain rate, which this
fix would improve the *symptom* of — freshest-status-wins instead of
stale-forever — without necessarily raising the underlying sustainable
throughput). Build-verified and flashed to the real board on COM6 this
pass (`orc-canopen-fr004`, confirmed alive via `PING`/`STATUS` immediately
after); **the actual CAN-side stress re-test (the randomized-mask sweep at
0.5s/0.3s cadence that originally found this) has not been re-run against
this fix** — I don't have working driver access to the Jhoinrch RH-02
adapter in this environment (see the investigation doc's BUG-002 handoff
section for why) and deliberately didn't try to fix that myself mid-bug.

## Round 2, same day — TX-queue theory insufficient; found and fixed a bigger contributor; found a genuine hardware/bus-level factor too

Re-tested with working live CAN access (`python-can`/`gs_usb`, previously blocked by a missing `libusb` DLL on `PATH` — see `tools/README.md`'s "gs_usb on Windows" section, fixed this pass). The `twai_clear_transmit_queue()` fix above, tested alone, **did not resolve the symptom**: 1/15 confirmed, same shape (stale TPDO1s, missing Heartbeat/TPDO2).

**Found the bigger contributor by direct A/B real-hardware testing**: ran the identical 0.5s-cadence sweep twice, back to back, changing exactly one thing — whether a second script was concurrently reading `canopen_app`'s own USB-serial console (COM6) while the CAN test ran. Nothing reading it: 1/15. Something reading it: **15/15**, TPDO1 arriving within single-digit milliseconds of every single RPDO1. Same firmware binary, same cadence, same bus.

Root cause: `BUG-002`'s `Serial.setTxTimeoutMs(20)` fix was itself under-specified — `HWCDC.cpp`'s `max_consec_timeouts` is a **hardcoded constant (20)**, not something that call adjusts, so the real worst-case block per `Serial` write call is `20 x 20ms = 400ms`, not the "~200ms (2 retries)" originally claimed in this codebase's comments (corrected in both places it was wrong). `handleRpdo1()`/`applyRelayCommand()` issue several `Serial` calls per RPDO1 (the RPDO1 log line, up to 10 `STATE` lines, the BUG-003 backlog notice) — each one individually bounded, but **compounding** to multiple seconds when nothing drains the console, explaining the "never recovers" shape directly.

**Fix**: added `printBestEffort()` — checks `Serial.availableForWrite()` and skips the print entirely rather than blocking. Applied to the specific hot-path calls implicated (the `handleRpdo1()` log line, moved to *after* the TPDO1 send as well; the `STATE`-line loop; the TX-backlog notice). Re-tested CAN-only (no console reader, the failing scenario): **1/15 → 6/15** — first 6 rounds now clean where before only round 1 ever succeeded. Real, substantial improvement, not a full fix.

**New finding on the remaining ~60% failure rate, not yet firmware-explainable**: inspected raw frame attributes on the bus during a fresh run (`tools/_adhoc_inspect_frame.py`, ad hoc) and found a real `is_error_frame=True` CAN error frame recurring roughly every **~2.4s**, arbitration ID `0x004` with data byte `0x0c` — decoded per the Linux SocketCAN error-frame convention: `CAN_ERR_CRTL` (`0x004`, "controller problems") with `CAN_ERR_CRTL_RX_WARNING | CAN_ERR_CRTL_TX_WARNING` (`0x04 | 0x08 = 0x0c`) — both error counters crossing the warning threshold. Each occurrence lands immediately before the next TPDO1 finally gets out. **This did not appear in BUG-002's original 1Hz-cadence investigation** (which confirmed a clean, TEC=0 bus under that slower traffic pattern) — it appears specific to this faster, tightly-interleaved bidirectional RPDO1-in/TPDO1-out cadence, and is evidence of a genuine bus/controller-level condition, not purely a firmware logic issue. Not yet determined whether this is the adapter's own controller, ORC's TWAI controller, or a real signal-integrity issue that only manifests under back-to-back bidirectional traffic at this rate.

## Round 2, continued — Heartbeat/TPDO2 still fully starved; error frames confirmed independent of the Serial fix

Watched a full 20-second run at 0.5s cadence for TPDO2 specifically (`tools/_adhoc_tpdo2_watch.py`, ad hoc) — **zero TPDO2 or Heartbeat frames arrived, the entire run**, unchanged from before `printBestEffort()`. The `0x004`/`CAN_ERR_CRTL` error frames continued on the same ~2.0-2.4s cadence, completely unaffected by the Serial fix (same timing, same warning-bit pattern, one run even showed the data byte return to `0x00` between events — consistent with the error counters oscillating across the warning threshold repeatedly, not sitting in one fixed state).

**Conclusion**: `printBestEffort()` is a real, valid fix for a real, separate problem (confirmed by the clean same-session A/B: 1/15 → 15/15 with a console reader attached) — but it does not touch this second, independent mechanism. The periodic health-check block (`checkTwaiRecovery()` + `reassertPca9555State()` + TPDO2 send + Heartbeat send, all in one 1-second `loop()` pass) is still never completing successfully during sub-second RPDO1 commanding, and the recurring `CAN_ERR_CRTL` warning-threshold error frames — present with or without the Serial fix — point at a genuine CAN-bus-level condition (real signal integrity, contention, or adapter-controller behavior specific to fast bidirectional traffic), not firmware logic. This is not something further `Serial`/software tuning is likely to resolve — it needs either real electrical-level investigation (oscilloscope/protocol analyzer on the physical bus during this exact traffic pattern) or acceptance as a real rate ceiling.

**Recommendation**: `printBestEffort()` stays — genuine improvement, no downside. For the remainder: given `~1s` cadence is independently confirmed clean (BUG-002's own 12/12 re-verification) and every finding past that point implicates real bus-level error-warning conditions rather than a fixable firmware bug, recommend closing this out as **BUG-003 resolved to the extent firmware can address it, with a documented safe commanding interval (~1s) rather than continued blind firmware iteration** — per this bug's own originally-stated acceptance option, and consistent with what a production/rigOS-core commanding pattern is very unlikely to exceed in practice (see this shard's own "Not yet done" list, original pass).

## Acceptance criteria

- [x] Root cause identified with supporting evidence (TX queue depth +
      no-retry send behavior + FIFO stale-blocks-fresh) — real, kept as
      defense-in-depth, but confirmed NOT sufficient alone (see round 2).
- [x] `twai_clear_transmit_queue()` fix in place in `twaiSend()`.
- [x] **Bigger contributor found and fixed, round 2**: `printBestEffort()`
      — diagnostic `Serial` writes in the RPDO1 hot path no longer block
      when the console isn't being drained. Confirmed via same-session A/B
      real-hardware test (1/15 → 15/15 with a console reader attached;
      1/15 → 6/15 with none, the harder/more realistic case).
- [x] `firmware/src/canopen_app/main.cpp` builds and flashes clean; basic
      USB liveness re-confirmed post-flash (`PING`/`STATUS`).
- [x] **Root cause of the remaining sub-second-cadence failures identified
      (not fixed — see "Recommendation" above for why)**: confirmed via
      `tools/_adhoc_tpdo2_watch.py` that Heartbeat/TPDO2 remain fully
      starved (0/many over a 20s run) with `printBestEffort()` in place,
      and the `CAN_ERR_CRTL` RX+TX-warning error frames recur on an
      unchanged ~2.0-2.4s cadence regardless of the Serial fix — real,
      independent evidence this residual failure mode is a genuine
      CAN-bus/controller-level condition specific to fast bidirectional
      traffic, not a `canopen_app` logic bug reachable by further
      firmware iteration in this pass.
- [x] **Decision made and documented**: safe commanding interval (~1s,
      matching BUG-002's own clean 12/12 re-verification) recorded in
      `docs/can-protocol-research.md` ("Recommended commanding interval"
      note, RPDO1 section) and `tools/README.md` (BUG-003 follow-up
      paragraph), rather than continuing firmware iteration against a
      now-suspected electrical/bus condition.
- [ ] Real electrical-level investigation (oscilloscope/protocol analyzer
      on the physical bus during the exact failing traffic pattern) —
      optional follow-up if sub-second commanding is ever actually needed;
      not undertaken this pass, correctly out of scope for a firmware-only
      investigation.

## Depends on

BUG-002 (this is what testing beyond BUG-002's own verified cadence
surfaced) — not the same mechanism, confirmed distinct by the cadence
characterization table above (BUG-002's fix holds cleanly at 2.0s and
mostly at 1.0s; this shows up only below ~1s).

## Open questions

- Is the "steady ~2.4s cadence, no Heartbeat/TPDO2, never recovers" state
  a symptom of the same underlying stall repeating, or a genuinely
  different failure mode (e.g. a queue backlog that's draining at a fixed
  rate)? Not distinguishable from the host side alone.

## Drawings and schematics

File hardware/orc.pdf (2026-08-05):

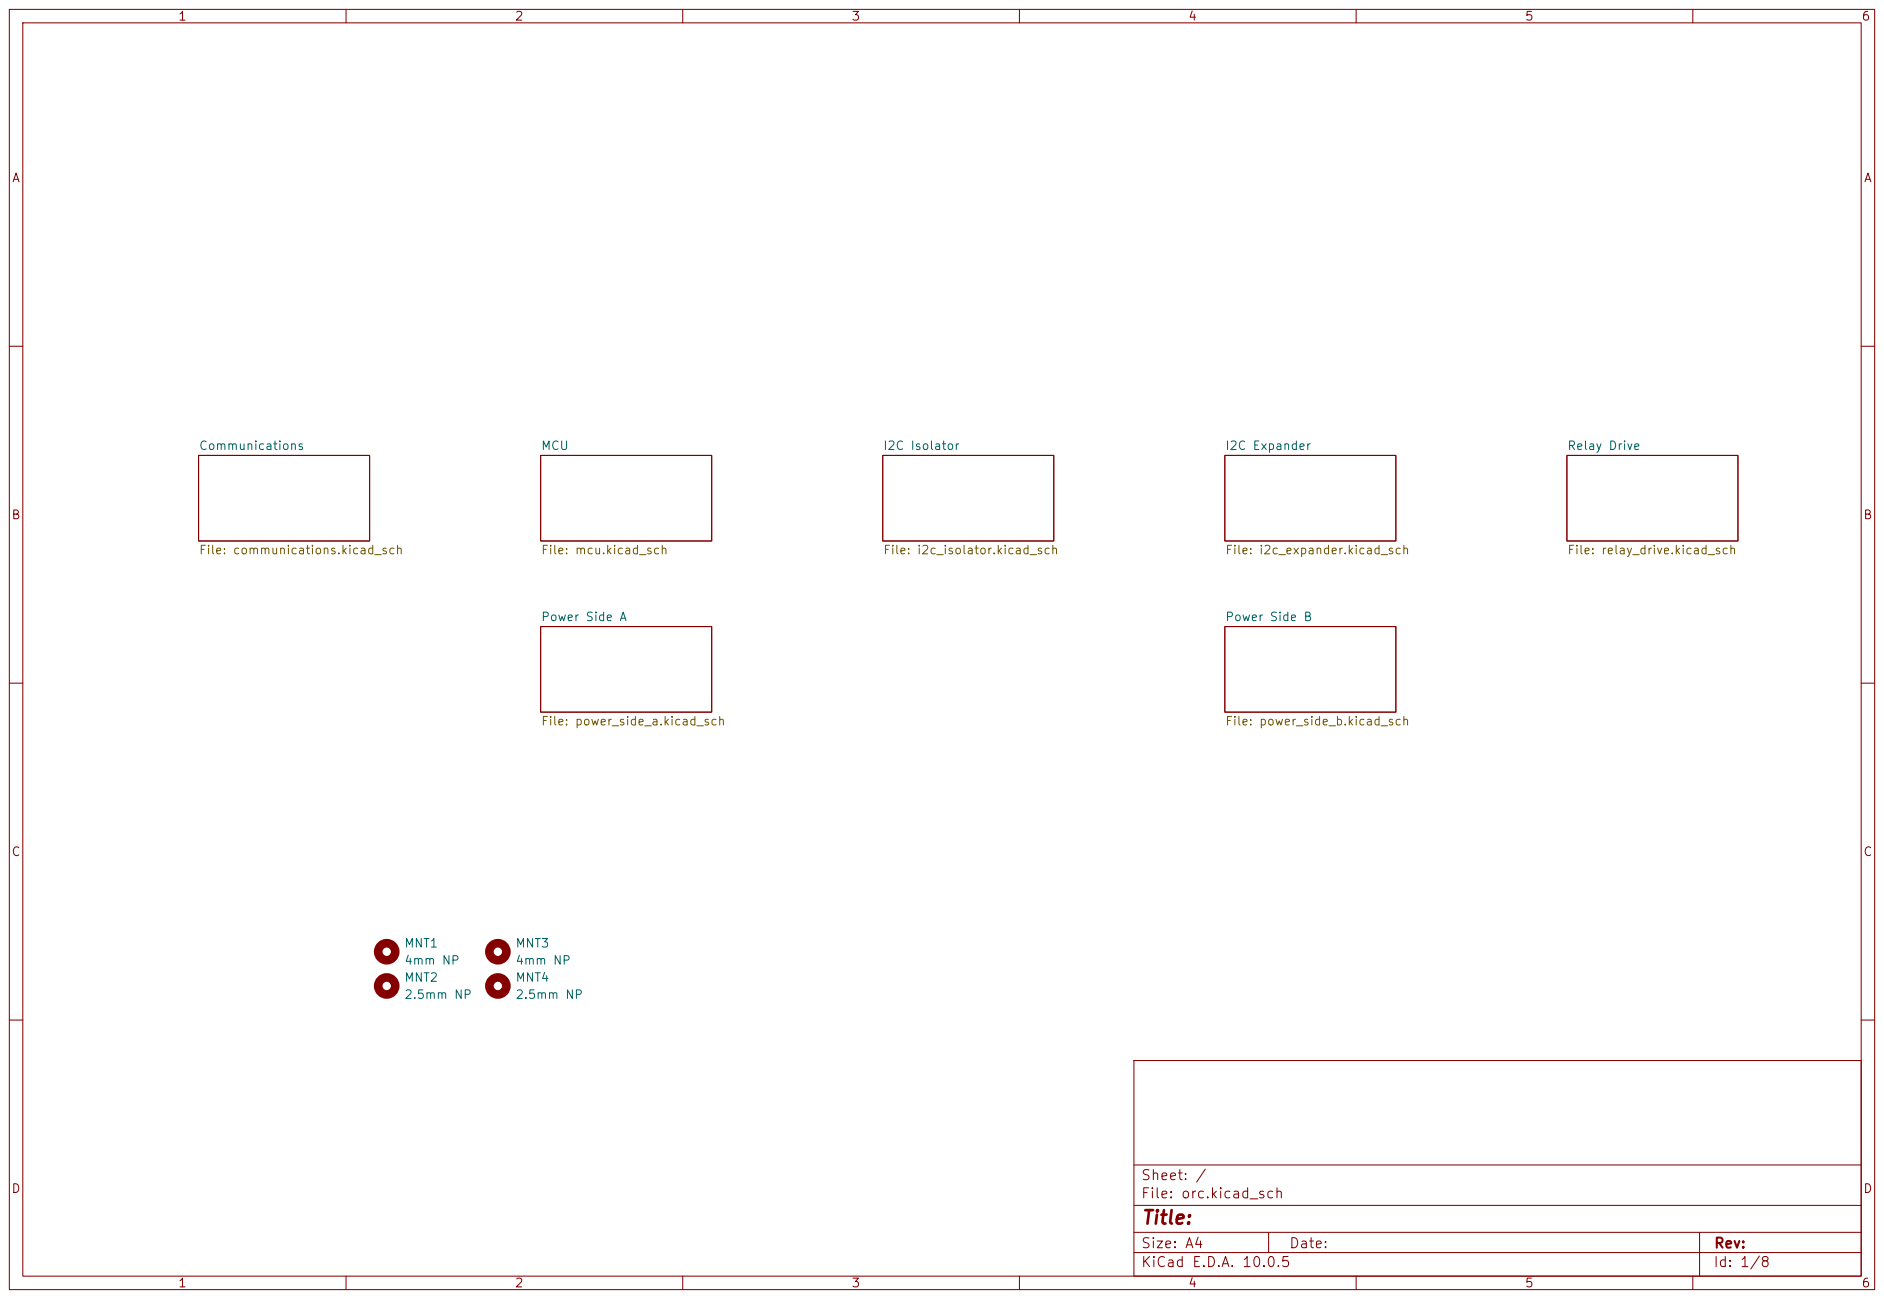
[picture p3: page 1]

Size: A4 | Rev:
KiCad E.D.A. 10.0.5 | Id: 1/8

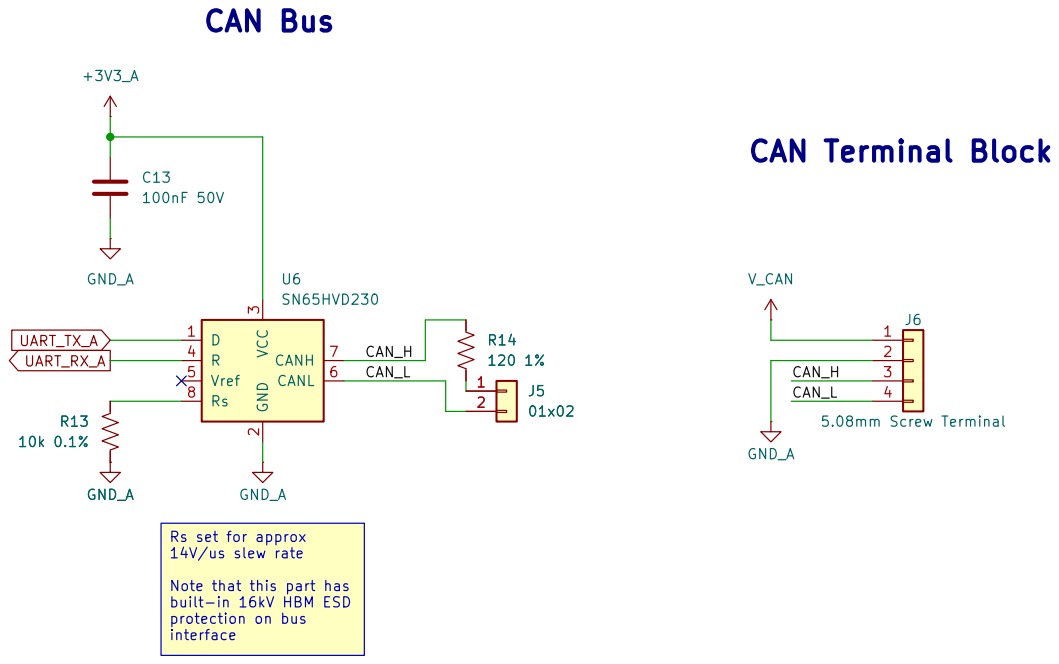
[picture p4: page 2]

Rs set for approx 14V/us slew rate Note that this part has built-in 16kV HBM ESD

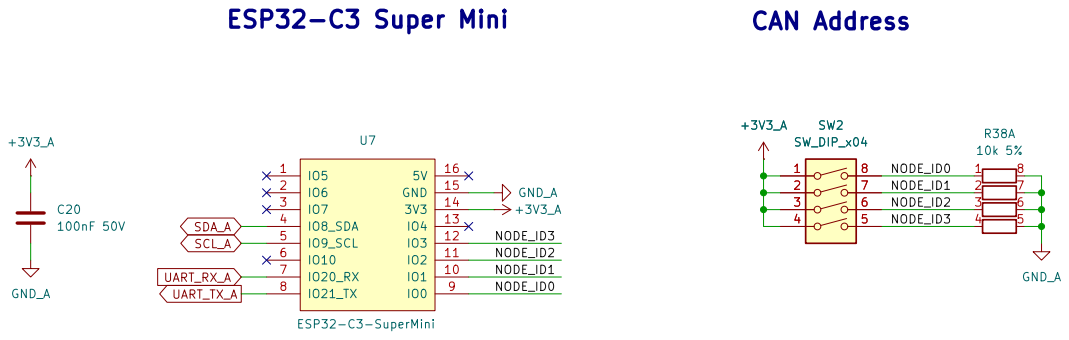
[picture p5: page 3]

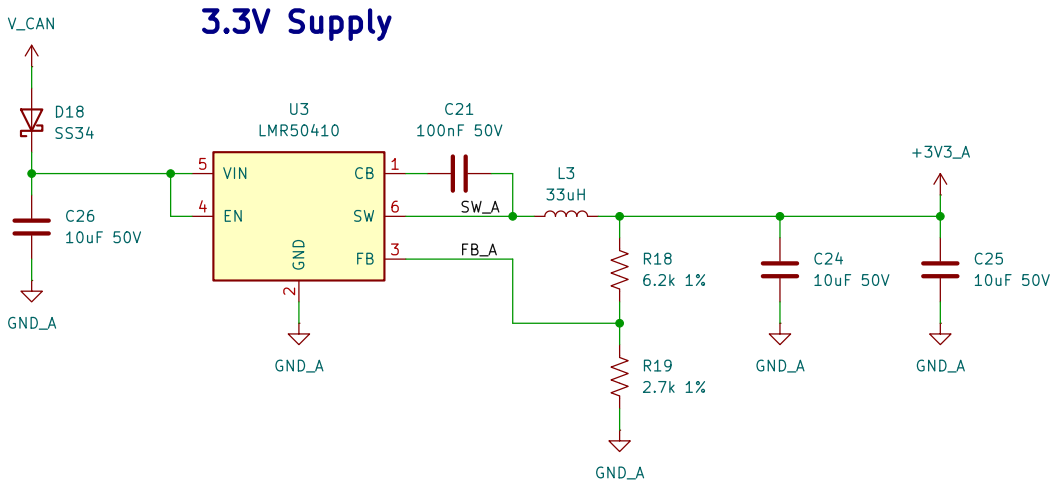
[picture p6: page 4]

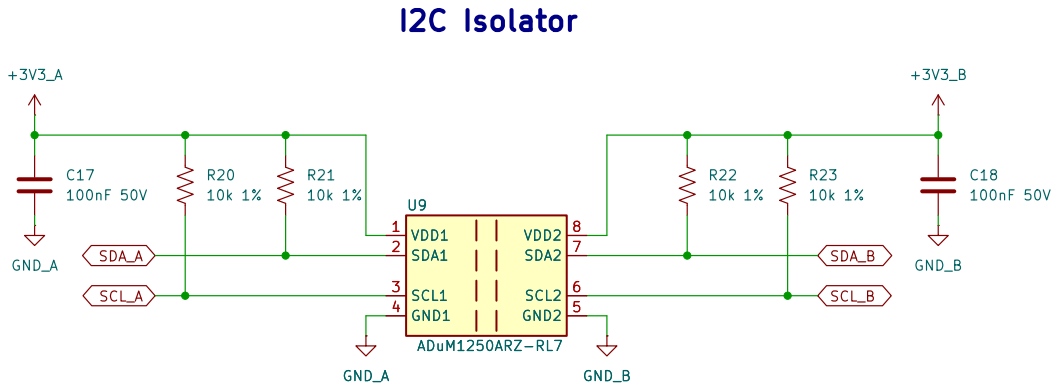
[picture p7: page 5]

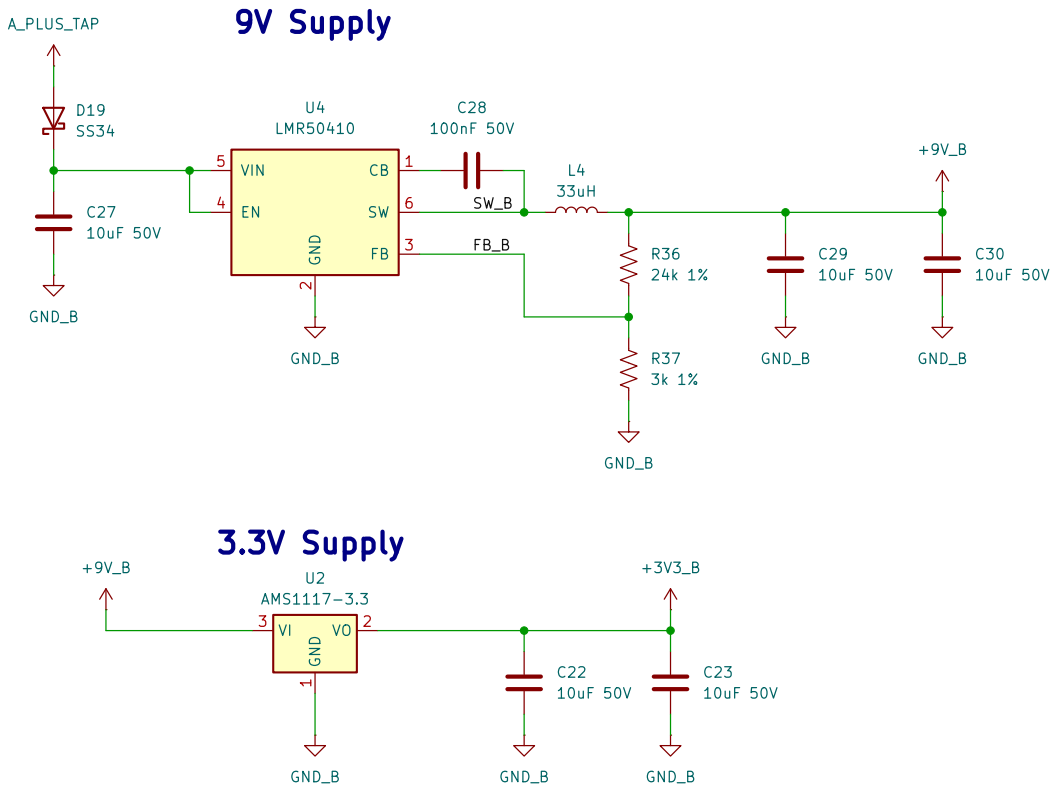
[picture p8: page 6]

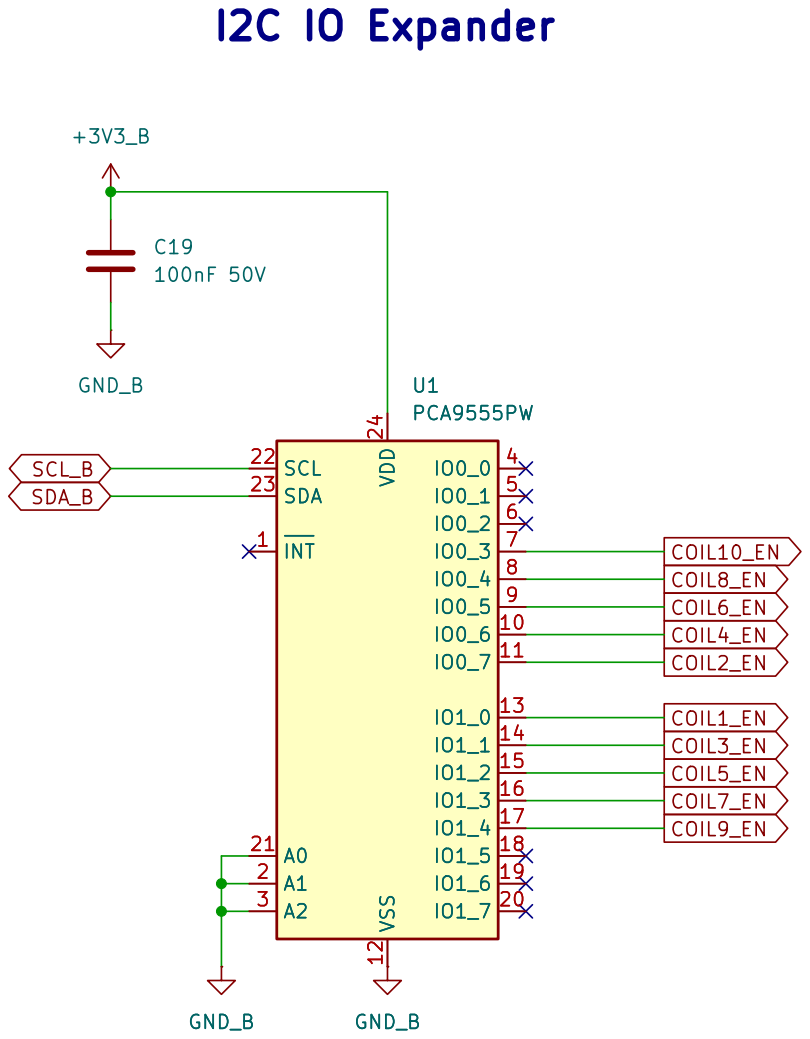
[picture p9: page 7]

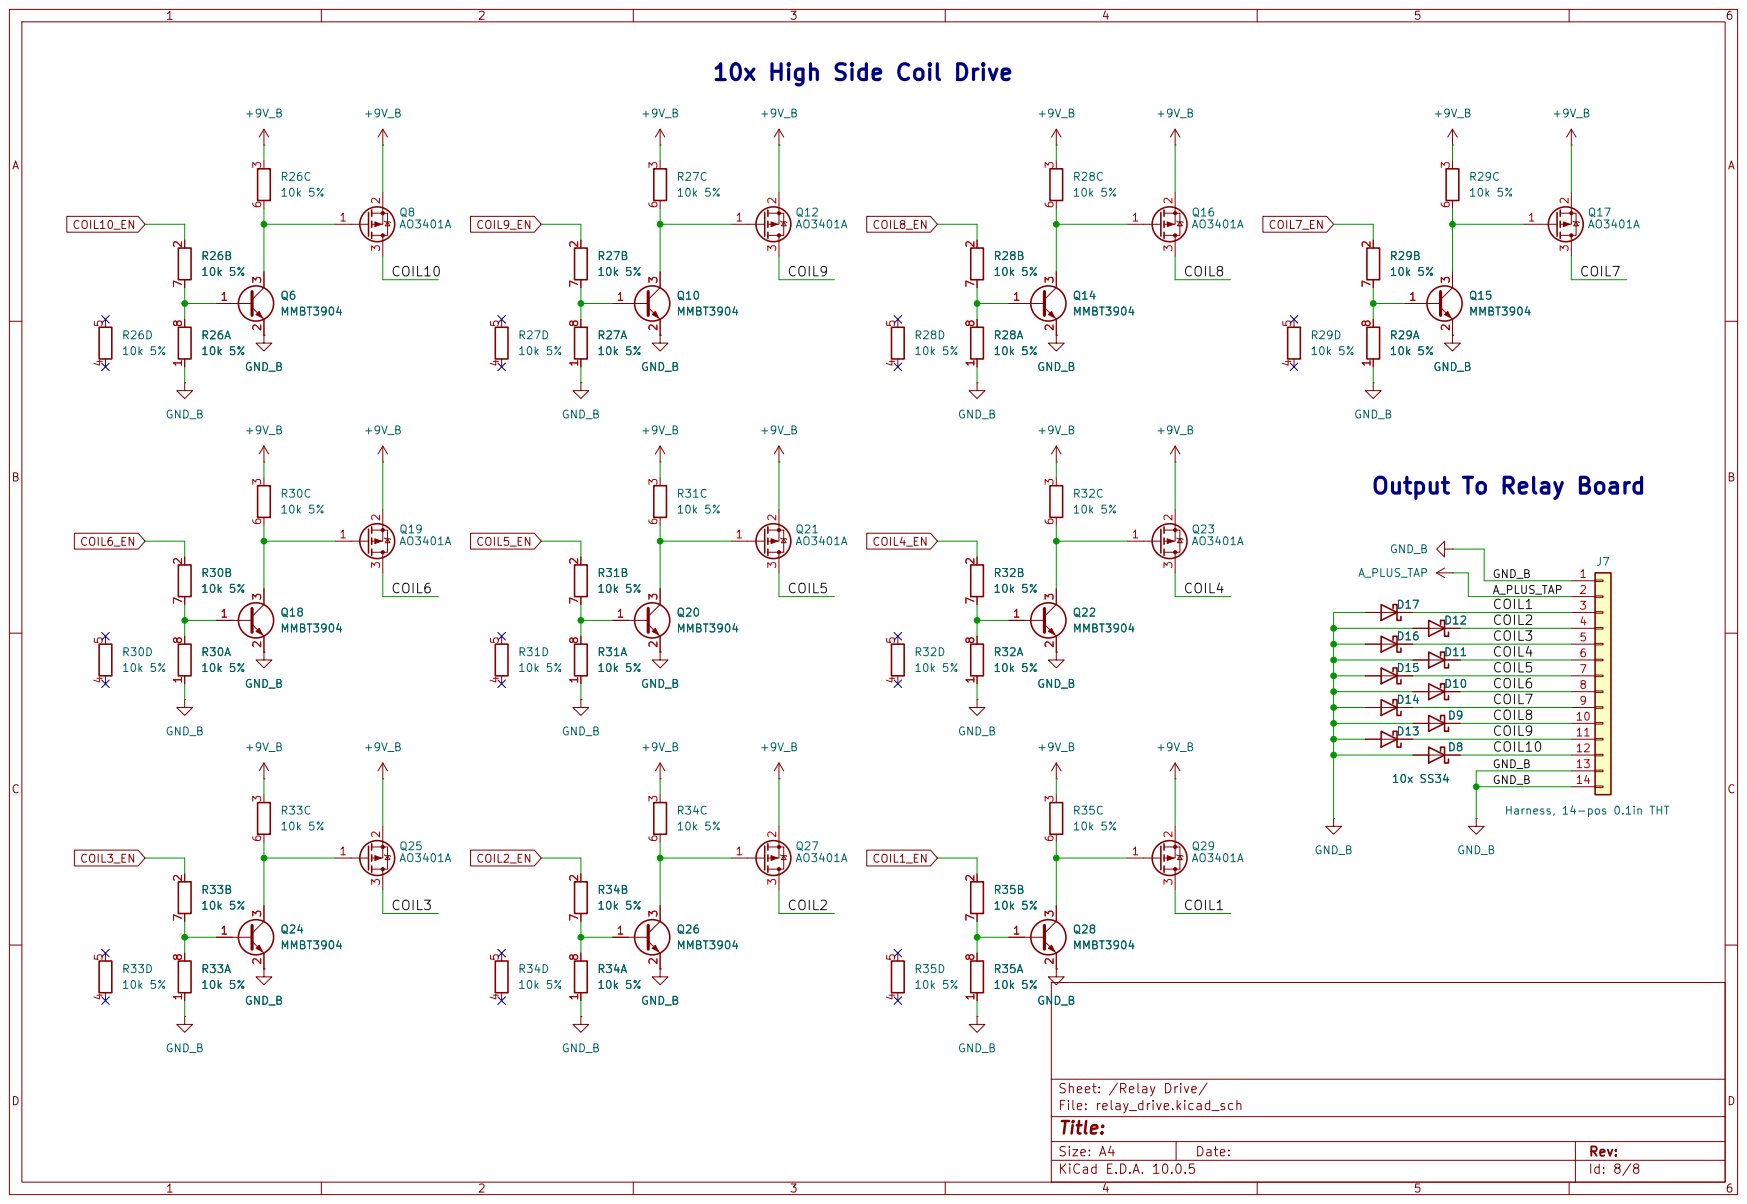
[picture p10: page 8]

10x High Side Coil Drive

Output To Relay Board
GND_B COIL10

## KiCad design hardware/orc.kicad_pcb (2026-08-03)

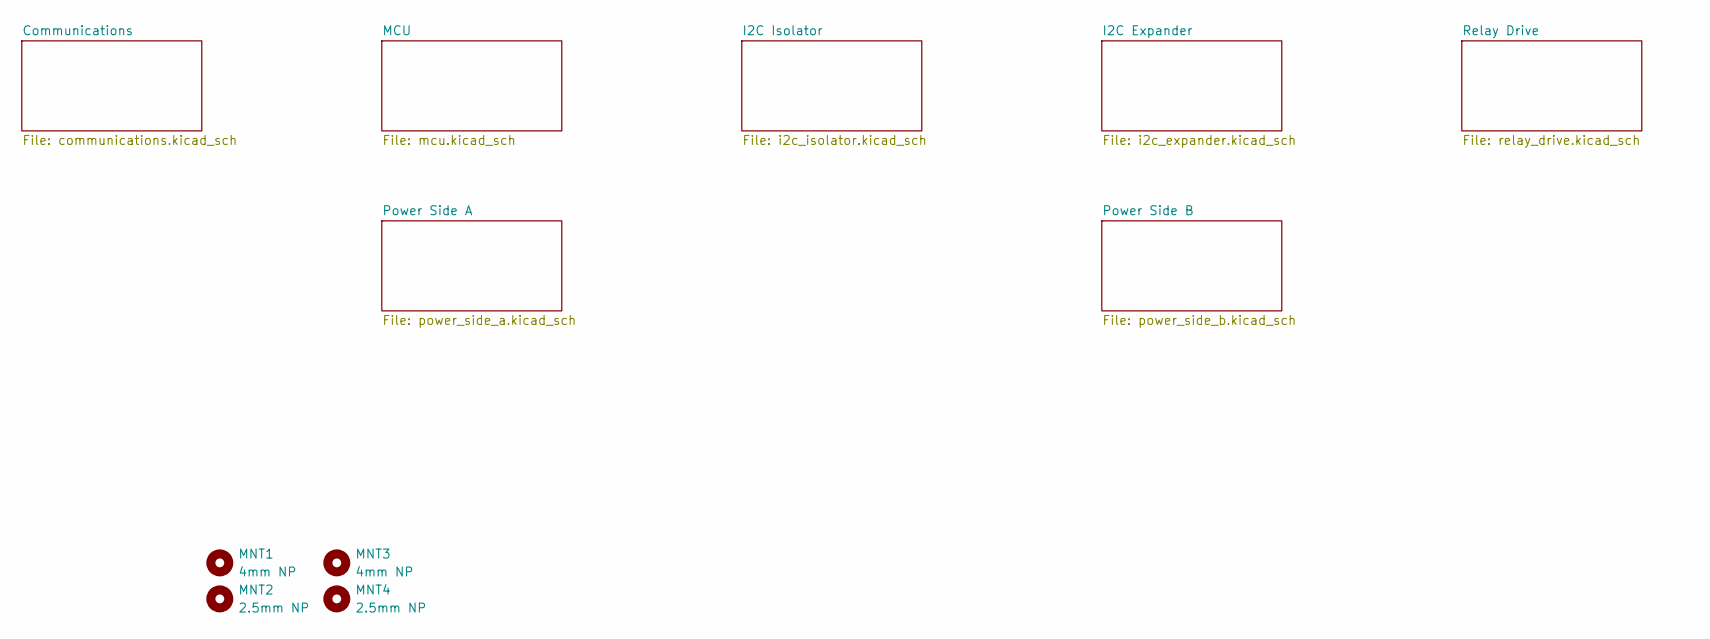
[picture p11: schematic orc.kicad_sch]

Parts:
MNT1, MNT3: 4mm NP; MountingHole_4mm
MNT2, MNT4: 2.5mm NP; MountingHole_2.5mm

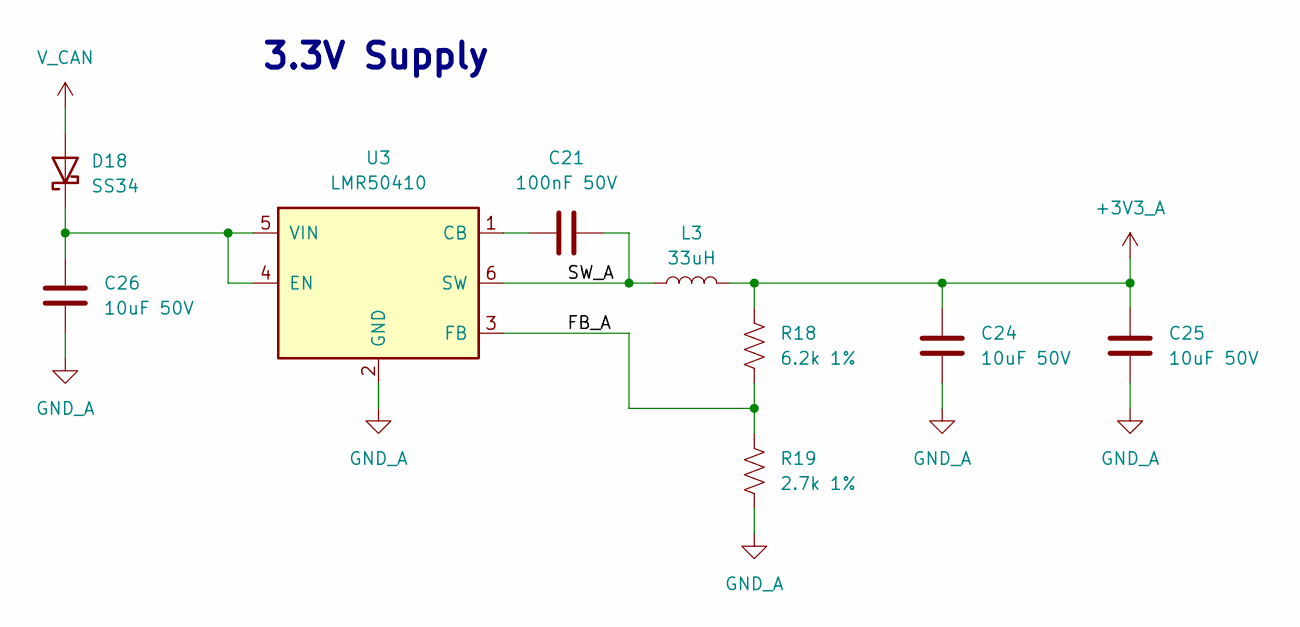
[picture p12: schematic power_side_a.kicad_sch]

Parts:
C21: 100nF 50V; C_0603_1608Metric; LCSC C14663
C24, C25, C26: 10uF 50V; C_0805_2012Metric; LCSC C440198
D18: SS34; D_SMA; LCSC C8678
L3: 33uH; L_Chilisin_BWVS00606045; Manufacturer Part Number SMDRI127-680MT; LCSC C285825
R18: 6.2k 1%; R_0603_1608Metric; LCSC C4260
R19: 2.7k 1%; R_0603_1608Metric; LCSC C13167
U3: LMR50410; SOT-23-6

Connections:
+3V3_A: C24.2, C25.2, L3.2, R18.2; also elsewhere on the board
/Power Side A/FB_A: R18.1, R19.2, U3.3 (FB)
/Power Side A/SW_A: C21.1, L3.1, U3.6 (SW)
GND_A: C24.1, C25.1, C26.1, R19.1, U3.2 (GND); also elsewhere on the board
unnamed: C26.2, D18.1 (K), U3.4 (EN), U3.5 (VIN)
unnamed: C21.2, U3.1 (CB)
V_CAN: D18.2 (A); also elsewhere on the board

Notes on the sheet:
3.3V Supply

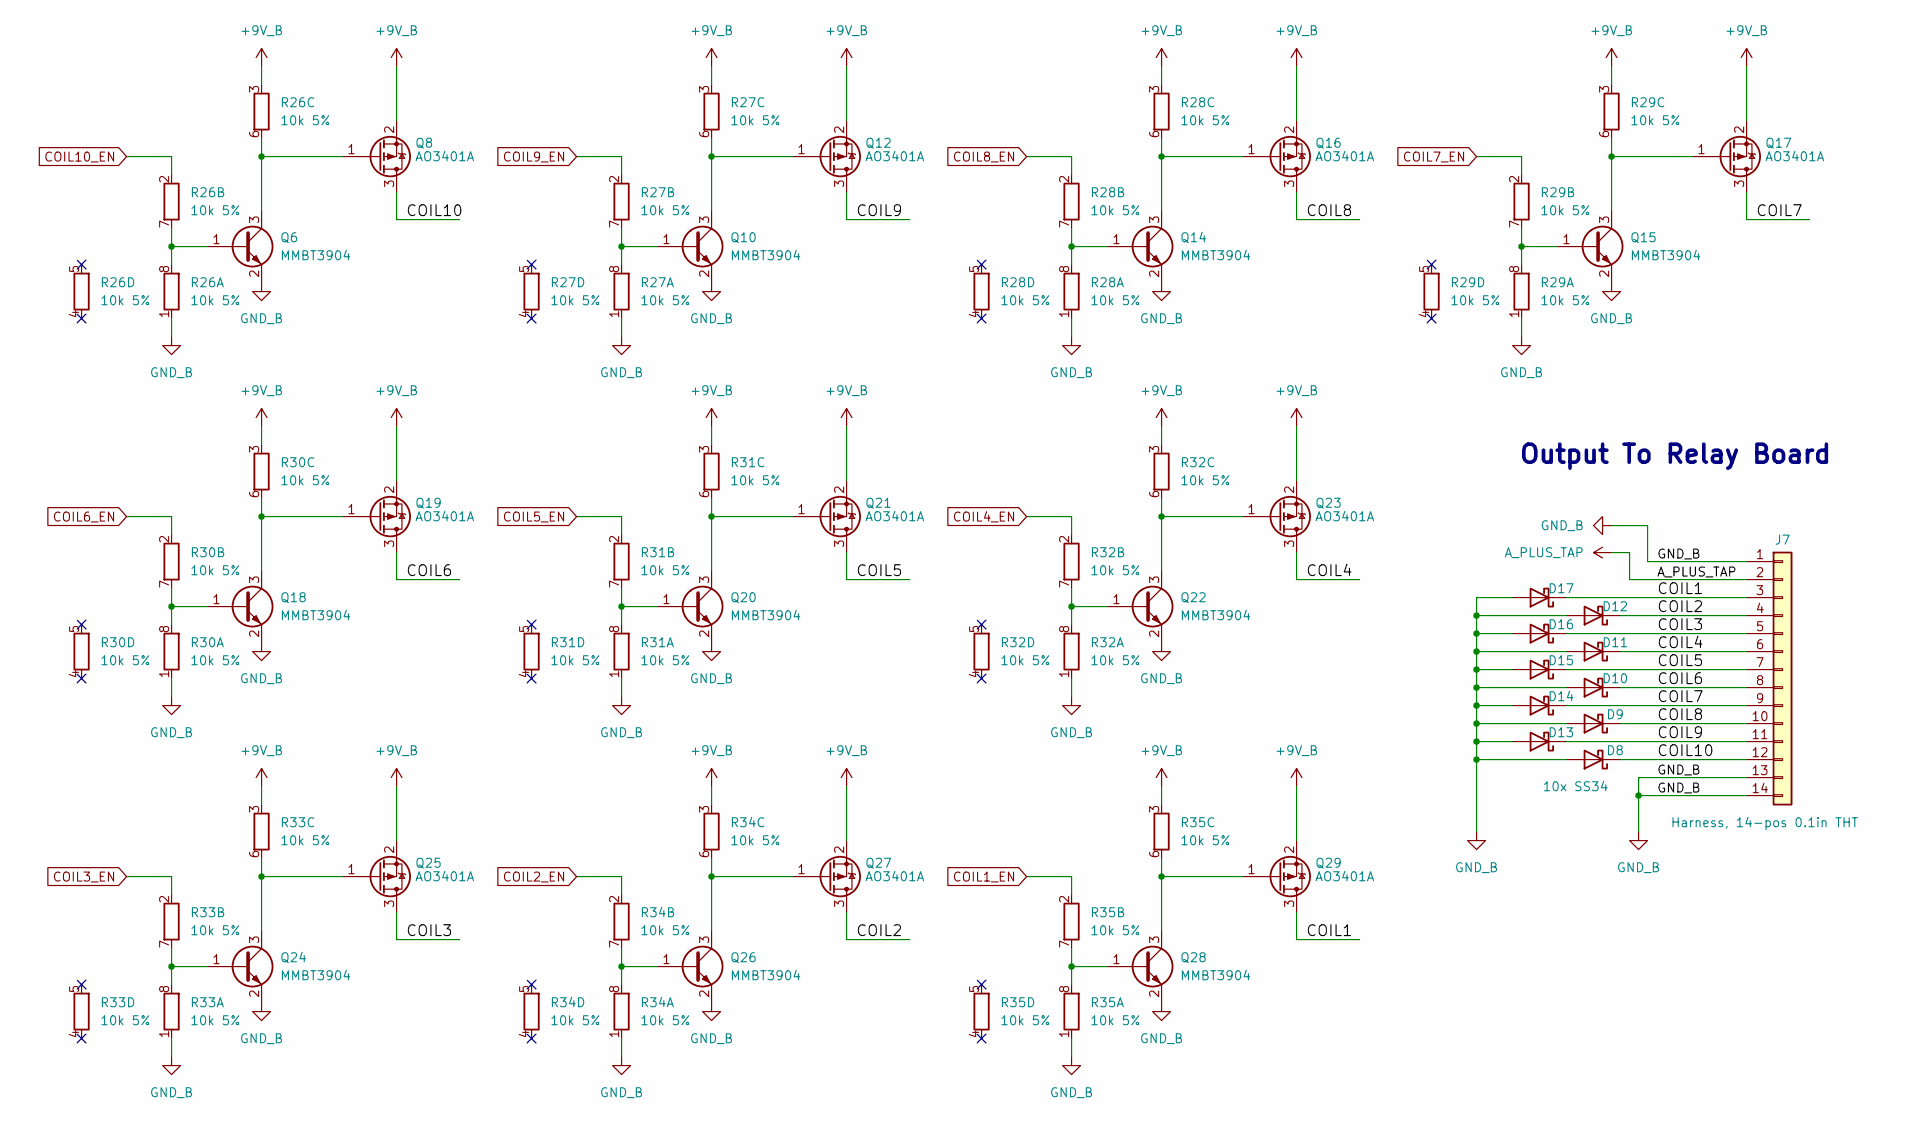
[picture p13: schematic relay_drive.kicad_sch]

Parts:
D8, D9, D10, D11, D12, D13, D14, D15, D16: SS34; D_SMA; LCSC C8678
D17: 10x SS34; D_SMA; LCSC C8678
J7: Harness, 14-pos 0.1in THT; PinSocket_1x14_P2.54mm_Vertical
Q6: MMBT3904; SOT-23; LCSC C20526
Q8, Q12, Q16, Q17, Q19, Q21, Q23, Q25, Q27, Q29: AO3401A; SOT-23; LCSC C15127
Q10, Q14, Q15, Q18, Q20, Q22, Q24, Q26, Q28: MMBT3904; SOT-23
R26, R27, R28, R29, R30, R31, R32, R33, R34, R35: 10k 5%; R_Array_Concave_4x0603; LCSC C29718

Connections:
+9V_B: Q8.2 (S), Q12.2 (S), Q16.2 (S), Q17.2 (S), Q19.2 (S), Q21.2 (S), Q23.2 (S), Q25.2 (S), Q27.2 (S), Q29.2 (S), R26.3 (R3.1), R27.3 (R3.1), R28.3 (R3.1), R29.3 (R3.1), R30.3 (R3.1), R31.3 (R3.1), R32.3 (R3.1), R33.3 (R3.1), R34.3 (R3.1), R35.3 (R3.1); also elsewhere on the board
/Relay Drive/COIL1: D17.1 (K), J7.3, Q29.3 (D)
/Relay Drive/COIL2: D12.1 (K), J7.4, Q27.3 (D)
/Relay Drive/COIL3: D16.1 (K), J7.5, Q25.3 (D)
/Relay Drive/COIL4: D11.1 (K), J7.6, Q23.3 (D)
/Relay Drive/COIL5: D15.1 (K), J7.7, Q21.3 (D)
/Relay Drive/COIL6: D10.1 (K), J7.8, Q19.3 (D)
/Relay Drive/COIL7: D14.1 (K), J7.9, Q17.3 (D)
/Relay Drive/COIL8: D9.1 (K), J7.10, Q16.3 (D)
/Relay Drive/COIL9: D13.1 (K), J7.11, Q12.3 (D)
/Relay Drive/COIL10: D8.1 (K), J7.12, Q8.3 (D)
A_PLUS_TAP: J7.2; also elsewhere on the board
COIL1_EN: R35.2 (R2.1); also elsewhere on the board
COIL2_EN: R34.2 (R2.1); also elsewhere on the board
COIL3_EN: R33.2 (R2.1); also elsewhere on the board
COIL4_EN: R32.2 (R2.1); also elsewhere on the board
COIL5_EN: R31.2 (R2.1); also elsewhere on the board
COIL6_EN: R30.2 (R2.1); also elsewhere on the board
COIL7_EN: R29.2 (R2.1); also elsewhere on the board
COIL8_EN: R28.2 (R2.1); also elsewhere on the board
COIL9_EN: R27.2 (R2.1); also elsewhere on the board
COIL10_EN: R26.2 (R2.1); also elsewhere on the board
GND_B: D8.2 (A), D9.2 (A), D10.2 (A), D11.2 (A), D12.2 (A), D13.2 (A), D14.2 (A), D15.2 (A), D16.2 (A), D17.2 (A), J7.1, J7.13, J7.14, Q6.2 (E), Q10.2 (E), Q14.2 (E), Q15.2 (E), Q18.2 (E), Q20.2 (E), Q22.2 (E), Q24.2 (E), Q26.2 (E), Q28.2 (E), R26.1 (R1.1), R27.1 (R1.1), R28.1 (R1.1), R29.1 (R1.1), R30.1 (R1.1), R31.1 (R1.1), R32.1 (R1.1), R33.1 (R1.1), R34.1 (R1.1), R35.1 (R1.1); also elsewhere on the board
unnamed: Q6.1 (B), R26.7 (R2.2), R26.8 (R1.2)
unnamed: Q6.3 (C), Q8.1 (G), R26.6 (R3.2)
unnamed: Q10.1 (B), R27.7 (R2.2), R27.8 (R1.2)
unnamed: Q10.3 (C), Q12.1 (G), R27.6 (R3.2)
unnamed: Q14.1 (B), R28.7 (R2.2), R28.8 (R1.2)
unnamed: Q14.3 (C), Q16.1 (G), R28.6 (R3.2)
unnamed: Q15.1 (B), R29.7 (R2.2), R29.8 (R1.2)
unnamed: Q15.3 (C), Q17.1 (G), R29.6 (R3.2)
unnamed: Q18.1 (B), R30.7 (R2.2), R30.8 (R1.2)
unnamed: Q18.3 (C), Q19.1 (G), R30.6 (R3.2)
unnamed: Q20.1 (B), R31.7 (R2.2), R31.8 (R1.2)
unnamed: Q20.3 (C), Q21.1 (G), R31.6 (R3.2)
unnamed: Q22.1 (B), R32.7 (R2.2), R32.8 (R1.2)
unnamed: Q22.3 (C), Q23.1 (G), R32.6 (R3.2)
unnamed: Q24.1 (B), R33.7 (R2.2), R33.8 (R1.2)
unnamed: Q24.3 (C), Q25.1 (G), R33.6 (R3.2)
unnamed: Q26.1 (B), R34.7 (R2.2), R34.8 (R1.2)
unnamed: Q26.3 (C), Q27.1 (G), R34.6 (R3.2)
unnamed: Q28.1 (B), R35.7 (R2.2), R35.8 (R1.2)
unnamed: Q28.3 (C), Q29.1 (G), R35.6 (R3.2)

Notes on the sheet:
Output To Relay Board

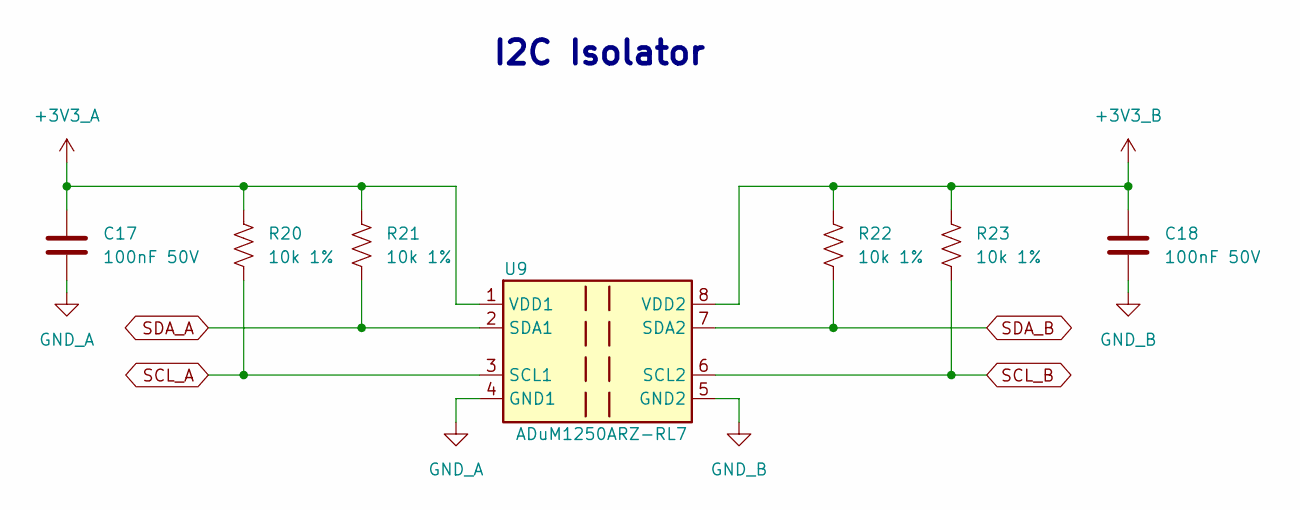
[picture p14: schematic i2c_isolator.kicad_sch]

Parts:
C17, C18: 100nF 50V; C_0603_1608Metric; LCSC C14663
R20, R21, R22, R23: 10k 1%; R_0603_1608Metric; LCSC C25804
U9: ADuM1250ARZ-RL7; SOIC-8_3.9x4.9mm_P1.27mm; LCSC C13839

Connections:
+3V3_A: C17.2, R20.1, R21.1, U9.1 (VDD1); also elsewhere on the board
+3V3_B: C18.2, R22.1, R23.1, U9.8 (VDD2); also elsewhere on the board
GND_A: C17.1, U9.4 (GND1); also elsewhere on the board
GND_B: C18.1, U9.5 (GND2); also elsewhere on the board
SCL_A: R20.2, U9.3 (SCL1); also elsewhere on the board
SCL_B: R23.2, U9.6 (SCL2); also elsewhere on the board
SDA_A: R21.2, U9.2 (SDA1); also elsewhere on the board
SDA_B: R22.2, U9.7 (SDA2); also elsewhere on the board

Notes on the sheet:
I2C Isolator

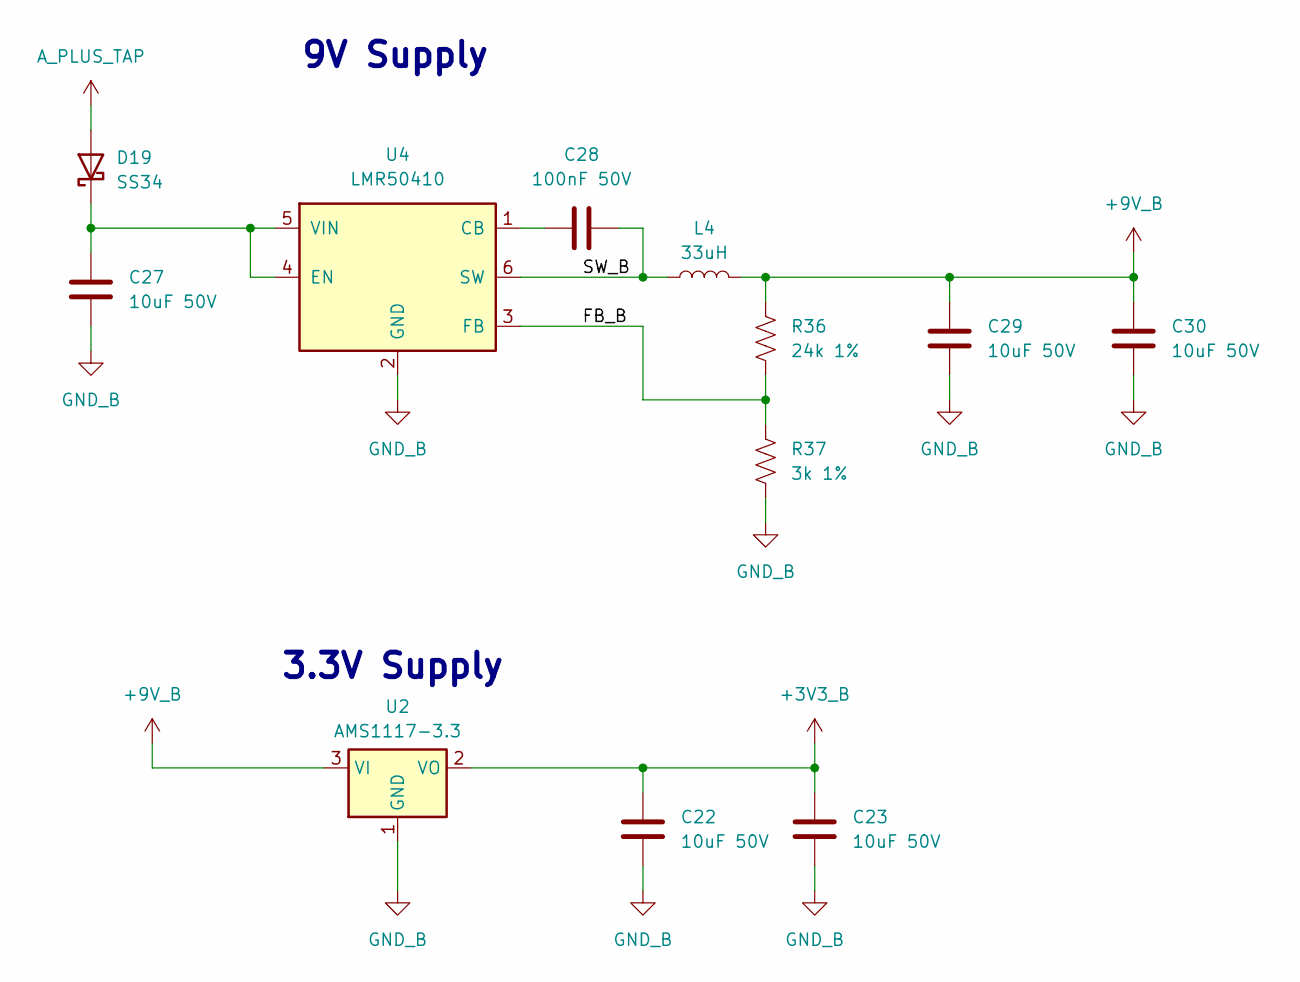
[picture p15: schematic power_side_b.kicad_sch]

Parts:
C22, C23, C27, C29, C30: 10uF 50V; C_0805_2012Metric; LCSC C440198
C28: 100nF 50V; C_0603_1608Metric; LCSC C14663
D19: SS34; D_SMA; LCSC C8678
L4: 33uH; L_Chilisin_BWVS00606045; Manufacturer Part Number SMDRI127-680MT; LCSC C285825
R36: 24k 1%; R_0603_1608Metric; LCSC C23352
R37: 3k 1%; R_0603_1608Metric; LCSC C4211
U2: AMS1117-3.3; SOT-223-3_TabPin2; LCSC C6186
U4: LMR50410; SOT-23-6

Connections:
+3V3_B: C22.2, C23.2, U2.2 (VO); also elsewhere on the board
+9V_B: C29.2, C30.2, L4.2, R36.2, U2.3 (VI); also elsewhere on the board
/Power Side B/FB_B: R36.1, R37.2, U4.3 (FB)
/Power Side B/SW_B: C28.1, L4.1, U4.6 (SW)
A_PLUS_TAP: D19.2 (A); also elsewhere on the board
GND_B: C22.1, C23.1, C27.1, C29.1, C30.1, R37.1, U2.1 (GND), U4.2 (GND); also elsewhere on the board
unnamed: C27.2, D19.1 (K), U4.4 (EN), U4.5 (VIN)
unnamed: C28.2, U4.1 (CB)

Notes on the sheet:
9V Supply
3.3V Supply

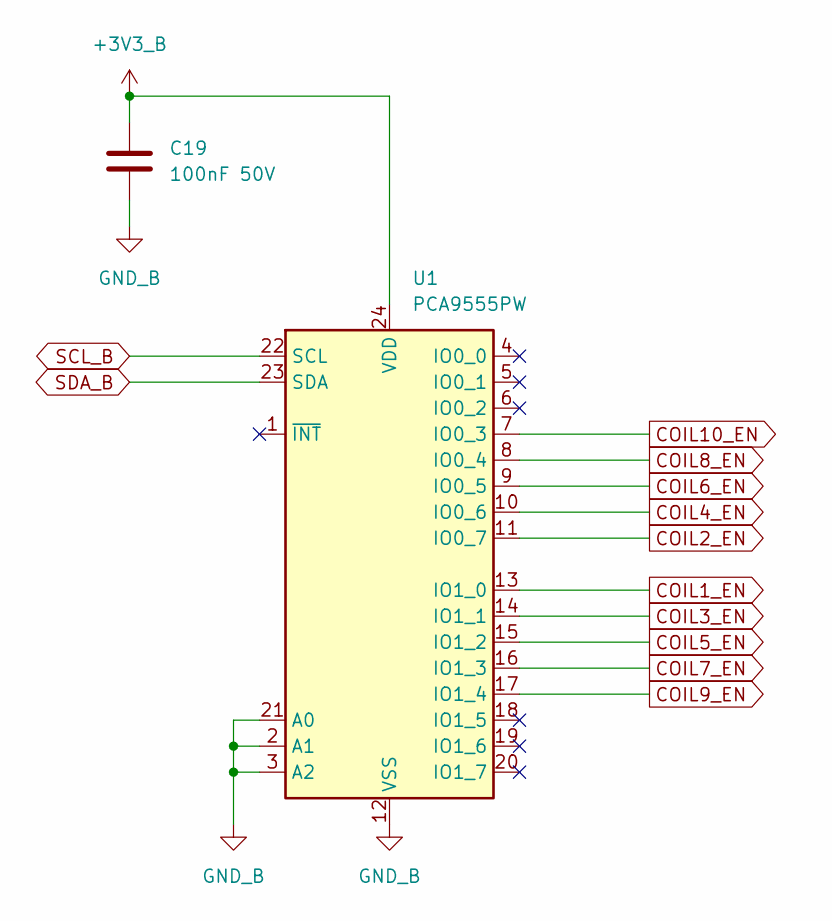
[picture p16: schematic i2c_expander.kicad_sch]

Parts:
C19: 100nF 50V; C_0603_1608Metric; LCSC C14663
U1: PCA9555PW; TSSOP-24_4.4x7.8mm_P0.65mm; LCSC C128392

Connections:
+3V3_B: C19.2, U1.24 (VDD); also elsewhere on the board
COIL1_EN: U1.13 (IO1_0); also elsewhere on the board
COIL2_EN: U1.11 (IO0_7); also elsewhere on the board
COIL3_EN: U1.14 (IO1_1); also elsewhere on the board
COIL4_EN: U1.10 (IO0_6); also elsewhere on the board
COIL5_EN: U1.15 (IO1_2); also elsewhere on the board
COIL6_EN: U1.9 (IO0_5); also elsewhere on the board
COIL7_EN: U1.16 (IO1_3); also elsewhere on the board
COIL8_EN: U1.8 (IO0_4); also elsewhere on the board
COIL9_EN: U1.17 (IO1_4); also elsewhere on the board
COIL10_EN: U1.7 (IO0_3); also elsewhere on the board
GND_B: C19.1, U1.2 (A1), U1.3 (A2), U1.12 (VSS), U1.21 (A0); also elsewhere on the board
SCL_B: U1.22 (SCL); also elsewhere on the board
SDA_B: U1.23 (SDA); also elsewhere on the board

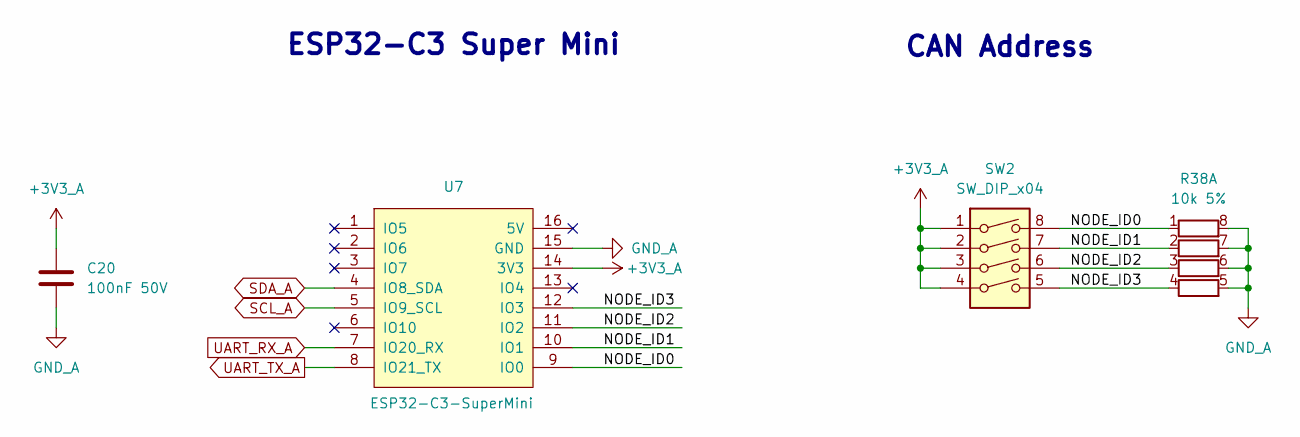
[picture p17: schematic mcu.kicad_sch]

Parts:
C20: 100nF 50V; C_0603_1608Metric; LCSC C14663
R38: 10k 5%; R_Array_Concave_4x0603; LCSC C29718
SW2: SW_DIP_x04; SOIC-8_5.3x5.3mm_P1.27mm; LCSC C3293144
U7: ESP32-C3-SuperMini

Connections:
+3V3_A: C20.2, SW2.1, SW2.2, SW2.3, SW2.4, U7.14 (3V3); also elsewhere on the board
/MCU/NODE_ID0: R38.1 (R1.1), SW2.8, U7.9 (IO0)
/MCU/NODE_ID1: R38.2 (R2.1), SW2.7, U7.10 (IO1)
/MCU/NODE_ID2: R38.3 (R3.1), SW2.6, U7.11 (IO2)
/MCU/NODE_ID3: R38.4 (R4.1), SW2.5, U7.12 (IO3)
GND_A: C20.1, R38.5 (R4.2), R38.6 (R3.2), R38.7 (R2.2), R38.8 (R1.2), U7.15 (GND); also elsewhere on the board
SCL_A: U7.5 (IO9_SCL); also elsewhere on the board
SDA_A: U7.4 (IO8_SDA); also elsewhere on the board
UART_RX_A: U7.7 (IO20_RX); also elsewhere on the board
UART_TX_A: U7.8 (IO21_TX); also elsewhere on the board

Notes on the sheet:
ESP32-C3 Super Mini
CAN Address

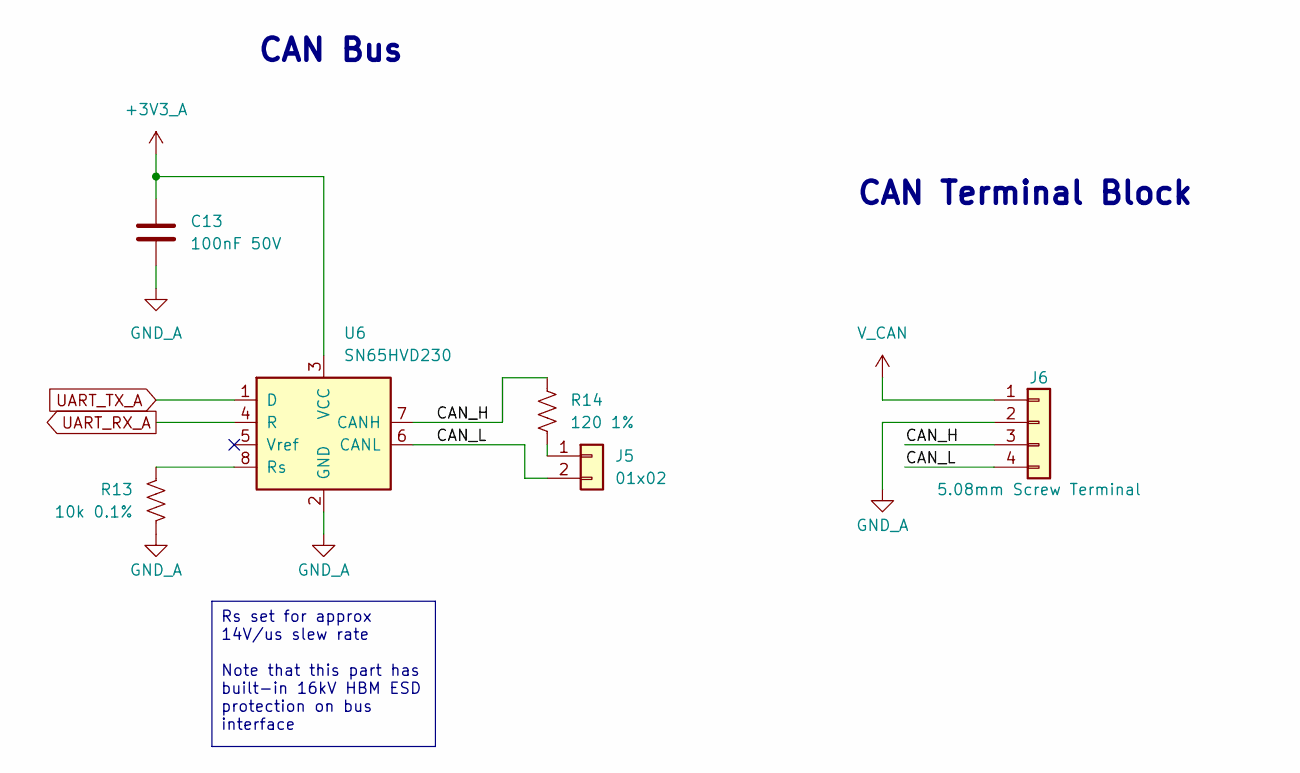
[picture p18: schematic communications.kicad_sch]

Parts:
C13: 100nF 50V; C_0603_1608Metric; LCSC C14663
J5: 01x02; PinHeader_1x02_P2.54mm_Vertical; LCSC C492401
J6: 5.08mm Screw Terminal; Samtec_HPM-04-01-x-S_Straight_1x04_Pitch5.08mm; LCSC C2827883
R13: 10k 0.1%; R_0603_1608Metric; LCSC C95204
R14: 120 1%; R_1206_3216Metric; LCSC C17909
U6: SN65HVD230; SOIC-8_3.9x4.9mm_P1.27mm; LCSC C12084

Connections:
+3V3_A: C13.2, U6.3 (VCC); also elsewhere on the board
/Communications/CAN_H: J6.3, R14.2, U6.7 (CANH)
/Communications/CAN_L: J5.2, J6.4, U6.6 (CANL)
GND_A: C13.1, J6.2, R13.1, U6.2 (GND); also elsewhere on the board
unnamed: J5.1, R14.1
unnamed: R13.2, U6.8 (Rs)
UART_RX_A: U6.4 (R); also elsewhere on the board
UART_TX_A: U6.1 (D); also elsewhere on the board
V_CAN: J6.1; also elsewhere on the board

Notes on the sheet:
CAN Bus
CAN Terminal Block
Rs set for approx 14V/us slew rate Note that this part has built-in 16kV HBM ESD protection on bus interface

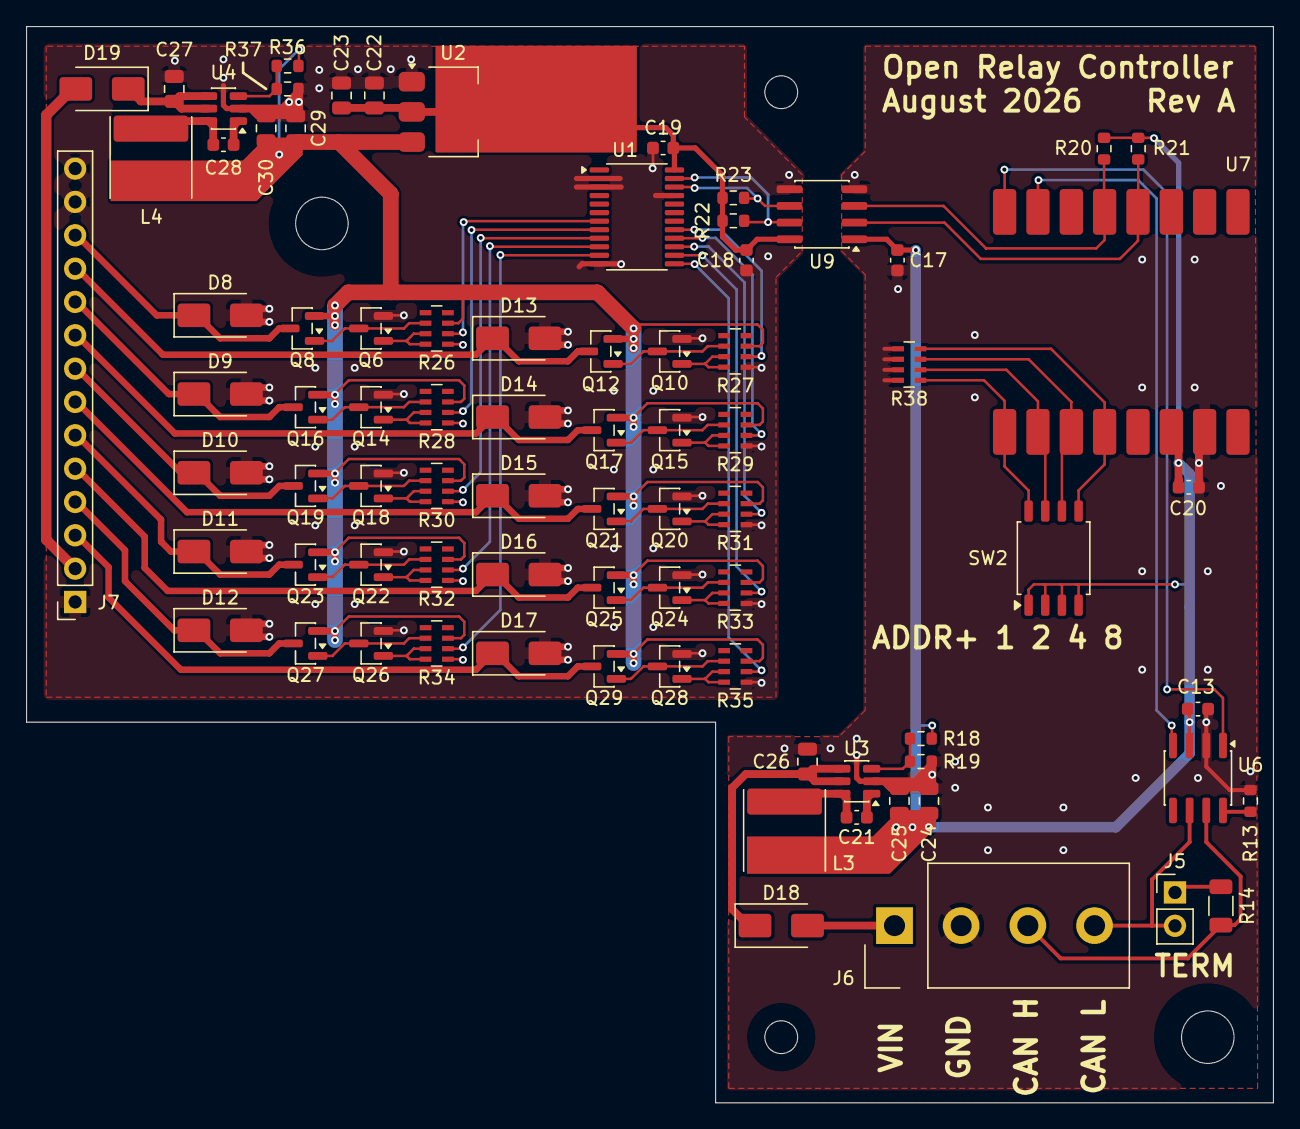
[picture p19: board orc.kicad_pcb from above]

Board: 2 copper layers, 95.0 x 82.0 mm, 85 parts (0 on the bottom side), 69 nets.

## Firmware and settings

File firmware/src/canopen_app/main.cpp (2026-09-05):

// SPDX-License-Identifier: Apache-2.0
// Copyright (c) 2026 Aram Dergevorkian
// ORC application firmware: CANopen relay control, driven from CAN or USB
//
// This IS application-level firmware, unlike everything else in firmware/ --
// it's the real protocol ORC will run in the field, per
// docs/can-protocol-research.md and .claude/can-application-firmware-prompt.md.
// Built on top of, not replacing, the existing IO-level bring-up sketches:
// - lib/orc_can_addr's node-ID read is reused unchanged.
// - Real channel-to-PCA9555-register mapping, confirmed 2026-08-05 against
//   the actual schematic (docs/subcircuit-capture-guide.md's "Channel
//   mapping" table, read off hardware/i2c_expander.kicad_sch) and
//   implemented in firmware/lib/orc_relay_map/ -- routing-driven, NOT the
//   sequential "channels 1-8 = Port0 whole byte, 9-10 = Port1 bits 0-1"
//   layout pca9555_bringup originally assumed (that assumption was wrong;
//   pca9555_bringup has been corrected to match, same lib, same day).
// - uart_can_bringup's raw-UART transport is SUPERSEDED, not extended: this
//   firmware uses the ESP-IDF/Arduino-ESP32 TWAI driver on the same
//   GPIO21(TX)/GPIO20(RX) pins instead, per can-protocol-research.md's
//   UART-vs-TWAI resolution (TWAI has no dedicated IO_MUX pin -- it's
//   GPIO-Matrix-routable to any GPIO, so this is a firmware peripheral
//   change with zero schematic/pinout impact).
//
// FR-004 (2026-08-10): USB control consolidated in from the now-retired
// usb_bench sketch. Real ORC PCBs are in hand and under active bench test
// as of this pass -- see docs/features/FR-004.md and firmware/README.md's
// "Real-hardware run, 2026-08-10" section. This firmware now drives relays
// from CAN (RPDO1) or USB (plain-ASCII protocol, docs/usb-bench-interface-spec.md)
// against the SAME PCA9555 state, with a single read-back feeding both
// CAN's TPDO1 broadcast and USB's unsolicited STATE lines -- a change from
// either interface is visible on both. See docs/features/FR-004.md for the
// full design writeup, including why a naive shared fail-safe clock would
// NOT correctly implement "any activity resets both" (the tighter of two
// thresholds always wins on a shared clock, making the looser one dead
// code) and what was actually built instead (context-sensitive threshold
// based on which interface supplied the most recent activity).
//
// KNOWN LIMITATION, documented not silently accepted (FR-004 Scope item 5):
// this file's Serial output was always a human debug log (RPDO1 dumps,
// TWAI errors, SDO writes, etc.), not the strictly line-clean protocol
// usb_bench alone was. That debug prose is now interleaved with the real
// PONG/STATE/ERR/HB protocol lines on the same port. A host-side parser
// MUST tolerate/ignore unrecognized lines -- the spec already required
// this for interleaved unsolicited lines; it now also covers diagnostic
// prose, not just other protocol lines.

#include <Arduino.h>
#include <Wire.h>
#include <Preferences.h>
#include <ctype.h>
#include <string.h>
#include "driver/twai.h"
#include "esp_timer.h"
#include "orc_can_addr.h"
#include "orc_canopen.h"
#include "orc_relay_map.h"

// --- Pin assignment ---------------------------------------------------------
// Separate ORC_TWAI_* build flags from the existing ORC_UART_TX_PIN/RX_PIN,
// even though both name the same physical GPIO21/GPIO20 -- uart_can_bringup
// and this firmware drive genuinely different on-chip peripherals (UART1 vs
// TWAI) on those pins, and reusing the UART-named constant here would read
// as if this were still UART-based. See platformio.ini for the values.
static const gpio_num_t kTwaiTxPin = (gpio_num_t)ORC_TWAI_TX_PIN;
static const gpio_num_t kTwaiRxPin = (gpio_num_t)ORC_TWAI_RX_PIN;
static const uint8_t kPca9555Addr = ORC_PCA9555_ADDR;
static const uint8_t kI2cSdaPin = ORC_I2C_SDA_PIN;
static const uint8_t kI2cSclPin = ORC_I2C_SCL_PIN;

// --- PCA9555 register map (NXP datasheet command bytes) -- same as pca9555_bringup ---
static const uint8_t kRegOutputPort0 = 0x02;
static const uint8_t kRegOutputPort1 = 0x03;
static const uint8_t kRegInputPort0 = 0x00;
static const uint8_t kRegInputPort1 = 0x01;
static const uint8_t kRegPolarityPort0 = 0x04;
static const uint8_t kRegPolarityPort1 = 0x05;
static const uint8_t kRegConfigPort0 = 0x06;
static const uint8_t kRegConfigPort1 = 0x07;
// Config values: kOrcPca9555ConfigPort0/Port1, from lib/orc_relay_map/ --
// the real schematic's spares are 3 non-contiguous bits per port (Port0
// bits0-2, Port1 bits5-7), not the old "channels 9-10 only used on Port1"
// assumption these two masks used to encode locally.

// --- Timing defaults ---------------------------------------------------------
static const uint16_t kTpdo2DefaultIntervalMs = 1000;
static const uint32_t kHeartbeatIntervalMs = 1000;  // fixed, not SDO-configurable per the spec's scope
// Control-activity fail-safe: de-energize all channels if neither interface
// has produced a real command in this window. Two thresholds, not one --
// see the file header and docs/features/FR-004.md for why a single shared
// threshold doesn't actually implement "any activity resets both" the way
// it needs to. 5000ms (CAN) is not derived from any documented host command
// cadence (RPDO1 is event-driven, not periodic) -- picked as 5x the
// TPDO2/Heartbeat default period, comfortable margin against normal idle
// gaps while still failing safe within a human-noticeable few seconds.
// 30000ms (USB) is generous specifically because a human typing commands by
// hand pauses far longer than a machine's command cadence -- ported
// unchanged from usb_bench/FR-001's own reasoning.
static const uint32_t kCanActivityTimeoutMs = 5000;
static const uint32_t kUsbIdleTimeoutMs = 30000;

// --- USB protocol constants (docs/usb-bench-interface-spec.md) -------------
static const size_t kMaxLineLen = 128;
static const char *kFwVersion = "orc-canopen-fr004";
static const char *kBuildDate = __DATE__ " " __TIME__;

// --- Runtime state -----------------------------------------------------------
static uint8_t g_nodeId = 0;
static bool g_canAvailable = false;  // true once TWAI installs and starts successfully -- no
                                      // longer gated on node ID being nonzero, see setup()
static uint8_t g_relayPort0 = 0;  // last-commanded PCA9555 Output Port 0 (channels 1-8)
static uint8_t g_relayPort1 = 0;  // last-commanded PCA9555 Output Port 1 bits 0-1 (channels 9-10)
static uint16_t g_lastAppliedMask = 0;  // last channel mask actually observed via PCA9555 read-back
static bool g_deenergizedByTimeout = false;
// BUG-001 fix, still in force: whether the PCA9555 ACKed. false means relay
// I/O (RPDO1/TPDO1 on CAN, SET/GET/STATUS on USB) is unavailable, but
// whichever interface(s) are otherwise up keep working -- see
// requireRelayHardware() and probeAndConfigurePca9555() below.
static bool g_pca9555Present = false;

// Which interface most recently produced real activity, and when -- see
// checkControlActivityTimeout() for how this picks the applicable
// fail-safe threshold. kNone is the boot default (channels already off, so
// a timeout firing before anything ever arrives is harmless).
enum class ActivitySource { kNone, kCan, kUsb };
static ActivitySource g_lastActivitySource = ActivitySource::kNone;
static unsigned long g_lastActivityMillis = 0;

static unsigned long g_lastTpdo2Millis = 0;
static unsigned long g_lastHeartbeatMillis = 0;
static uint16_t g_tpdo2IntervalMs = kTpdo2DefaultIntervalMs;
static bool g_busOffRecoveryInitiated = false;
static unsigned long g_lastHealthCheckMillis = 0;
// Fixed cadence, deliberately independent of g_tpdo2IntervalMs -- that value
// is SDO-configurable by the host and could be set far higher than is
// reasonable for noticing/recovering from a bus fault promptly.
static const uint32_t kHealthCheckIntervalMs = 1000;

static Preferences g_prefs;
static const char *kPrefsNamespace = "orc_cfg";
static const char *kPrefsTpdo2Key = "tpdo2_ms";

// --- USB line-reader state ---------------------------------------------------
static char g_lineBuf[kMaxLineLen + 1];
static size_t g_lineLen = 0;
static bool g_lineOverflow = false;

// Forward declaration: printBestEffort() is defined later in this file (near
// twaiSend()), but pca9555WriteReg() below needs it -- BUG-005 fix moves its
// failure diagnostic off a raw (blocking) Serial.printf() onto the
// best-effort path, same reasoning as BUG-002/BUG-004.
static void printBestEffort(const char *s);

// --- PCA9555 I2C helpers, same pattern as pca9555_bringup --------------------
static bool pca9555WriteReg(uint8_t reg, uint8_t value) {
  Wire.beginTransmission(kPca9555Addr);
  Wire.write(reg);
  Wire.write(value);
  uint8_t result = Wire.endTransmission();
  if (result != 0) {
    // BUG-005 fix: only log on the actual present -> absent transition, not
    // on every failed write while the chip is already known absent. Before
    // this, EVERY failed write printed unconditionally via a raw (blocking)
    // Serial.printf() -- one of three contributors this bug's shard
    // identified to loop() stalling to ~0.1 Hz with the isolated DC side
    // disconnected (docs/features/BUG-005.md, "mechanism 3"). Best-effort,
    // not blocking, and rate-limited to one line per transition.
    bool wasPresent = g_pca9555Present;
    g_pca9555Present = false;
    if (wasPresent) {
      char msg[128];
      snprintf(msg, sizeof(msg),
               "PCA9555 I2C write FAILED (reg 0x%02X, val 0x%02X): endTransmission=%u -- "
               "hardware now considered absent.\n",
               reg, value, result);
      printBestEffort(msg);
    }
    return false;
  }
  return true;
}

// Reads back the PCA9555's Input Port registers -- for a pin configured as
// an output, this reflects the actual driven logic level, not just the
// commanded value, so it's a genuine (if not current-sensed) "applied
// state" confirmation, not just an echo of what was written.
static bool pca9555ReadInputPorts(uint8_t &port0, uint8_t &port1) {
  Wire.beginTransmission(kPca9555Addr);
  Wire.write(kRegInputPort0);
  if (Wire.endTransmission(false) != 0) {
    g_pca9555Present = false;
    return false;
  }
  if (Wire.requestFrom((int)kPca9555Addr, 2) != 2) {
    g_pca9555Present = false;
    return false;
  }
  port0 = Wire.read();
  port1 = Wire.read();
  return true;
}

// Re-issues the PCA9555's Output, Polarity, and Config registers using the
// last-commanded state (g_relayPort0/g_relayPort1) -- self-heals a PCA9555
// that lost its configuration to a reset originating on the isolated
// (Domain B) side, e.g. a brief brownout of its own supply during a
// coil-switching event, WITHOUT needing a full ORC power cycle. Real
// hardware finding, 2026-08-10: chased on pca9555_bringup first (see that
// sketch's setChannel() for the full story) -- a PCA9555 power-on-reset
// reverts Config to 0xFF (all-input) and Output to its own 0xFF default
// (NXP datasheet POR value), silently, with I2C otherwise still ACKing
// fine.
//
// Write ORDER matters: Output MUST be re-written BEFORE Polarity/Config
// restore direction, not after. If direction flips back to output while
// the PCA9555's Output register still holds its stale post-reset 0xFF
// value, every Port0-mapped output channel would briefly drive HIGH the
// instant direction changes -- a real glitch on production relay-control
// firmware. Writing Output first means the register already holds the
// correct last-commanded value by the time direction is restored, so
// there's nothing to glitch to.
//
// Safe to call whether or not a reset actually happened -- idempotent if
// the PCA9555's real state already matched. Called both periodically (see
// loop()'s health-check block, so an idle period with no incoming command
// on either interface still self-heals) and on every applyRelayCommand()
// (so an active command self-heals immediately).
// BUG-005 fix: bail after the FIRST failed write instead of unconditionally
// issuing all six. Before this, once a health-check cycle began against a
// chip that had just gone unresponsive, all six ran even though the first
// failure already cleared g_pca9555Present -- each of the remaining five was
// another blocking I2C timeout for no benefit (this bug's shard's
// "mechanism 1"). Safe: pca9555WriteReg() already clears g_pca9555Present on
// any failure, so the next call into this function (or the lazy re-probe in
// requireRelayHardware()) picks up the absent state correctly either way --
// this only skips writes that would fail anyway once the first one has.
static void reassertPca9555State() {
  if (!g_pca9555Present) return;
  if (!pca9555WriteReg(kRegOutputPort0, g_relayPort0)) return;
  if (!pca9555WriteReg(kRegOutputPort1, g_relayPort1)) return;
  if (!pca9555WriteReg(kRegPolarityPort0, 0x00)) return;
  if (!pca9555WriteReg(kRegPolarityPort1, 0x00)) return;
  if (!pca9555WriteReg(kRegConfigPort0, kOrcPca9555ConfigPort0)) return;
  pca9555WriteReg(kRegConfigPort1, kOrcPca9555ConfigPort1);
}

static bool readAppliedMaskFromHardware(uint16_t &maskOut) {
  uint8_t port0 = 0, port1 = 0;
  if (!pca9555ReadInputPorts(port0, port1)) return false;
  maskOut = orcPca9555ToRelayMask(port0, port1);
  return true;
}

// Probes for the PCA9555 and, if it ACKs, runs the same output-configuration
// sequence setup() used to run unconditionally. Called once at boot and
// lazily (on demand) from requireRelayHardware() whenever g_pca9555Present
// is false -- ported from usb_bench/FR-001, ALSO now applied to the CAN
// side (handleRpdo1()), which never had lazy re-probe before this
// consolidation (BUG-001 only stopped it from halting the whole sketch, it
// never re-probed after boot).
static bool probeAndConfigurePca9555() {
  Wire.beginTransmission(kPca9555Addr);
  uint8_t probe = Wire.endTransmission();
  if (probe != 0) {
    g_pca9555Present = false;
    return false;
  }
  g_pca9555Present = true;
  // g_relayPort0/g_relayPort1 already hold the last-commanded state (0 at
  // boot; whatever the last real command was if this is a hot-plug
  // re-probe mid-session) -- reassertPca9555State() writes Output before
  // Config/Polarity, same glitch-avoidance ordering as every other call.
  reassertPca9555State();
  if (!g_pca9555Present) return false;  // reassertPca9555State() can clear it again on a write failure
  readAppliedMaskFromHardware(g_lastAppliedMask);  // baseline, avoids a spurious STATE burst on first command
  return true;
}

// BUG-005 fix: cooldown between lazy re-probe attempts. Root cause of the
// bug this guards against (docs/features/BUG-005.md's "mechanism 2", the
// dominant one): with no cooldown, EVERY RPDO1 frame reaching handleRpdo1()
// re-triggers a full blocking I2C probe once the PCA9555 is absent -- and
// because a stalled loop() lets RPDO1 frames pile up in the TWAI RX queue
// (the host keeps sending its ~1 Hz keepalive regardless), the NEXT loop()
// pass drains the whole backlog in one go, each frame re-triggering its own
// blocking probe. That is self-reinforcing: the more behind loop() falls,
// the more queued frames arrive to process next time, each adding another
// timeout -- closely matching the measured ~9.4x stall (25s capture, ~5
// frames deep on a tx_queue_len=5-class TWAI RX queue, times a
// multi-hundred-ms I2C timeout each, compounding). Capping re-probe attempts
// to at most one per kPca9555ProbeRetryIntervalMs, regardless of how many
// relay-touching calls arrive in that window, breaks the compounding
// entirely: worst case is one probe's timeout per window, not one per
// queued frame. Matches kHealthCheckIntervalMs's existing 1000ms cadence
// (the shard's own suggested direction: "gate ... on a much slower cadence
// while g_pca9555Present is false").
static unsigned long g_lastPca9555ProbeAttemptMillis = 0;
static const uint32_t kPca9555ProbeRetryIntervalMs = 1000;

// SET/GET/STATUS (USB) and RPDO1 (CAN) are the only things that legitimately
// need the PCA9555. Called first thing by each: if hardware was already
// known-present, this is a no-op check; if not, it makes one lazy live
// attempt before giving up -- rate-limited (see above) so a burst of calls
// while the chip is absent costs at most one blocking probe per cooldown
// window, not one per call.
static bool requireRelayHardware() {
  if (g_pca9555Present) return true;
  unsigned long now = millis();
  if (now - g_lastPca9555ProbeAttemptMillis < kPca9555ProbeRetryIntervalMs) {
    return false;  // still in cooldown from a recent failed probe
  }
  g_lastPca9555ProbeAttemptMillis = now;
  return probeAndConfigurePca9555();
}

// --- Diagnostic-print helper ---------------------------------------------------
// BUG-003 round 2 (2026-08-10): the TX-queue-backlog fix below (twaiSend())
// was a real, correctly-reasoned mechanism but NOT the actual cause of the
// 0.5s-cadence failures -- confirmed directly by a same-session A/B
// real-hardware test: identical firmware, identical randomized-RPDO1 sweep
// at 0.5s cadence, the ONLY difference was whether something was actively
// draining canopen_app's own USB-serial console while the test ran.
// Nothing draining it: 1/15 confirmed, TPDO1 stale/missing, zero
// Heartbeat/TPDO2 observed for the whole run. Something draining it
// (a second script reading COM6 concurrently): 15/15 confirmed, TPDO1
// arriving within single-digit milliseconds of every RPDO1, every single
// round. Same binary, same cadence, same bus -- the entire difference was
// serial backpressure.
//
// Real mechanism, found by re-reading HWCDC.cpp with this new evidence in
// hand: BUG-002's `Serial.setTxTimeoutMs(20)` fix bounded *each retry
// interval*, but `max_consec_timeouts` (HWCDC.cpp) is a HARDCODED constant,
// 20, not something that call adjusts -- so a single blocking
// `Serial` write's real worst case is `20 x 20ms = 400ms`, not the "~200ms
// (2 retries)" this file's own setup() comment mistakenly claimed before
// this fix (corrected there too). `handleRpdo1()` and `applyRelayCommand()`
// between them can issue several such calls per RPDO1 -- the RPDO1 log
// line, one `STATE` line per changed channel (up to 10), the backlog
// notice below -- and if console backpressure is present, EACH one can hit
// close to that 400ms ceiling, compounding across a single command to
// multiple seconds, with no recovery for the rest of a run because nothing
// ever drains the buffer in a CAN-only test session.
//
// Fix: `printBestEffort()` checks `Serial.availableForWrite()` first and
// skips the print entirely rather than blocking if there's no room --
// removing the hazard rather than further bounding it. Applied to the
// specific hot-path calls implicated by the A/B test (see call sites
// below); not a blanket replacement of every `Serial` call in this file
// (that's still open, same as BUG-002 left it -- see that bug's "options
// 2/3" for the fuller audit if this ever resurfaces on an ungated call).
//
// BUG-004 fix (2026-08-29, real hardware): the original guard checked
// `availableForWrite() > 0` -- room for at least 1 byte -- then handed the
// WHOLE string to Serial.print(), which commits to writing all of it. With
// BUG-002's setTxTimeoutMs(20), a write that didn't fully fit timed out
// partway through and the remainder (trailing \n included) was silently
// dropped, gluing the truncated line onto whatever the next Serial call
// wrote -- observed corrupting Heartbeat lines whenever the backlog notice
// below fired (CAN backed up/disconnected), making passive HB parsing
// 100% non-functional on the rigos-core host side. Compare against
// strlen(s) instead, so a message that won't fit cleanly is dropped
// ENTIRELY rather than partially -- a missing line is recoverable (the
// next periodic broadcast self-corrects), a corrupted one poisons
// whatever comes after it too. See docs/features/BUG-004.md.
static void printBestEffort(const char *s) {
  size_t len = strlen(s);
  if (Serial.availableForWrite() >= (int)len) {
    Serial.print(s);
  }
}
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
void loop() {
  pollUsbSerial();

  if (g_canAvailable) {
    twai_message_t msg;
    // Non-blocking receive -- 0 ticks timeout, drain whatever's queued this
    // pass without stalling the periodic TPDO2/Heartbeat/timeout checks below.
    while (twai_receive(&msg, 0) == ESP_OK) {
      handleIncomingFrame(msg);
    }
  }

  checkControlActivityTimeout();

  unsigned long now = millis();
  if (now - g_lastHealthCheckMillis >= kHealthCheckIntervalMs) {
    checkTwaiRecovery();
    // Self-heal a PCA9555 that lost its config to an isolated-side reset
    // during an idle period (no command on either interface to trigger the
    // same recovery via applyRelayCommand()) -- see reassertPca9555State().
    reassertPca9555State();
    g_lastHealthCheckMillis = now;
  }
  if (g_canAvailable && now - g_lastTpdo2Millis >= g_tpdo2IntervalMs) {
    sendTpdo2();
    g_lastTpdo2Millis = now;
  }
  // One shared 1000ms cadence for both heartbeat emitters: the CAN
  // heartbeat (only if g_canAvailable) and the USB HB line (always). Both
  // read/reset the SAME g_lastHeartbeatMillis in one block -- keeping them
  // in two separate if-blocks each gated on their own copy of the same
  // condition was a real bug caught before flashing: if g_canAvailable was
  // false, a CAN-only-gated block would never update the timestamp, and an
  // unconditional USB-only block reading that same stale timestamp would
  // fire on every single loop() iteration once 1000ms had first elapsed --
  // flooding "HB" lines instead of one per second.
  if (now - g_lastHeartbeatMillis >= kHeartbeatIntervalMs) {
    if (g_canAvailable) {
      sendHeartbeat(ORC_NMT_OPERATIONAL);
    }
    Serial.printf("HB %lu\n", now);
    g_lastHeartbeatMillis = now;
  }
}

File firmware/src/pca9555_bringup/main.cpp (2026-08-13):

// SPDX-License-Identifier: Apache-2.0
// Copyright (c) 2026 Aram Dergevorkian
// ORC firmware bring-up: PCA9555 I2C GPIO expander
//
// NOT application firmware -- no relay control logic here. Configures the
// PCA9555 (NXP, address 0x20, A0-A2 strapped low) as 10 outputs matching
// docs/subcircuit-capture-guide.md's documented usage (10 of 16 I/O used),
// then walks a single HIGH bit across those 10 channels in sequence so a
// scope or a per-channel LED jig can visually confirm addressing and pin
// mapping once real hardware exists.
//
// Channel-to-register mapping -- CORRECTED 2026-08-05 against the real
// schematic. An earlier version of this sketch assumed channels 1-8 were
// sequential on Port0 (whole byte) and channels 9-10 on Port1's low 2 bits,
// per a 2026-08-01 ERC-findings note that only established WHICH 10 pins
// were used, not which channel maps to which pin. That assumption was
// WRONG: docs/subcircuit-capture-guide.md's "Channel mapping" table (read
// directly off hardware/i2c_expander.kicad_sch, 2026-08-04) shows the real
// mapping is routing-driven, not sequential -- e.g. channel 1 is Port1 bit0,
// channel 2 is Port0 bit7, channel 10 is Port0 bit3, and so on, spanning
// both ports non-contiguously. The real mapping now lives in
// firmware/lib/orc_relay_map/ -- this sketch uses it directly rather than
// hand-rolling a second (and previously wrong) copy. If you're using this
// sketch's walking pattern with a scope or an LED jig, "channel 3" printed
// here now means the actual schematic's channel 3, not a guess.
//
// Nothing here has been run against real hardware. Compiles cleanly against
// the esp32-c3-devkitm-1 stand-in board definition; ready to flash once a
// real "Super Mini"-class board and a PCA9555 are in hand.

#include <Arduino.h>
#include <Wire.h>
#include "orc_can_addr.h"
#include "orc_relay_map.h"

static const uint8_t kSdaPin = ORC_I2C_SDA_PIN;
static const uint8_t kSclPin = ORC_I2C_SCL_PIN;
static const uint8_t kAddr = ORC_PCA9555_ADDR;

// PCA9555 register map (NXP datasheet, command byte values)
static const uint8_t kRegInputPort0 = 0x00;
static const uint8_t kRegInputPort1 = 0x01;
static const uint8_t kRegOutputPort0 = 0x02;
static const uint8_t kRegOutputPort1 = 0x03;
static const uint8_t kRegPolarityPort0 = 0x04;
static const uint8_t kRegPolarityPort1 = 0x05;
static const uint8_t kRegConfigPort0 = 0x06;
static const uint8_t kRegConfigPort1 = 0x07;

// Config values: kOrcPca9555ConfigPort0/Port1, from lib/orc_relay_map/ --
// see that lib for the real bit-by-bit reasoning (3 non-contiguous spare
// bits per port, not "channels 9-10 only used on Port1" like this sketch
// used to assume).

static const uint8_t kNumChannels = 10;

static bool writeReg(uint8_t reg, uint8_t value) {
  Wire.beginTransmission(kAddr);
  Wire.write(reg);
  Wire.write(value);
  uint8_t result = Wire.endTransmission();
  if (result != 0) {
    Serial.printf("  I2C write FAILED (reg 0x%02X, val 0x%02X): endTransmission=%u\n",
                  reg, value, result);
    return false;
  }
  return true;
}

// Writes direction (Config) and polarity registers -- the two registers
// that define "which pins are outputs" and "not inverted." Called once at
// boot AND on every setChannel() call below -- see that function's comment
// for why the repeat isn't paranoia.
static void configurePca9555Direction() {
  writeReg(kRegPolarityPort0, 0x00);
  writeReg(kRegPolarityPort1, 0x00);
  writeReg(kRegConfigPort0, kOrcPca9555ConfigPort0);
  writeReg(kRegConfigPort1, kOrcPca9555ConfigPort1);
}

// Drive channel `ch` (1-10) HIGH, all other 9 channels LOW. Uses the real
// routing-driven map from lib/orc_relay_map/, not a sequential assumption.
//
// Real-hardware finding and root-cause chase, 2026-08-10, first ORC PCB
// tested, once it was mounted in its enclosure:
// 1. Exactly one relay ever clicked, ever -- including on later loop
//    passes back through the same channel -- until the board was fully
//    power-cycled, at which point exactly one more click happened before
//    going silent again. I2C itself looked perfectly healthy throughout
//    (every write ACKed, zero "I2C write FAILED" prints) -- the working
//    theory at the time was a PCA9555 power-on-reset silently reverting
//    its direction back to all-input, with subsequent Output writes still
//    ACKing but having no physical effect. Re-issuing Config/Polarity
//    every step (this function, called from every setChannel()) was added
//    to self-heal that scenario if it recurred.
// 2. That change immediately surfaced a SECOND symptom: I2C writes started
//    failing with driver-level ESP_ERR_INVALID_STATE errors instead of
//    ACKing. A manual I2C bus-recovery routine (bit-banged SCL clock-out +
//    forced STOP + Wire re-init) was tried here and REMOVED again the same
//    session -- real-hardware testing showed every retry failed
//    identically right after "recovery," meaning Wire.end()/Wire.begin()
//    doesn't cleanly tear down and rebuild this Arduino-ESP32 core's newer
//    i2c_master ("i2c-ng") driver state. Left in, it would have been
//    broken code claiming success it didn't have -- worse than not having
//    it. If real I2C bus recovery is needed here in the future, it needs a
//    driver-level fix (or a full ESP.restart()), not this approach.
// 3. Root cause, found by physical inspection, same session: **the
//    board's output-connector through-hole pins were shorting to the
//    enclosure chassis.** That explains both symptoms as one electrical
//    fault, not two separate bugs: the short pulled down shared supply
//    rail(s) hard enough under coil-switching current to both starve the
//    coil drive (user-reported "very quiet actuations, not enough to close
//    the contacts") and glitch the PCA9555's own logic supply, corrupting
//    I2C transactions. Confirmed as the real cause, not firmware, not a
//    coil-supply sizing problem -- see docs/circuit-draft.md and
//    docs/design-inputs.md for the mechanical-clearance follow-up this
//    should turn into (standoff/insulation/enclosure-fit, not a schematic
//    change).
//
// configurePca9555Direction() being called every step is left in place as
// cheap, harmless defense-in-depth against a future transient brownout of
// whatever cause -- it did not cause and does not fix the short above.
static void setChannel(uint8_t ch) {
  configurePca9555Direction();

  uint16_t channelMask = (uint16_t)(1u << (ch - 1));
  uint8_t port0 = 0x00;
  uint8_t port1 = 0x00;
  orcRelayMaskToPca9555(channelMask, port0, port1);

  writeReg(kRegOutputPort0, port0);
  writeReg(kRegOutputPort1, port1);
}
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

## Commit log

2026-08-01 ORC: open replacement controller for the Motorola PMUN1046A relay box
    Project repo for design inputs, specs, and architecture decisions.
    Implementation splits into orc-hardware (KiCad) and orc-firmware
    (PlatformIO) as those start.
    Carries forward the mechanical RE from PMUN1046A_RE: what the donor unit
    contributes (passive relay board, harness, sealed chassis), what has to be
    rebuilt (9 V coil supply, ten drivers, input protection), the open
    architecture decisions (isolation, primary control path, antenna), and the
    bench measurements that gate layout.
2026-08-01 Correct input protection framing; note the board carries no high-current path
    The 60A/16A/15A figures describe three different things, not a
    contradiction: input path capability, Motorola's specified external
    breaker, and the per-output fuse. The breaker is vehicle-side hardware, so
    input protection is an installation choice, not an ORC board concern.
    Also states plainly that load current never touches the controller PCB — it
    runs busbar to relay contact to fuse on the passive relay board. ORC needs
    only a low-current A+ tap for the 9 V coil supply and logic, which
    substantially bounds the input design.
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2026-08-01 Fix real ERC errors: PWR_FLAG net collision and stray FB_B/COIL_9V label
    Two genuine schematic-integrity bugs found via connectivity-graph analysis,
    not just ERC noise:
    1. All 6 PWR_FLAG symbols (PF1,3,5,6,7,8) shared the default Value
    "PWR_FLAG". In KiCad a power symbol's Value field IS its net name, so
    all six were silently the same net despite each being wired to a
    different, correctly-labeled rail (GND_A, GND_B, 3V3_A, VIN_BUCK_A,
    COIL_9V, V_COIL_IN). This shorted Domain A ground to Domain B ground
    on paper -- defeating the ADuM1250 isolation barrier's entire purpose
    -- plus 3V3_A/VIN_BUCK_A/COIL_9V all together. Fixed by giving each
    PWR_FLAG a unique Value (PWR_FLA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
    [orc.kicad_sch]
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2026-08-01 Fix stacked-label readability via sch_resolve_label_overlaps
    Connectivity-safe justify flip on 3 overlapping label pairs (GND_A,
    VIN_BUCK_A, V_PROT_A/VIN_BUCK_A) -- text-only, label anchors (the actual
    electrical attachment points) untouched. Verified: sch_visual_qa still
    reports these as WARN afterward because same-name label stacking at
    0.00mm is a pre-existing display quirk in how this schematic was
    originally generated, not something this fixer's job covers -- it fixes
    readable-text overlap, not anchor-coincidence. No regression either way,
    purely cosmetic.
    Last commit of the automated session -- pausing KiCad-MCP-driven
    schematic work here per user direction; remaining work (footprint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
    [orc.kicad_sch]
2026-08-01 Reconcile BOM against live schematic, add subcircuit capture guide
    BOM.md was stale -- generated from an earlier schematic snapshot before
    several values were corrected directly in KiCad (L1/L2 33uH->68uH,
    D3/D5 SS34->SS56, C1/C11 100uF->47uF, FB divider resistors, etc.).
    Rewrote it against a fresh export_bom pull, merged in every LCSC
    sourcing decision from circuit-draft.md that the old BOM was missing
    (CIN/COUT/bypass/CFF part numbers for both buck instances), and added
    a dedicated section flagging the 4 items that need real KiCad
    symbol/footprint work (D6/PESD1CAN has no symbol at all, U1 needs the
    -1U footprint swapped in, J5 and F1/F2 footprints worth double-checking)
    separately from or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
2026-08-01 Commit KICAD_MCP_PROFILE=agent_full, ignore output/ export artifacts
    .mcp.json's profile flip (default -> agent_full) was the second of two
    env vars needed for the KiCad MCP write path to actually work -- mode
    alone (already committed at 2f6dc68) isn't sufficient, the profile
    gates which tools the client can even see. Needed on any machine
    resuming this KiCad MCP session; see kicad-mcp-logbook.md for the full
    diagnostic trail on why both are required.
    hardware/output/ (debug SVG/PNG/CSV exports from various *_render and
    export_* tool calls this session) is regenerable, not authoritative --
    gitignored going forward. Leaves already-tracked erc_report.json alone.
2026-08-01 Track kicad-mcp-logbook.md across machines; keep rest of .claude/ local
    Carved out an explicit gitignore exception -- .claude/ stays local
    machine state (settings.local.json, worktrees) but the logbook is
    genuine project history (root-cause diagnosis for the write-pipeline
    blocker, the PWR_FLAG net-collision finding, the unresolved
    COIL_9V/GND_B investigation trail) that needs to travel with the repo
    so KiCad MCP work can resume with full context on another machine.
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2026-08-02 Retire hardware/BOM.md, consolidate into subcircuit-capture-guide.md
    BOM.md had drifted out of sync with the new 5-sheet hierarchy's ref
    numbering and contradicted itself on the catch-diode value (SS34 vs
    SS56) -- redundant and actively confusing alongside the sheet-organized
    capture guide. Folded everything still current (parts tables, tier
    caveats, pending KiCad edits, footprint work-items) into
    subcircuit-capture-guide.md, now the single source of truth.
    Also: locked QN1-10 to MMBT3904/C20526 (Basic-tier preference over the
    literal MMBT2222A), sourced replacements for the 68uH inductor (SXN
    SMDRI127-680MT/C9907, far deeper stock than the prior 194-unit pick),
    the PCA9555PW I2C expander (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
2026-08-02 Source USB-C CC pull-downs and confirm CAN terminal part
    - R11/R12 USB-C CC1/CC2 Rd pull-downs sourced to YAGEO RT0402BRD075K1L, 5.1k 0402 0.1%, C852856.
    - J5/J6 DC+CAN 5.08mm 4-pos screw terminal confirmed as DORABO DB128L-5.08-4P-GN-S, C2827883; the previously-flagged stray root number is verified correct. Updated the capture-guide table, Housekeeping note, and BOM housekeeping item.
    Hardware:
    - mcu.kicad_sch, orc.kicad_pcb/pro/sch schematic edits.
    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
    [mcu.kicad_sch, orc.kicad_pcb, orc.kicad_sch]
2026-08-02 Resolve SW1 as EN/reset, add GPIO0/BOOT button (SW2)
    SW1 confirmed by user as the ESP32-S3 EN/reset button -- verified live
    against the schematic (EN_A has pull-up+pin+SW1, GPIO0_A only has
    pull-up+pin, confirming no boot-mode-select button existed). EN alone
    can't force bootloader/download mode; added SW2 on GPIO0_A as recovery
    insurance for this sealed-enclosure board. Both use XKB Connection
    TS-1187A-B-A-B (C318884), verified live: SMD-4P 5.1x5.1mm, -30 to
    +85degC, 1.07M in stock.
2026-08-02 Flag USB-vs-CAN interface decision as reopened, not locked
    8.5mm board-to-board clearance can't fit both the USB-C connector and
    the DC+CAN screw terminal. Direction under consideration: drop the
    custom USB-C/ESD/CC-pulldown circuit (U7/J4/U5/R11/R12), replace with a
    pre-made ESP32-S3 module (USB-C for programming only), CAN becomes
    primary. Flagged as open in circuit-draft.md and
    subcircuit-capture-guide.md -- don't source or lock those refs further
    until a module is picked. Research on real candidates dispatched.
2026-08-02 Descope wireless entirely, confirm ESP32-C3 as MCU chip family
    Two decisions landed together, replacing the S3-module search:
    - No WiFi/BLE at all -- CAN becomes the sole control path. Retires
    design-inputs.md's external-antenna requirement outright (radio
    never enabled in firmware, sealed-enclosure PCB-antenna problem no
    longer applies).
    - ESP32-C3 (single-core RISC-V) confirmed adequate -- actual workload
    is just CAN in + drive the PCA9555 I2C expander out through the
    isolator, never needed S3's dual-core or PSRAM.
    Verified before committing to this direction that the plain "Super
    Mini" boards the user proposed would otherwise have been disqualified
    on antenna (and the S3 varian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
2026-08-02 Replace RB/RP discrete 10k resistor banks with a shared Basic array
    Rejected the pre-biased-NPN (digital transistor) route on economics --
    best in-stock candidate (onsemi MMUN2211LT3G) never got a confirmed
    Basic tier, and an unconfirmed swap risks a real $3/order Extended
    reel-loading fee against parts that are already Basic and loaded.
    Found a better answer for the same area-saving goal: UNI-ROYAL
    4D03WGJ0103T5E (C29718), isolated 4x10kOhm array, 0603x4, confirmed
    genuinely Basic via a maintained JLCPCB Basic-parts CSV listing (tagged
    "Very popular") rather than the usual circumstantial stock-depth read
    -- first non-circumstantial tier confirmation all session. Covers both
    RB1-10 and RP1-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
2026-08-02 Drop BAT54C, reuse SS34/C8678 for the flyback diode
    BAT54C failed every tier check today (neither listing appears in two
    independent JLCPCB Basic-parts lists; the "safe" SS14 fallback turned
    out explicitly tagged Extended in one). Reused SS34/C8678 instead --
    already committed to the BOM for D3/D5/D6, so zero incremental
    reel-fee risk regardless of its own tier, unlike any new diode number.
    Trade-off: back to SMA package, giving up BAT54C's SOT-23 footprint
    win.
    Added the underlying principle to hardware-workflow.md's Gate 1 notes:
    reel-fee risk is asymmetric between an already-committed part (free to
    reuse) and a new tier-unconfirmed one (real risk), and a maintained
    Basic-parts CSV is rea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
2026-08-02 Add firmware/ IO-level bring-up sketches, resolve GPIO9 strapping question
    Datasheet-grounded analysis (Espressif ESP32-C3 datasheet v2.4, TI
    SN65HVD230 datasheet SLOS346O) confirms the current I2C-on-GPIO8/9
    pin assignment is safe against the BOOT strap read -- no schematic
    change needed. Adds three separate PlatformIO bring-up sketches
    (I2C scanner, PCA9555 walking-pattern test, UART/CAN-transceiver
    loopback test) against an esp32-c3-devkitm-1 stand-in board.
    Build-verified all three, then flashed and ran i2c_scanner and
    uart_can_bringup live on a bare ESP32-C3 dev kit, confirming the I2C
    and UART peripherals work on real silicon and verifying UART loopback
    end-to-end. Found and fixed a r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
    [main.cpp]
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2026-08-03 Switch buck supply to LMR50410, all-ceramic/Basic-tier passives, board ordered from JLC
    Board-space constraint ruled out the LM2596/TO-263 design; replaced with
    LMR50410 (SOT-23-6, synchronous, ceramic-only COUT, no feedforward cap)
    after an intermediate LMR33630 pick. Sourced a shared 33uH inductor sized
    against a revised 0.7A coil-rail load, and an all-Basic-tier feedback
    resistor set for both the 3.3V and 9V dividers. Closed out the Domain B
    logic-supply LDO sourcing (U6/AMS1117-3.3) and the CIN/COUT consolidation
    history in circuit-draft.md and subcircuit-capture-guide.md.
    Also cleans up tracked-but-regenerable KiCad output: untracks
    hardware/output/*.json reports (rule predated their c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
    [communications.kicad_sch, i2c_expander.kicad_sch, i2c_isolator.kicad_sch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]
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2026-08-05 Correct CAN node-address pins to match as-fabbed schematic (GPIO0-3, not GPIO0/1/3/10)
    The board was already sent to fab wired with NODE_ID0..NODE_ID3 on a
    contiguous IO0-IO3 block -- not the GPIO0/1/3/10 pin set picked a few
    hours earlier specifically to avoid GPIO2 (a strapping pin). Since the
    PCB isn't editable, re-verified GPIO2 with real rigor rather than
    treating it as a design tradeoff: Espressif's ESP32-C3 datasheet Table
    3-3 shows GPIO2 is don't-care whenever GPIO9=1, and this board's own
    I2C pull-up (R21) guarantees GPIO9=1 at every reset, so neither
    address-switch position on GPIO2 can affect boot mode. No relevant
    errata found. Safe as fabbed, no rework needed.
    Corrected firmwar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
    [main.cpp]
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2026-08-05 Close out CAN node-address doc trail, flag bus bitrate as still open
    circuit-draft.md: records the GPIO0/1/3/10 -> GPIO0-3 as-fabbed
    correction with the independent re-check of the GPIO2 datasheet claim
    (tooling in this session couldn't re-render Table 3-3 directly; the
    GPIO9-dominant mechanism is well-corroborated elsewhere, but the exact
    table cell wasn't independently reproduced this pass -- real hardware
    test of both DIP-switch positions on NODE_ID2 remains the decisive
    check). Closes out the PCA9555 pin-budget and GPIO-pick open items,
    adds a real-hardware-confirmation open item in their place.
    subcircuit-capture-guide.md: superseded the stale 2026-08-02 node-ID
    GPIO note with a pointe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
2026-08-05 Add canopen_app: ORC's first application firmware (real CANopen relay control)
    Implements the full protocol from docs/can-protocol-research.md on top
    of the existing IO-level bring-up work: native TWAI transport at
    125 kbit/s (superseding uart_can_bringup's raw-UART scheme for this
    firmware, which stays as its own separate bring-up environment),
    node-ID addressing via lib/orc_can_addr unchanged, RPDO1/TPDO1 relay
    command/status, TPDO2 bus-health/uptime telemetry, Heartbeat, and one
    hand-rolled SDO object (1801h/5, TPDO2's event timer) with NVS
    persistence. Includes the RPDO1-timeout de-energize-all fail-safe the
    protocol doc recommends.
    Verified both items the protocol doc flagged as unchec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
    [main.cpp]
2026-08-05 Resolve canopen_app's open items in docs, note SN65HVD230 bitrate lock
    can-protocol-research.md: resolves TPDO2's two previously-flagged
    design-sketch items (controller-state enum, error-counter width) with
    citations against ESP-IDF's real driver/twai.h, confirming rather than
    correcting the original proposal.
    subcircuit-capture-guide.md: closes the PCA9555 channel-mapping open
    item -- now implemented in firmware/lib/orc_relay_map/ and used by both
    pca9555_bringup and canopen_app.
    circuit-draft.md: notes the SN65HVD230 BOM line now carries the locked
    125 kbit/s bus bitrate and the ISO 11898-2-vs-11898-3 naming caveat.
    kicad-mcp-logbook.md: two dated entries -- canopen_app's build, and the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
2026-08-05 Review canopen_app: fix uptime wraparound and add TWAI bus-off recovery
    Independently re-verified the prior commits' ESP-IDF citations (twai_state_t's
    4-state enum, error-counter field types) against Espressif's real docs -- both
    checked out. Found and fixed two real gaps the review surfaced:
    - TPDO2's uptime field used millis() (32-bit ms, wraps ~49.7 days), silently
    defeating its own documented 136-year-headroom design rationale on any
    continuously-powered unit. Switched to esp_timer_get_time() (64-bit
    microseconds-since-boot), which has no comparable wraparound concern.
    - No TWAI bus-off recovery existed anywhere: the health enum correctly
    detected and reported BUS_OFF/RECOVERING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
    [main.cpp]
2026-08-06 Add FR-001: USB bench/debug interface firmware (usb_bench)
    Implements docs/usb-bench-interface-spec.md's plain-ASCII CDC-ACM relay
    control interface over ORC's native USB-C port -- a bench/dev tool
    alongside canopen_app, not a replacement for the CAN-exclusive production
    control path. Reuses lib/orc_relay_map/'s schematic-confirmed channel
    mapping unchanged.
    Decides the spec's one open question (idle-timeout fail-safe): de-energize
    after 30s of no host activity, for philosophical consistency with CAN's
    own RPDO1-timeout, but longer than CAN's 5s since this is a human-typed
    interactive interface. Recorded in the spec, the FR shard, and the README.
    Also introduces docs/features/ as this repo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
    [main.cpp]
2026-08-06 Resolve flyback-diode open item: relay board has no internal diodes
    User confirmed by direct physical inspection of the relay board -- no
    internal flyback diodes present. ORC's control board must supply one per
    coil (x10). Reuses SS34 (C8678), already qualified for the buck
    catch-diode role, per the existing diode-consolidation reasoning -- no new
    part number. Added BOM row 3d; schematic placement still open.
    Coil-drive-side reverse-polarity P-FET (#5b) remains unresolved -- a
    sourcing pass was started and interrupted, no part selected.
2026-08-06 Fix FR-001 reopen: usb_bench halted before PING was reachable
    rigos-core's real-hardware test (Pi flashing usb_bench onto a bare
    ESP32-C3 devkit, no PCA9555) found setup() halted the whole sketch if the
    PCA9555 didn't ACK -- taking PING/VERSION/framing down with it, not just
    the commands that actually need relay hardware. Defeated the firmware's
    own stated purpose of being usable before full ORC hardware exists.
    Fix: g_pca9555Present flag replaces the halt. setup() always reaches
    loop(). SET/GET/STATUS lazily re-probe on demand via
    requireRelayHardware() and return ERR NO_RELAY_HARDWARE if still absent,
    rather than hanging or reusing a generic I2C error. A mid-session I2C
    failure on previou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
    [main.cpp]
2026-08-06 Fix BUG-001: canopen_app halts before joining the CAN bus if PCA9555 absent
    Same bug shape as FR-001's usb_bench reopen, found deliberately looking for
    it afterward. setup() used to hard-halt on a missing PCA9555 BEFORE
    twai_driver_install()/twai_start() ever ran, taking the whole CAN node
    dark - no heartbeat, no TPDO2 health report - on an I2C fault. Worse than
    usb_bench's case since this is the real production control path.
    g_pca9555Present flag replaces the halt; TWAI/heartbeat/TPDO2/SDO come up
    regardless. handleRpdo1() checks the flag before attempting I2C, avoiding
    a doomed write on every RPDO1 when hardware is absent.
    [main.cpp]
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2026-08-11 relay_toggle_test.py: sweep 1-10 then all-on, instead of per-channel on/off
    Fixed demo/test sequence: walk channels 1-10 one at a time (1s each,
    exclusive -- only that channel on per step, same pattern
    pca9555_bringup's own bring-up walk uses), pause all-off, command all 10
    channels on at once, pause, then all-off cleanup on exit (including on
    Ctrl+C). Still confirms every step via real TPDO1 readback, same as
    before -- exit code reflects whether every step's confirmation matched.
    Replaces the old --channel-num/--hold-seconds single-channel-at-a-time
    round trip with --sweep-seconds/--pause-seconds tuning the new fixed
    sequence. Added ALL_CHANNELS_MASK to orc_canopen.py for the all-on step.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
    [orc_canopen.py, relay_toggle_test.py]
2026-08-11 Add startup status poll + stale-frame drain, verified against real hardware
    Real-hardware finding: a board at node ID 0 (all DIP switches open) stays
    completely silent on the bus -- no Heartbeat -- until something is first
    sent to it. Both scripts now send one SDO read (object 1801h/5, TPDO2's
    event timer -- harmless, doesn't touch relay state) at startup for exactly
    that reason, skippable with --no-poll. Added the SDO read/response codec
    and ALL_CHANNELS_MASK-adjacent node-ID-0 support to orc_canopen.py.
    Also added drain_stale_frames(): a fresh session opened against an adapter
    whose prior session was killed uncleanly (hard timeout instead of
    bus.shutdown()) can inherit a buffered backlog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
    [can_monitor.py, orc_canopen.py, relay_toggle_test.py]
2026-08-11 FR-004: consolidate USB control into canopen_app; BUG-001/002/003 real-hardware bring-up
    First real-hardware bring-up session against fabricated ORC PCBs. Consolidates
    usb_bench into canopen_app so relays are drivable from CAN or USB against the
    same PCA9555 state (FR-004), retiring the standalone usb_bench sketch.
    Real-hardware bugs found and fixed on real boards:
    - BUG-001: canopen_app halted before joining the CAN bus if the PCA9555
    never ACKed, taking heartbeat/TPDO2 dark on an I2C fault.
    - BUG-002: TPDO1 confirmation could lag or drop because a diagnostic
    Serial.printf() ahead of the send could block up to 2s on native
    USB-CDC; fixed with Serial.setTxTimeoutMs(20).
    - BUG-003: sub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
    [main.cpp, relay_toggle_test.py]
2026-08-11 Clean up README for public visibility; fix harness/date factual errors
    README.md: correct controller (ESP32-S3 -> ESP32-C3), remove references to
    the archival PMUN1046A_RE reverse-engineering repo, clarify the donor unit's
    power-input path (busbar via cable glands, up to 120A across two cables per
    Motorola's install manual, not a flat 60A limit) versus the internal
    board-to-board coil-drive harness (0975931M01, carries switched 9V coil
    drive between the relay board and controller board, not power). Rewrote the
    repo structure and status sections to reflect real hardware bring-up instead
    of the pre-schematic state.
    Corrected several mis-dated events across docs/circuit-draft.md,
    subcircuit-ca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
    [main.cpp]
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2026-08-30 feat(canopen): FR-005 table-driven SDO object dictionary
    Replace orcHandleSdoRequest()'s hard-coded single (index, sub-index)
    if-chain with a table of OrcSdoObject rows (index/sub-index/size/
    access/read+write accessors). 1801h/5 (TPDO2 event timer) becomes the
    table's first row with unchanged wire behavior. Accessors return bool
    so a read/write can fail and abort (0x06060000) instead of returning a
    fabricated value -- needed by FR-003's live-I2C object. Preserves the
    existing index-vs-sub-index abort code split (0x06020000 vs
    0x06090011) and adds access-mismatch aborts (0x06010002/0x06010001).
    Adds a boot-time self-test (runSdoHwFailureSelfTest) demonstrating the
    failing-accessor path agai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
    [main.cpp]
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2026-08-30 fix(canopen): BUG-004 printBestEffort truncation glues HB lines onto backlog notices
    File BUG-004: printBestEffort() commits to partial Serial writes,
    gluing a truncated diagnostic onto the next protocol line and
    silently killing Heartbeat parsing on the host side (found by
    rigos-core, real hardware, 2026-08-29).
    Hardened printBestEffort() to compare availableForWrite() against
    strlen(s) and drop the whole message rather than commit to a partial
    write -- real defense-in-depth, but real-hardware testing showed this
    alone did NOT clear the symptom (glue was still 100% present,
    byte-identical, after this fix alone).
    Actual root cause: twaiSend()'s backlog-notice snprintf formats to
    143 chars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
    [main.cpp]
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2026-08-31 FR-002: report relay-hardware presence over CAN (TPDO2 byte-7)
    Prompted by a real rigos-core stress test: disconnecting the ORC's
    relay-power rail (B+_TAP, feeding both the isolated PCA9555 domain and
    the relay bus bar) never stopped the heartbeat, because the ESP32/CAN
    side runs on a separate supply. The node kept reporting perfectly
    healthy while its relay driver was completely dead - a fault class no
    heartbeat-based host check can ever catch.
    TPDO2 byte-7 (previously reserved, always 0) now carries an
    OrcRelayFault bitmask mirroring the existing g_pca9555Present flag
    (BUG-001/FR-001's lazy re-probe) - no new fault detection, just a new
    way to report a condition already tracked. Reported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
    [can_monitor.py, main.cpp, orc_canopen.py]
2026-09-05 fix(canopen): BUG-005 rate-limit PCA9555 lazy re-probe, bail-early reassert
    Targets the dominant of the three suspected contributors in the shard:
    requireRelayHardware() re-probed I2C on every RPDO1 frame once the
    PCA9555 was known absent, and a stalled loop() lets RPDO1 frames back
    up in the TWAI RX queue (host keeps sending its ~1 Hz keepalive
    regardless) -- the next loop() pass then drains the whole backlog in
    one go, each frame re-triggering its own blocking probe. Self-
    reinforcing, matching the measured sustained ~9.4x slowdown better
    than the other two (one-shot) suspects.
    - requireRelayHardware(): 1000ms cooldown between lazy re-probe
    attempts (kPca9555ProbeRetryIntervalMs), track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
    [main.cpp]
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
